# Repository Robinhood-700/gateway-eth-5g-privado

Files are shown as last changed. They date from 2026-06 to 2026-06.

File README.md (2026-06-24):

# Gateway privado Ethernet-5G
Este proyecto contiene el diseño del PCB para la implementación de un gateway privado ethernet-dect, además del firmware correspondiente y un firmware simulado. Además contiene en la carpeta "resultados" la salida del proceso de build, flash y la ejecución del programa.
## Build
A continuación se describe el procedimiento para hacer el build del proyecto.
1. Cambiar de directorio a la carpeta padre del firmware:
```
// (desde la carpeta padre del proyecto)
cd firmware/esp32_gateway 
```
2. Activar el entorno ESP-IDF:
```
// En mi caso instalado en /opt. Cambia al directorio correspondiente $ESP_DIR
source /opt/esp/esp-idf/export.sh 
```
3. Realizar el comando build:
```
idf.py set-target esp32
idf.py reconfigure
idf.py fullclean build
```
### Para guardar el build en un archivo
Para guardar la salida del build en un fichero de texto, simplemente hice un pipe de la salida a un nuevo archivo .txt:
`idf.py fullclean build >> resultado_build.txt`
## Flash
1. Repetir pasos 1 y 2 del proceso build si no se ha ejecutado
```
// (desde la carpeta padre del proyecto)
cd firmware/esp32_gateway 
// En mi caso instalado en /opt. Cambia al directorio correspondiente $ESP_DIR
source /opt/esp/esp-idf/export.sh 
idf.py set-target esp32
idf.py reconfigure
```
2. Realizar el flash
```
// En el caso de mi portatil y la placa de desarrollo ESP32-Ethernet-Kit v1.2, el puerto es el
// /dev/ttyUSB1 y según la documentación de espressif, 115200 es el valor de baudios adecuado
idf.py -p /dev/ttyUSB1 -b 115200 flash monitor
// Este comando concatena el comando monitor con el flash para poder visualizar inmediatamente los resultados en pantalla.
```
### Para guardar el flash en un archivo
Igual que el build, simplemente hace falta un pipe en una terminal de bash:
`idf.py -p /dev/ttyUSB1 -b 115200 flash >> resultado_flash.txt`
### Para guardar la ejecución del programa en un archivo
`idf.py -p /dev/ttyUSB1 -b 115200 monitor >> resultado_monitor.txt`

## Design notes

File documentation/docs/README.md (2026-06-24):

# ESP32 <-> nRF9151 Gateway MVP (KiCad + Firmware minimo)

## Estado
- Proyecto KiCad 9 creado en formato `70 x 50 mm`.
- Esquematico jerarquico con PoE + ESP32 + W5500 + nRF9151.
- Hoja USB integrada: `usb_pc_iface.kicad_sch` (USB-C + CP2102N + auto-programacion).
- Seleccion fisica UART/SPI para nRF9151 por jumpers.
- Definicion minima de puerto USB-C para PC (power + UART + auto-programacion).
- ERC actual del esquema: `0 violaciones`.

## Entregables
1. Hardware minimo: `01_HARDWARE_MIN.md`
2. Pinmap minimo: `02_PINMAP_MIN.md`
3. Firmware minimo (modulos y archivos): `03_FIRMWARE_MIN.md`
4. Kconfig/sdkconfig minimo: carpeta `../../Hardware/firmware/esp32_gateway`
5. Build/flash: `04_BUILD_FLASH.md`
6. Validacion E2E: `05_VALIDACION_E2E.md`
7. Puerto USB PC minimo: `06_USB_PC_PORT_MIN.md`
8. Paquete release KiCad: `../../Hardware/release/README.md`

## Arbol principal
- `../../Hardware/esp32_eth_dect_nrf9151_gateway_min.kicad_sch`
- `../../Hardware/power_poe.kicad_sch`
- `../../Hardware/esp32_eth.kicad_sch`
- `../../Hardware/nrf9151_iface.kicad_sch`
- `../../Hardware/usb_pc_iface.kicad_sch`
- `../../Hardware/esp32_eth_dect_nrf9151_gateway_min.kicad_pcb`
- `../../Hardware/firmware/esp32_gateway`

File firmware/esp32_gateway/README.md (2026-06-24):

# ESP32 Gateway Firmware (Ethernet <-> DECT NR+)

Firmware MVP en ESP-IDF para pasarela bidireccional:
- Ethernet (W5500 por SPI) <-> DECT NR+ (nRF9151 host por UART o SPI)
- Payload siempre en JSON
- Watchdog + reconexion basica de ambos enlaces

## Estructura
- `main/app_main.c`: secuencia de arranque
- `main/Kconfig.projbuild`: configuracion de pines/interfaz/puertos
- `components/gw_eth`: link Ethernet W5500 + estado + restart
- `components/gw_dect`: link DECT host (UART/SPI), AT health-check y RX callback
- `components/gw_json`: validacion JSON y envoltura hex para payload no JSON
- `components/gw_bridge`: bridge UDP ETH->DECT y DECT->UDP
- `components/gw_watchdog`: supervisor de enlace Ethernet/DECT
- `components/gw_diag`: consola de debugging USB + trafico aleatorio de ejemplo

## Flujo
1. UDP RX en `CONFIG_GW_UDP_LISTEN_PORT`.
2. Si llega JSON, se reenvia al enlace DECT; si no es JSON, se encapsula como:
   `{"enc":"hex","data":"..."}`.
3. Datos desde DECT se envian por UDP a:
   - `CONFIG_GW_UDP_REMOTE_IP:CONFIG_GW_UDP_REMOTE_PORT` (si IP fija), o
   - ultimo peer UDP que envio trafico al gateway.

## Debug USB y pruebas
- Consola USB disponible en `idf.py monitor` con prompt `gwdbg>`.
- Comandos principales:
  - `status`, `bridge_stats`, `reset_stats`
  - `at`, `poe`, `set_peer <ip> <port>`
  - `rand_eth <count>`, `rand_dect <count>`
  - `fw_update`, `reboot`
- Scripts host en `tools/usb_debug/`:
  - `flash_usb.sh`: flash + monitor por USB
  - `gateway_usb_debug.py`: comandos USB y test E2E

## Build (ESP-IDF 6.x)
```bash
cd /Users/antonio/Documents/esp32-eth-dect-nrf9151-gateway-hw-docs/kicad_complete_2026-04-22/firmware/esp32_gateway
source $IDF_PATH/export.sh
idf.py set-target esp32
idf.py menuconfig
idf.py build
idf.py -p /dev/ttyUSB0 flash monitor
```

Build UART alternativo (sin tocar build SPI base):
```bash
idf.py -B build-uart -DSDKCONFIG_DEFAULTS='sdkconfig.defaults;sdkconfig.uart' set-target esp32 build
```

## Notas DECT
- `CONFIG_GW_DECT_TX_PREFIX` define prefijo para uplink (`AT+DATA=` por defecto).
- `CONFIG_GW_DECT_RX_PREFIX` define prefijo URC para downlink (`+DATA:` por defecto).
- UART: parser por lineas `\n`.
- SPI: modo polling full-duplex (requiere firmware puente en nRF9151 que exponga stream ASCII por SPI).
- `sdkconfig.uart` incluido para activar UART por software en un build separado.
- `CONFIG_GW_EXAMPLE_RANDOM_ENABLE` habilita generacion automatica de datos aleatorios en ambos sentidos (demo).

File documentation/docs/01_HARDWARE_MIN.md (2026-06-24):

# 01 - Configuracion minima de hardware (70 x 50 mm)

## Alcance de esta revision
- Formato PCB: `70 mm x 50 mm`.
- Bloques incluidos: `PoE 802.3af`, `ESP32`, `Ethernet SPI (W5500)`, `nRF9151`, `USB-C PC (power + UART debug/program)`.
- Bloques excluidos: LTE/LoRa/RS-485/SDI-12/4-20 mA/pulsos/GPS/gestion solar-bateria.

## Diagrama de bloques
1. `RJ45 MagJack PoE` -> `PD 802.3af (Ag9905M)` -> `+5V_POE`
2. `USB-C (PC)` -> fusible -> `+5V_USB`
3. `+5V_POE` OR `+5V_USB` -> `+5V_SYS`
4. `+5V_SYS` -> `Buck 3V3 (R-78B3.3-2.0)` -> `+3V3_SYS`
5. `ESP32-WROOM-32E` alimentado por `+3V3_SYS`
6. `ESP32 SPI1` <-> `W5500`
7. `ESP32` <-> `nRF9151` por `UART` o `SPI` (seleccion por jumpers)
8. `USB-C D+/D-` <-> `CP2102N` <-> `UART0 ESP32` (+ auto-programacion por DTR/RTS)

## Componentes base ya cargados en KiCad
- `U1`: ESP32 `RF_Module:ESP32-WROOM-32E`
- `U2`: W5500 `Package_QFP:LQFP-48_7x7mm_P0.5mm`
- `U3`: nRF9151 (base mecanica) `Package_LGA:Nordic_nRF9160-SIxx_LGA-102-59EP_16.0x10.5mm_P0.5mm`
- `J1`: RJ45 PoE `Connector_RJ:RJ45_Amphenol_RJMG1BD3B8K1ANR`
- `U4`: PD PoE `Ag9905M` (`Converter_DCDC:Converter_DCDC_Silvertel_Ag99xxLP_THT`)
- `U5`: Buck `R-78B3.3-2.0` (`Converter_DCDC:Converter_DCDC_RECOM_R-78B-2.0_THT`)
- `J3`: RF SMA `Connector_Coaxial:SMA_Amphenol_132291_Vertical`
- `J2`: USB-C UFP 16 pines (hoja `usb_pc_iface.kicad_sch`)
- `U6`: USB-UART `CP2102N` (hoja `usb_pc_iface.kicad_sch`)
- `U7`: bloque de auto-programacion (`DTR/RTS` -> `BOOT0/EN`)
- `F2`: fusible `500 mA` para rama `+5V_USB`
- `D7`: Schottky para inyeccion `+5V_USB` hacia rail de sistema 5V
- `R201`, `R202`: `5k1` en `CC1`/`CC2` a GND

## Notas electricas minimas
- Desacoplo minimo por rail: `100 nF` cerca de cada VDD + `10 uF` por bloque.
- Plano de GND continuo bajo ESP32/W5500; keep-out RF para zona de antena de `U3`.
- `PWR_EN` de nRF9151 fijado a `+3V3_SYS` en MVP.
- Si el MagJack seleccionado no integra rectificacion PoE completa, agregar puente de diodos segun hoja de datos del PD.
- USB-C en modo dispositivo/UFP con `CC1` y `CC2` a GND mediante `5.1 kOhm`.
- Recomendado TVS ESD en `D+`/`D-` junto a `J2`.

## Estado de verificacion KiCad
- ERC de esquema: `0 violaciones` (archivo `erc_latest.rpt`).

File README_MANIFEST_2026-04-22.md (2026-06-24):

# KiCad Complete Solution Package (2026-04-22)

Contenido:
- `erc_drc/`: reportes ERC y DRC.
- `schematic/`: PDF de esquema, BOM y netlist.
- `fabrication/gerbers`: Gerbers para fabricación.
- `fabrication/drill`: taladros PTH/NPTH y mapas.
- `fabrication/pos`: archivo Pick&Place (CSV).
- `cad3d/`: exportación STEP y GLB.
- `renders/`: vistas 3D (top, bottom, iso).
- `project_snapshot/`: copia de archivos fuente del proyecto KiCad.
- `documentation/`: documentos técnicos y reportes QARTIA.

Generado con KiCad CLI 9.0.7.

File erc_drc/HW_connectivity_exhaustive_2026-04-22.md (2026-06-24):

# Verificacion HW Exhaustiva - ESP32 <-> Ethernet <-> DECT NR+ (nRF9151)

> Nota 2026-04-22 (recheck): este documento fue superado por `HW_recheck_full_2026-04-22_SPI_option2.md`.
> Estado actual de ensamblaje: SPI fijo por hardware (`SJ201-204=0R_MOUNTED`, `SJ101-104=DNP`).

Fecha: 2026-04-22
Proyecto: `esp32_eth_dect_nrf9151_gateway_min`
Ruta: `kicad_complete_2026-04-22/project_snapshot`

## 1) Resultado global

- DRC PCB: PASS (0 violaciones, 0 pads sin conectar).
- Paridad SCH<->PCB: PASS (0 issues).
- ERC: PASS con warnings no electricos (21 avisos de `footprint_link_issues` por simbolos de libreria local con `lib ""`).
- Conectividad de pads a net en PCB: PASS (0 pads en net 0 para footprints electricos).

## 2) Evidencia automatica

Archivos generados:

- `kicad_complete_2026-04-22/erc_drc/erc_exhaustive_2026-04-22.rpt`
- `kicad_complete_2026-04-22/erc_drc/drc_exhaustive_2026-04-22.rpt`
- `kicad_complete_2026-04-22/erc_drc/drc_exhaustive_parity_2026-04-22.rpt`
- `kicad_complete_2026-04-22/erc_drc/netlist_exhaustive_2026-04-22.net`

## 3) Matriz de conectividad por subsistema

### 3.1 Power PoE + Arbol de alimentacion

PASS - cadena validada:

- J1 PoE: `POE_VP/POE_VN` conectados a U4 `VIN+`/`VIN-`.
- U4 salida `+5V_POE` conectada a U5 `VIN`.
- U5 `VOUT` genera `+3V3_SYS` para U1/U2/U3/U6/U7.

Nets clave (netlist):

- `+5V_POE`: D7-K, U4(+VDC_1,+VDC_2), U5-VIN.
- `POE_VP`: J1-5, U4-5, U4-6.
- `POE_VN`: J1-6, U4-7, U4-8.
- `+3V3_SYS`: U1-1, U2-1, U3-1/U3-16, U5-3, U6-5, U7-3.

### 3.2 USB PC (alimentacion + debug + auto-program)

PASS - rutas validadas:

- `+5V_USB_RAW`: J2-VBUS -> F2-IN.
- `+5V_USB`: F2-OUT -> U6-VBUS -> D7-A.
- OR-ing a rail de sistema: D7-K -> `+5V_POE`.
- USB datos: J2 D+/D- -> U6 USB_DP/USB_DM.
- UART debug ESP32: U6 TXD/RXD -> ESP_U0RXD/ESP_U0TXD.
- Auto-program: U6 DTR/RTS -> U7 -> ESP_BOOT0/ESP_EN.

### 3.3 Ethernet gateway

PASS - enlace fisico + host SPI validados:

- U1 <-> U2 por SPI1 (`SCLK/MISO/MOSI/CS_N`) + `ETH_INT_N` + `ETH_RST_N`.
- U2 <-> J1 por pares Ethernet (`ETH_TXP/TXN/RXP/RXN`).

Metrica de routing (aprox por segmentos):

- TX+: ~50.0 mm, TX-: ~51.7 mm (desfase ~1.7 mm).
- RX+: ~54.0 mm, RX-: ~55.5 mm (desfase ~1.5 mm).

### 3.4 DECT NR+ (nRF9151)

PASS (software-selectable con enlaces montados):

- U3 alimentacion y control: `+3V3_SYS`, `GND`, `NRF_IRQ`, `NRF_RST_N`.
- U3 UART y SPI presentes en nets dedicadas.
- Enlaces de interfaz configurados como `0R_MOUNTED` en SJ101..SJ104 y SJ201..SJ204 para habilitar ambas rutas en hardware.
- Seleccion final del canal por firmware (UART o SPI) sin rework de jumpers.

### 3.5 RF antena DECT

PASS CONDICIONAL (matching final de produccion):

- Topologia Pi presente: C301 (shunt) - L301 (serie) - C302 (shunt).
- Conector SMA externo J3 con GND conectado (pin 2 a GND).
- Neta RF separada en dos tramos: `DECT_RF` y `DECT_RF_ANT`.
- Reglas RF activas (DRU):
  - ancho 0.45 mm en `DECT_RF` y `DECT_RF_ANT`.
  - sin vias RF.
  - clearance minimo RF.
- Verificacion de layout:
  - segmentos RF en 0.45 mm (cumple).
  - vias RF: no detectadas (cumple).

Keep-out antena:

- Keepout cobre/vias/tracks bajo antena en las 4 capas (`F.Cu`, `In1.Cu`, `In2.Cu`, `B.Cu`).

## 4) Comprobacion de pads/componentes en PCB

Resumen footprints electricos parseados:

- 25 footprints electricos detectados.
- Todos los pads tienen net asignada distinta de net 0.
- Sin pads unconnected segun DRC.

## 5) Riesgos residuales / acciones obligatorias antes de fabricacion

1. IMPORTANTE: huellas/simbolos placeholder en bloques principales (U1/U2/U3/J1/J2/U4/U5/U6/U7).
   - La conectividad logica/EDA es consistente, pero no valida por si sola pinout mecanico final de componentes reales.
   - Accion: congelar footprints finales manufacturer-accurate y rerun ERC/DRC/paridad.

2. IMPORTANTE: SWD de nRF9151 (`SWDIO`/`SWDCLK`) quedan en nets de un solo nodo (sin header/testpoint).
   - Accion recomendada: agregar header/testpads SWD si se requiere debug/programacion nRF in-circuit.

3. IMPORTANTE RF: C301/C302 estan como DNP (correcto para tuning inicial), pero requiere plan de ajuste VNA.
   - Accion: definir ventana de componentes de matching y procedimiento de tuning en EVT.

## 6) Conclusión de verificación

- La conectividad HW del diseño actual queda validada a nivel EDA (esquematico+PCB) para:
  - Gateway Ethernet <-> ESP32 <-> nRF9151 (DECT NR+).
  - Alimentacion PoE + inyeccion USB.
  - Puerto USB de alimentacion/debug/autoprogramacion ESP32.
  - Camino RF con reglas y keepouts definidos.

- El diseño es funcionalmente coherente para prototipo, con condiciones de montaje (jumpers + L301 poblado) y con riesgos de industrializacion pendientes (footprints finales reales y tuning RF).

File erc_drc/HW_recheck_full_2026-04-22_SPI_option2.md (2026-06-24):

# Recheck HW completo (SPI opción 2)

Fecha: 2026-04-22
Proyecto: `esp32_eth_dect_nrf9151_gateway_min`

## 1) Estado global EDA

- DRC PCB: PASS (0 violaciones, 0 pads sin conectar)
  - `erc_drc/drc_recheck_full_2026-04-22.rpt`
- DRC Paridad SCH/PCB: PASS (0 issues)
  - `erc_drc/drc_recheck_full_parity_2026-04-22.rpt`
- ERC SCH: PASS eléctrico con warnings no funcionales de librería (`footprint_link_issues`, 21)
  - `erc_drc/erc_recheck_full_2026-04-22.rpt`

## 2) Comprobación de conexiones por funcionalidad

### A) Gateway Ethernet (ESP32 <-> W5500 <-> RJ45)

PASS

- `ESP_SPI1_SCLK/MISO/MOSI/CS_N`: U1 <-> U2
- `ETH_INT_N`, `ETH_RST_N`: U1 <-> U2
- `ETH_TXP/TXN`, `ETH_RXP/RXN`: U2 <-> J1

Longitudes aproximadas (suma de segmentos PCB):
- `ETH_TXP`: 50.0 mm
- `ETH_TXN`: 51.7 mm (skew TX: 1.7 mm)
- `ETH_RXP`: 54.0 mm
- `ETH_RXN`: 55.5 mm (skew RX: 1.5 mm)

### B) PoE + árbol de alimentación

PASS

- J1 PoE: `POE_VP/POE_VN` -> U4 (PD 802.3af)
- U4 salida -> `+5V_POE`
- U5: `+5V_POE` -> `+3V3_SYS`
- OR-ing con USB: D7 (`+5V_USB` -> `+5V_POE`)

### C) USB PC (alimentación + debug + auto-program)

PASS

- J2 VBUS -> F2 -> `+5V_USB`
- J2 D+/D- -> U6 (`USB_DP/USB_DM`)
- U6 UART -> ESP32: `ESP_U0RXD`, `ESP_U0TXD`
- U6 `USB_DTR/USB_RTS` -> U7 -> `ESP_BOOT0/ESP_EN`

### D) nRF9151 (DECT NR+) control host

PASS (forzado a SPI por ensamblaje)

- SPI activo (puentes montados):
  - `SJ201=0R_MOUNTED` (`ESP_SPI2_SCLK` <-> `NRF_SPI_SCLK`)
  - `SJ202=0R_MOUNTED` (`ESP_SPI2_MISO` <-> `NRF_SPI_MISO`)
  - `SJ203=0R_MOUNTED` (`ESP_SPI2_MOSI` <-> `NRF_SPI_MOSI`)
  - `SJ204=0R_MOUNTED` (`ESP_SPI2_CS_N` <-> `NRF_SPI_CSN`)
- UART deshabilitado por ensamblaje:
  - `SJ101..SJ104 = DNP`

### E) RF DECT + antena externa

PASS (layout/conectividad)

- Cadena RF: U3 `DECT_RF` -> L301 (0R montado) -> `DECT_RF_ANT` -> J3 SMA
- Pi-network presente con shunts DNP:
  - `C301 = DNP` (`DECT_RF` a GND)
  - `C302 = DNP` (`DECT_RF_ANT` a GND)
- Reglas RF observadas:
  - width RF detectado: 0.45 mm
  - vias en nets RF: 0
  - keep-out antena presente en 4 capas: `F.Cu`, `In1.Cu`, `In2.Cu`, `B.Cu`

## 3) Conclusión

Conectividad HW y funcionalidades mínimas quedan validadas a nivel de diseño (SCH/PCB) para:
- Ethernet gateway
- PoE + USB power/debug
- nRF9151 en SPI (opción 2 fija)
- Ruta RF hacia SMA externa

Nota: esta verificación es EDA (diseño). No sustituye pruebas en banco (link Ethernet real, tráfico SPI real, RSSI/cobertura de antena en campo).

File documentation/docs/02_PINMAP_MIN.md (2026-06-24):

# 02 - Pinmap minimo

## Ethernet W5500 (SPI dedicado)
- `GPIO18` -> `W5500_SCLK`
- `GPIO19` <- `W5500_MISO`
- `GPIO23` -> `W5500_MOSI`
- `GPIO21` -> `W5500_CS`
- `GPIO22` <- `W5500_INT`
- `GPIO2`  -> `W5500_RST`

## nRF9151 opcion UART (MVP recomendado)
- `GPIO17` ESP32 TX -> nRF9151 RX
- `GPIO16` ESP32 RX <- nRF9151 TX
- `GPIO14` ESP32 RTS -> nRF9151 CTS (opcional)
- `GPIO15` ESP32 CTS <- nRF9151 RTS (opcional)
- `GPIO4`  -> `NRF_RST`
- `GPIO27` <- `NRF_IRQ`

## nRF9151 opcion SPI (requiere FW puente)
- `GPIO25` -> `NRF_SPI_SCLK`
- `GPIO34` <- `NRF_SPI_MISO`
- `GPIO32` -> `NRF_SPI_MOSI`
- `GPIO33` -> `NRF_SPI_CS`
- `GPIO4`  -> `NRF_RST` (por defecto en firmware; configurable)
- `GPIO27` <- `NRF_IRQ`

## USB-UART para PC (programacion + logs)
- `CP2102N_TXD` -> `GPIO3/U0RXD` (ESP32)
- `CP2102N_RXD` <- `GPIO1/U0TXD` (ESP32)
- `DTR` (CP2102N) -> `GPIO0/BOOT` mediante transistor NPN
- `RTS` (CP2102N) -> `EN/CHIP_PU` mediante transistor NPN
- `GPIO0`: pull-up `10k` a `3V3`
- `EN`: pull-up `10k` a `3V3` y `1uF` a GND

## Seleccion fisica UART/SPI en hardware
- UART activo por defecto: `SJ101-SJ104` cerrados.
- SPI inactivo por defecto: `SJ201-SJ204` abiertos.
- Para SPI: abrir `SJ101-SJ104` y cerrar `SJ201-SJ204`.

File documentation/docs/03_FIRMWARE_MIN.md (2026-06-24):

# 03 - Firmware minimo (ESP-IDF)

## Ubicacion
- Proyecto: `kicad_complete_2026-04-22/firmware/esp32_gateway`

## Modulos y archivos
- `main/app_main.c`
  - Inicializa NVS, red (`esp_netif` + event loop), Ethernet, DECT, bridge y supervisor.
- `components/gw_eth/gw_eth.c/.h`
  - Driver W5500 por SPI (ESP-IDF 6.x con `espressif/w5500`).
  - Estado de enlace/IP y reinicio basico del enlace Ethernet.
- `components/gw_dect/gw_dect.c/.h`
  - Enlace host ESP32 <-> nRF9151 seleccionable por software: `UART` o `SPI`.
  - Comando AT de healthcheck (`AT` + espera de `OK`).
  - TX con prefijo configurable (`CONFIG_GW_DECT_TX_PREFIX`, default `AT+DATA=`).
  - RX con filtro por prefijo configurable (`CONFIG_GW_DECT_RX_PREFIX`, default `+DATA:`).
- `components/gw_bridge/gw_bridge.c/.h`
  - Tarea `Ethernet UDP -> DECT`.
  - Tarea `DECT -> Ethernet UDP`.
  - Mecanismo de peer remoto fijo o dinamico (ultimo emisor UDP).
- `components/gw_json/gw_json.c/.h`
  - Valida JSON de entrada.
  - Si no es JSON, encapsula como `{"enc":"hex","data":"..."}`.
- `components/gw_watchdog/gw_watchdog.c/.h`
  - Supervisor periodico de Ethernet y DECT con reconexion basica.
- `components/gw_diag/gw_diag.c/.h`
  - Consola de debugging por USB (`gwdbg`).
  - Comandos de prueba para Ethernet, DECT, PoE, estadisticas del bridge.
  - Generador de datos aleatorios de ejemplo en ambos sentidos.
- `main/Kconfig.projbuild`
  - Configuracion minima (pines, puertos UDP, timeouts, interfaz UART/SPI).
- `main/idf_component.yml`
  - Dependencia gestionada: `espressif/w5500`.

## Flujo de datos (MVP)
1. Ethernet recibe UDP en `CONFIG_GW_UDP_LISTEN_PORT` (default `5000`).
2. Se garantiza salida JSON hacia DECT:
   - JSON valido: pasa directo.
   - No JSON/binario: encapsulado hex.
3. Mensajes DECT recibidos (prefijo RX configurado) se envian por UDP Ethernet.
4. Tambien se garantiza salida JSON hacia Ethernet:
   - JSON valido: pasa directo.
   - No JSON/binario: encapsulado hex.
5. Destino UDP de salida:
   - `CONFIG_GW_UDP_REMOTE_IP` vacio: ultimo peer UDP visto.
   - `CONFIG_GW_UDP_REMOTE_IP` definido: peer fijo + `CONFIG_GW_UDP_REMOTE_PORT`.

## Seleccion UART/SPI por software
- Via `idf.py menuconfig`:
  - `Gateway MVP configuration` -> `nRF9151 host interface` -> `UART` o `SPI`.
- Alternativa automatizada:
  - Overlay `sdkconfig.uart` para generar build UART sin tocar la configuracion base SPI.

## Watchdog y reconexion
- Supervisor periodico cada `CONFIG_GW_SUPERVISOR_PERIOD_MS`.
- Si Ethernet cae mas de `CONFIG_GW_ETH_RESTART_SEC`, reinicia W5500.
- Si fallan healthchecks AT consecutivos, reinicia enlace DECT.

## Debug USB y trafico aleatorio de ejemplo
- Consola por USB-UART con prompt `gwdbg>`.
- Comandos:
  - `status`, `bridge_stats`, `reset_stats`
  - `at`, `poe`
  - `set_peer <ipv4> <port>`
  - `rand_eth <count>` (simula ingreso por Ethernet UDP)
  - `rand_dect <count>` (simula ingreso por DECT)
  - `fw_update`, `reboot`
- Configuracion relevante:
  - `CONFIG_GW_USB_DEBUG_ENABLE`
  - `CONFIG_GW_POE_PGOOD_GPIO` / `CONFIG_GW_POE_PGOOD_ACTIVE_LEVEL`
  - `CONFIG_GW_EXAMPLE_RANDOM_ENABLE` y parametros de burst/periodo

## Suposiciones del lado nRF9151
- UART: firmware del nRF9151 responde `OK` al comando `AT`.
- SPI: firmware puente propietario (stream ASCII por SPI) para encapsular comandos AT/URC.

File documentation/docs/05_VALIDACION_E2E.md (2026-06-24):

# 05 - Pruebas de validacion E2E

## Preparacion
- Pasarela energizada por PoE (`802.3af`) y conectada a LAN con DHCP.
- nRF9151 conectado y con firmware AT operativo (UART o SPI segun `menuconfig`).
- PC de prueba en la misma LAN.

## T1 - Ethernet con IP valida
1. Arrancar pasarela.
2. Verificar en logs `Ethernet link up` + `Ethernet got IP`.
3. Criterio OK: IP IPv4 asignada y estable.

## T1b - Alimentacion PoE (PGOOD)
1. Configurar `CONFIG_GW_POE_PGOOD_GPIO` al pin de power-good del PD.
2. En consola USB (`gwdbg>`) ejecutar:
   - `poe`
3. Criterio OK: `result=ok`.

## T2 - Enlace nRF9151 y AT
1. Verificar log de `AT link validated`.
2. Forzar reset nRF9151 (hardware o comando) y esperar reconexion.
3. Criterio OK: supervisor detecta fallo AT y recupera enlace.

## T3 - Ethernet -> nRF9151 (JSON)
1. Desde PC enviar UDP JSON:
```bash
echo '{"dir":"eth_to_nrf","seq":1}' | nc -u -w1 <IP_GATEWAY> 5000
```
2. Criterio OK: log de forward sin error hacia nRF9151.

## T4 - nRF9151 -> Ethernet (JSON)
1. Inyectar desde nRF9151 una linea con prefijo configurado (default `+DATA:`), por ejemplo:
   - `+DATA:{"dir":"nrf_to_eth","seq":1}`
2. Escuchar en PC:
```bash
nc -u -l 5000
```
3. Criterio OK: JSON recibido en PC.

## T5 - Resiliencia basica
1. Desconectar cable Ethernet 10 s y reconectar.
2. Criterio OK: recuperación de link/IP y continuidad de bridge.
3. Bloquear temporalmente respuesta AT del nRF9151.
4. Criterio OK: reinicializacion automatica del enlace nRF.

## T6 - Integridad JSON
1. Enviar payload no JSON por UDP.
2. Criterio OK: payload reenviado encapsulado como:
   - `{"enc":"hex","data":"..."}`

## T7 - Script E2E automatizado (USB + Ethernet)
1. Instalar dependencia:
```bash
pip install pyserial
```
2. Ejecutar:
```bash
python3 firmware/esp32_gateway/tools/usb_debug/gateway_usb_debug.py e2e \
  --serial /dev/ttyUSB0 \
  --gateway-ip <IP_GATEWAY> \
  --listen-port 5000 \
  --remote-port 5000 \
  --count 20
```
3. Criterio OK:
   - `ETH->DECT forwarded` >= `count`
   - `DECT->ETH UDP received` >= `count`
   - `RESULT: PASS`

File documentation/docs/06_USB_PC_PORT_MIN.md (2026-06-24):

# 06 - Puerto USB minimo para PC (alimentacion + debug/programacion)

## Objetivo
Un unico conector USB-C para:
- alimentar placa desde PC (`+5V_USB`), y
- programar/depurar por UART (`CP2102N` <-> `UART0 ESP32`).

## Configuracion minima
1. `J2` USB-C UFP
- `CC1` -> `5.1k` -> GND
- `CC2` -> `5.1k` -> GND
- `VBUS` -> `F2` (500 mA) -> `+5V_USB`
- `D+`/`D-` -> `U6 CP2102N D+`/`D-`

2. OR-ing de alimentacion
- `D6` Schottky: `+5V_POE -> +5V_SYS`
- `D7` Schottky: `+5V_USB -> +5V_SYS`

3. USB-UART
- `CP2102N_TXD` -> `ESP32 U0RXD (GPIO3)`
- `CP2102N_RXD` <- `ESP32 U0TXD (GPIO1)`

4. Auto-programacion ESP32
- `DTR` -> transistor NPN -> `GPIO0`
- `RTS` -> transistor NPN -> `EN`
- `GPIO0` con pull-up `10k` a `3V3`
- `EN` con pull-up `10k` a `3V3` + `1uF` a GND

## Resultado esperado en PC
- Puerto serie para `idf.py flash monitor`
- Flash automatico sin pulsar botones
- Alimentacion alternativa por USB cuando no hay PoE

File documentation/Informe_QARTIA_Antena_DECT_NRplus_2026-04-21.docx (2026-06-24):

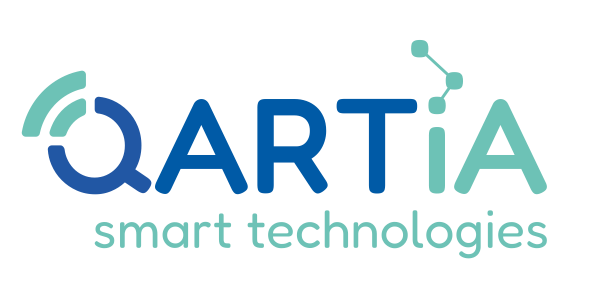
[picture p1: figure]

# Informe Técnico RF - Formato QARTIA

Pasarela mínima ESP32 Ethernet <-> DECT NR+ (nRF9151) con PoE 802.3af

Antena, diseño RF, componentes, estudios de eficiencia y prestaciones

Fecha: 23/04/2026
Versión: 2026-04-23 / RF-ANT-02
Formato PCB: 70 x 50 mm, 4 capas

# 1. Resumen Ejecutivo

Se documenta la solución RF completa de la pasarela DECT NR+ basada en nRF9151 y antena omnidireccional exterior por SMA. El diseño implementado en PCB cumple 4 capas, reglas de pista RF a 50 ohm, keep-out completo bajo zona de antena y red pi de matching para ajuste fino en 1880-1920 MHz.

Con potencia de transmisión fija en 19 dBm, la cadena propuesta entrega una EIRP estimada de 24.98 dBm, con eficiencia de conducción aproximada del 79.1% (antes de ajuste VNA final).

# 2. Alcance y Base Documental

- Proyecto: esp32_eth_dect_nrf9151_gateway_min_70x50.
- Objetivo: maximizar cobertura DECT NR+ manteniendo TX fija de 19 dBm.
- Arquitectura: nRF9151 -> red pi -> SMA PCB -> cable coaxial -> protector -> antena omni exterior.
- Documentos de base: BOM release, reglas DRC/DRU, render 3D con SMA, validación E2E.

# 3. Diseño de Antena y Cadena RF Implementada

Topología RF final en placa:

- U3 (nRF9151) salida RF net DECT_RF.
- Red pi en 0402: C301 (shunt), L301 (serie), C302 (shunt).
- Conector J3 SMA vertical Amphenol 132291 hacia antena exterior omnidireccional.
- Keep-out completo bajo antena en F.Cu, In1.Cu, In2.Cu y B.Cu.
- Guía mecánica ANT_CLEARANCE_5MM definida en Dwgs.User.

Vista superior de la PCB con salida SMA:

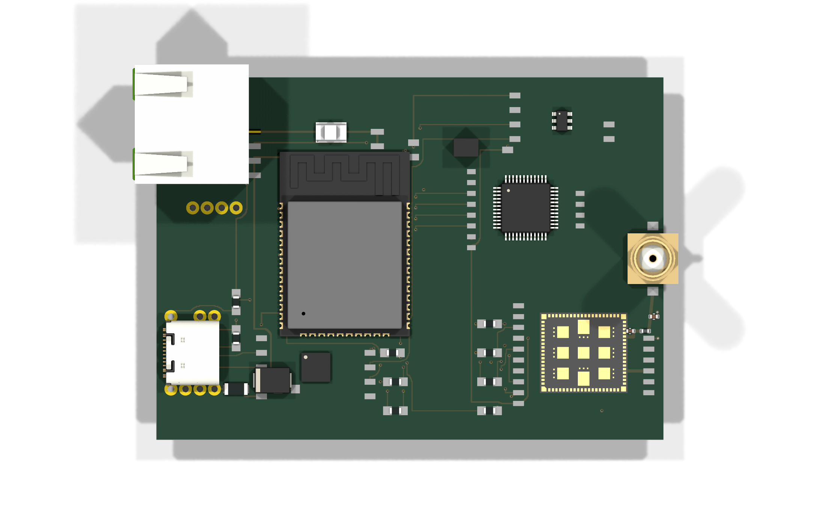
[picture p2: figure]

Vista isométrica de integración 3D:

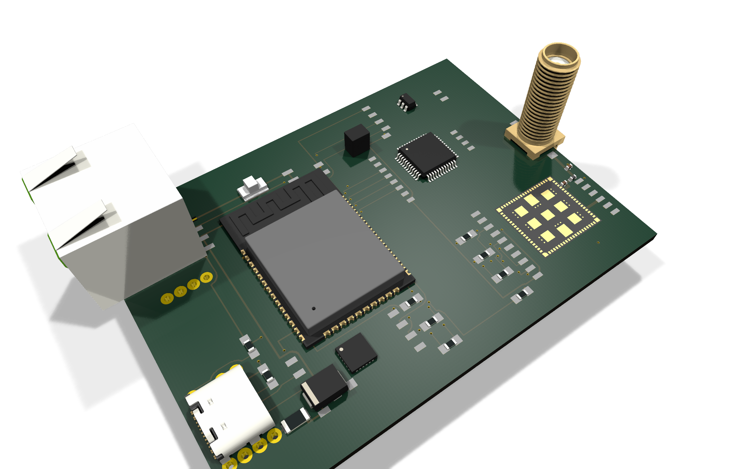
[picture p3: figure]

# 4. Reglas de Layout RF y Estado de Verificación

Reglas aplicadas en el diseño (archivo .kicad_dru y PCB):

Regla | Valor | Estado
Ancho de pista RF (DECT_RF/DECT_RF_ANT) | 0.45 mm fijo | Implementado
Clearance mínimo RF | 0.20 mm | Implementado
Vías en net RF | No permitidas | Implementado
Keep-out bajo antena | Completo en 4 capas | Implementado
Separación libre alrededor antena | 5 mm (mínimo actual) | Implementado
Plano de masa útil | >= 50 mm equivalente en PCB 70x50 | Cumplido por geometría
DRC final | 0 violaciones / 0 unconnected | OK (2026-04-21)

# 5. BOM RF (Placa + Instalación Exterior)

5.1 Componentes RF en PCB

Referencia | Componente | Función | Observación
U3 | nRF9151-SICA | Módem DECT NR+ (TX fija 19 dBm) | Control por UART/SPI desde ESP32
J3 | SMA_Amphenol_132291_Vertical | Salida RF a antena externa | Footprint final en release
C301 | 0402 DNP | Shunt red pi lado módem | Ajuste con VNA en pre-serie
L301 | 0402 0R_DNP | Serie red pi | Inicialmente 0 ohm / configurable
C302 | 0402 DNP | Shunt red pi lado antena | Ajuste de matching

5.2 Componentes RF de instalación exterior (BOM propuesto)

Elemento | Referencia propuesta | Parámetros clave
Antena omni exterior | HUBER+SUHNER 1319.17.0121 | 1880-1930 MHz, ~7 dBi, VSWR ~1.5
Protector coaxial | PolyPhaser DGXZ+15NMNF-A | Protección descarga/sobretensión, baja pérdida
Cable coaxial | Times Microwave LMR-400-DB | Baja atenuación en 1.9 GHz
Conectores coaxial | EZ-400-SM-X / EZ-400-NMH-X | Compatibles con LMR-400
Kit de tierra | GK-S400TT | Puesta a tierra malla/coaxial
Sellado intemperie | 3M Scotch 23 + Super 33+ | Protección de uniones exteriores

# 6. Estudio de Eficiencia y Potencia de Transmisión

Potencia configurada de transmisión del nRF9151: 19.0 dBm (fija).

Elemento de la cadena TX | Pérdida estimada (dB)
Pista RF + transición PCB + red pi (sin ajuste VNA) | 0.20
Conector SMA en PCB (J3) | 0.04
Protector coaxial (PolyPhaser DGXZ+15NMNF-A) | 0.10
Cable LMR-400-DB (2 m a ~1.9 GHz) | 0.38
Conectores/adaptadores de cable | 0.30
TOTAL | 1.02

Potencia a entrada de antena = P_TX - pérdidas = 19.0 - 1.02 = 17.98 dBm.

EIRP estimada = P_antena + G_antena = 17.98 + 7.0 = 24.98 dBm.

Eficiencia de conducción de cadena RF = 10^(-L/10) = 79.1%.

Pérdida por desadaptación de antena para VSWR~1.5: 0.18 dB (eficiencia por mismatch ~96.0%).

Nota: los valores son de ingeniería previa a la fase de ajuste VNA en placa real. El ajuste fino de la red pi puede recuperar margen adicional de enlace.

# 7. Estudio de Cobertura (Estimación)

Modelo utilizado: log-distance en 1.9 GHz con pérdidas de implementación y margen por escenario. Sensibilidades representativas por modo de operación DECT NR+ (robusto, balanceado y alta tasa).

Escenario | n | Margen (dB) | Robusto (-108 dBm) | Balanceado (-103 dBm) | Alta tasa (-98 dBm)
LOS abierto | 2.1 | 10 | 13103 m | 7573 m | 4377 m
Suburbano / mixto | 2.7 | 15 | 1040 m | 679 m | 443 m
Interior industrial (NLOS) | 3.3 | 20 | 208 m | 146 m | 103 m

Interpretación práctica:

- Exterior abierto (LOS): alcance potencial en kilómetros, condicionado por altura, despeje Fresnel e interferencia local.
- Suburbano/mixto: orden de cientos de metros a ~1 km según modo de enlace.
- Interior industrial: orden de ~100 a ~200 m, dependiente de estructuras metálicas y multipath.

# 8. Prestaciones Esperadas y Mejora Frente a Antena Integrada

Indicador | Resultado esperado
EIRP gateway | ~25.0 dBm
Eficiencia cadena TX (sin mismatch) | ~79%
Ganancia de antena | ~7 dBi (omni exterior)
Robustez mecánica RF | Alta (SMA + cable + sellado)
Cobertura | Incremento significativo vs antena chip de placa

Conclusión de prestaciones: con TX fija a 19 dBm, la mejora de cobertura se logra por mayor ganancia efectiva de antena y menores pérdidas de desintonía respecto a soluciones integradas compactas.

# 9. Riesgos Técnicos y Mitigaciones

- Riesgo: desajuste final de impedancia por tolerancias PCB/caja/cable. Mitigación: ajuste VNA de C301/L301/C302 en prototipo.
- Riesgo: degradación por instalación exterior deficiente. Mitigación: protector + puesta a tierra + sellado doble capa.
- Riesgo: pérdidas extras por adaptadores no controlados. Mitigación: minimizar transiciones y estandarizar conectores.
- Riesgo: entorno industrial hostil (NLOS severo). Mitigación: elevar antena, optimizar ubicación y verificar RSSI/BLER en site survey.

# 10. Plan de Validación Recomendado (RF)

Prueba | Objetivo | Criterio de aceptación
VNA S11 1880-1920 MHz | Ajustar red pi | Retorno <= -10 dB en banda objetivo
Potencia conducida | Verificar TX del nRF9151 | 19 dBm configurados, dentro de tolerancia
Potencia radiada/EIRP | Validar cadena completa | Consistente con ~25.0 dBm estimado
Cobertura en campo | Cuantificar alcance real | Cumplir rango mínimo definido por caso de uso
Robustez intemperie | Verificar instalación | Sin degradación tras ciclo ambiental básico

# 11. Anexo A - Pinmap Mínimo de Interfaz con nRF9151

Opción UART (MVP): GPIO17->RX, GPIO16<-TX, GPIO14->CTS(opc), GPIO15<-RTS(opc), GPIO4->RST, GPIO27<-IRQ.

Opción SPI: GPIO25->SCLK, GPIO34<-MISO, GPIO32->MOSI, GPIO33->CS, GPIO4->RST, GPIO27<-IRQ.

Selección física por jumpers: UART por defecto (SJ101-104 cerrados), SPI alternativo (SJ201-204 cerrados).

# 12. Anexo B - Evidencias de Proyecto

- BOM release: release/bom.csv
- DRC limpio: release/drc_after_sma_omni_change.rpt (0/0/0).
- Reglas RF: esp32_eth_dect_nrf9151_gateway_min.kicad_dru.
- Render 3D: release/fab_2026-04-21/3d/render_top_sma_omni.png y render_iso_sma_omni.png.

# 13. Fuentes Técnicas

- nRF9151 DECT NR+: Nordic Semiconductor (Product/PS).
- Antena omni: HUBER+SUHNER 1319.17.0121 datasheet.
- Cable coaxial: Times Microwave LMR-400 datasheet.
- Protector coaxial: PolyPhaser DGXZ+15NMNF-A datasheet.
- Conector SMA PCB: Amphenol 132291 datasheet.

14. Actualización RF y de Integración 3D (22-23/04/2026)

Resumen RF consolidado con avances de ayer (22/04/2026) y hoy (23/04/2026):

La arquitectura RF de referencia se mantiene: nRF9151 -> red pi (C301/L301/C302) -> SMA -> coaxial/protección -> antena omni exterior.

Se confirma mantenimiento del criterio de TX fija en 19 dBm y la base de cálculo de EIRP documentada en esta memoria RF.

La actualización de hardware incorpora TP301/TP302 de depuración SWD sin cambios en la cadena RF ni en la geometría de la zona de antena.

Estado EDA asociado a la revisión RF integrada (2026-04-22 23:13): DRC 0/0/0 y paridad esquema-PCB en 0 incidencias.

Los avisos ERC observados son de enlace de librerías de footprints (no de conectividad eléctrica funcional).

Se regeneraron modelos STEP/GLB de inspección para verificación de integración mecánica y de cobre asociado al enrutado.

El 23/04/2026 se realizó limpieza de nombres de nodos auxiliares en GLB para visualización inequívoca de componentes reales.

Impacto RF esperado de esta actualización: neutro/positivo en trazabilidad; no modifica la estimación de eficiencia ni cobertura previa.

Trazabilidad GitHub RF/3D: v2026.04.22.5 y v2026.04.22.6.

Recomendación mantenida: ajuste final de red pi con VNA sobre prototipo ensamblado antes de congelar valores C301/L301/C302.

QARTIA · Documento técnico

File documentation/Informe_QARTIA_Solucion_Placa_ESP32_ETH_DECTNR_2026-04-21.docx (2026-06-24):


# Informe Técnico de la Solución de la Placa

ESP32 + Ethernet (W5500 SPI) + nRF9151 DECT NR+ + PoE 802.3af

Fecha: 23/04/2026

Formato: QARTIA

Revisión: 2026-04-23

# 1 Resumen Ejecutivo

Este documento consolida la solución completa de la placa 70 x 50 mm a 4 capas para pasarela mínima Ethernet <-> DECT NR+ controlada por ESP32, con alimentación PoE 802.3af y soporte USB-C para programación/depuración.

La cadena RF final utiliza salida SMA externa con red pi de adaptación y reglas de trazado de 50 ohm. Con TX fija de 19.0 dBm en nRF9151, la EIRP estimada del sistema con antena omni exterior es de 24.98 dBm (modelo).

# 2. Alcance y Archivos de Salida

- Incluye: hardware, interconexiones, RF/layout, validación EDA, fabricación, simulación y trazabilidad.
- No incluye mediciones de cámara anecoica ni drive test de campo; los resultados RF de este documento son de simulación de ingeniería.
- Archivo principal generado: /Users/antonio/Documents/KiCad/9.0/projects/esp32_eth_dect_nrf9151_gateway_min_70x50/release/qartia_report_2026-04-21/Informe_QARTIA_Solucion_Placa_ESP32_ETH_DECTNR_2026-04-21.docx
- Anexo de referencia: /Users/antonio/Documents/KiCad/9.0/projects/esp32_eth_dect_nrf9151_gateway_min_70x50/release/Informe_QARTIA_Antena_DECT_NRplus_2026-04-21.docx

## 2.1 MATERIALES Y METODOS. BIBLIOGRAFIA

Materiales y métodos:

- Revisión de artefactos KiCad: esquemáticos, PCB, reglas DRU, reportes DRC/ERC, BOM y paquete de fabricación.
- Extracción de parámetros eléctricos desde archivos del proyecto y cálculo de presupuestos de enlace RF.
- Simulación analítica S11/VSWR y RSSI-distancia basada en modelos log-distance y pérdidas de cadena.

Bibliografía técnica principal:

- Nordic nRF9151 Product Specification / documentación DECT NR+ (fabricante).
- Datasheet antena HUBER+SUHNER 1319.17.0121 (1880-1930 MHz).
- Datasheet cable Times Microwave LMR-400.
- Datasheet protector PolyPhaser DGXZ+15NMNF-A.
- Datasheet conector SMA Amphenol 132291.

# 3. Datos Mecánicos y de Apilado (Stackup PCB)

Parámetro | Valor
Dimensiones de placa | 70 x 50 mm
Área | 3500 mm²
Espesor PCB | 1.60 mm
Número de capas de cobre | 4
Capas señal declaradas | F.Cu / In1.Cu / In2.Cu / B.Cu
Perímetro | Rectangular, definido en Edge.Cuts

Capas detectadas en archivo PCB:

- F.Cu (signal)
- In1.Cu (signal)
- In2.Cu (signal)
- B.Cu (signal)
- F.Adhes (user)
- B.Adhes (user)
- F.Paste (user)
- B.Paste (user)
- F.SilkS (user)
- B.SilkS (user)
- F.Mask (user)
- B.Mask (user)

# 4. Inventario de Componentes

Inventario extraído de BOM release (22 referencias):

Refs | Value | Footprint
D7 | SS34 | Diode_SMD:D_SMB
F2 | 500mA | Fuse:Fuse_1206_3216Metric
J1 | RJ45_POE | Connector_RJ:RJ45_Amphenol_RJMG1BD3B8K1ANR
J2 | USB_C_PC | Connector_USB:USB_C_Receptacle_HRO_TYPE-C-31-M-12
J3 | DECT_ANT | Connector_Coaxial:SMA_Amphenol_132291_Vertical
R201 | 5k1 | Resistor_SMD:R_0603_1608Metric
R202 | 5k1 | Resistor_SMD:R_0603_1608Metric
SJ101 | IF_LINK | Jumper:SolderJumper-2_P1.3mm_Bridged_Pad1.0x1.5mm
SJ102 | IF_LINK | Jumper:SolderJumper-2_P1.3mm_Bridged_Pad1.0x1.5mm
SJ103 | IF_LINK | Jumper:SolderJumper-2_P1.3mm_Bridged_Pad1.0x1.5mm
SJ104 | IF_LINK | Jumper:SolderJumper-2_P1.3mm_Bridged_Pad1.0x1.5mm
SJ201 | IF_LINK | Jumper:SolderJumper-2_P1.3mm_Open_Pad1.0x1.5mm
SJ202 | IF_LINK | Jumper:SolderJumper-2_P1.3mm_Open_Pad1.0x1.5mm
SJ203 | IF_LINK | Jumper:SolderJumper-2_P1.3mm_Open_Pad1.0x1.5mm
SJ204 | IF_LINK | Jumper:SolderJumper-2_P1.3mm_Open_Pad1.0x1.5mm
U1 | ESP32-WROOM-32E | RF_Module:ESP32-WROOM-32E
U2 | W5500 | Package_QFP:LQFP-48_7x7mm_P0.5mm
U3 | nRF9151-SICA | Package_LGA:Nordic_nRF9160-SIxx_LGA-102-59EP_16.0x10.5mm_P0.5mm
U4 | Ag9905M | Converter_DCDC:Converter_DCDC_Silvertel_Ag99xxLP_THT
U5 | R-78B3.3-2.0 | Converter_DCDC:Converter_DCDC_RECOM_R-78B-2.0_THT
U6 | CP2102N | Package_DFN_QFN:QFN-24-1EP_4x4mm_P0.5mm_EP2.7x2.7mm
U7 | AUTO_PROG_NET

# 5. Módulos Principales y Función

Módulo | Referencia | Función
MCU principal | U1 ESP32-WROOM-32E | Control de pasarela, watchdog y gestión de interfaces.
Ethernet SPI | U2 W5500 | Enlace LAN y transporte UDP para bridge JSON.
Módem DECT NR+ | U3 nRF9151-SICA | Enlace radio DECT NR+ controlado por ESP32 (UART/SPI).
PoE PD | U4 Ag9905M | Conversión desde Ethernet PoE a rail de 5 V.
Regulación 3V3 | U5 R-78B3.3-2.0 | Alimentación principal de lógica.
USB-UART | U6 CP2102N | Programación/depuración desde PC por UART0 ESP32.
RF salida | J3 SMA 132291 | Conector a antena omnidireccional exterior.

# 6. Interconexiones Eléctricas

Interconexiones mínimas verificadas:

Bloque | Señales clave | Descripción
ESP32 <-> W5500 | GPIO18/19/23/21 + INT + RST | SPI dedicado para Ethernet.
ESP32 <-> nRF9151 (UART) | GPIO17/16 (+ RTS/CTS opcional) | Modo por defecto para comandos AT.
ESP32 <-> nRF9151 (SPI) | GPIO25/34/32/33 | Modo alternativo seleccionable por jumpers.
USB-C <-> CP2102N <-> ESP32 | D+/D-, TXD/RXD, DTR/RTS | Depuración y auto-programación.
PoE/USB OR-ing | D6 + D7 Schottky | Selecciona automáticamente fuente 5V_SYS.

# 7. RF, Keep-outs y Enrutado

Ítem RF | Implementación
Banda objetivo | DECT NR+ 1880-1920 MHz (extensible 1880-1930 MHz por antena).
Regla pista RF | 0.45mm fija en net DECT_RF/DECT_RF_ANT
Clearance RF | 0.20mm
Vías en RF | Deshabilitadas por regla DECT_RF_No_Vias.
Red de matching | Topología pi: C301-L301-C302 (ajustable por VNA).
Keep-out bajo antena | Completo en F.Cu/In1.Cu/In2.Cu/B.Cu.
Zona libre alrededor | Marcada como ANT_CLEARANCE_5MM.
Longitud trazas RF (PCB) | DECT_RF: 12.515 mm, DECT_RF_ANT: 5.529 mm, Total: 18.044 mm

Vista top del diseño RF con SMA externo:


Vista isométrica de referencia:


# 8. Validaciones de Diseño (EDA)

Validación | Resultado | Archivo
ERC esquemático | Revisar reporte | /Users/antonio/Documents/KiCad/9.0/projects/esp32_eth_dect_nrf9151_gateway_min_70x50/erc_latest.rpt
DRC PCB | 0 violaciones / 0 unconnected / 0 footprint errors | /Users/antonio/Documents/KiCad/9.0/projects/esp32_eth_dect_nrf9151_gateway_min_70x50/release/drc_after_sma_omni_change.rpt
Reglas RF (DRU) | Track+clearance+no-vias aplicadas | /Users/antonio/Documents/KiCad/9.0/projects/esp32_eth_dect_nrf9151_gateway_min_70x50/esp32_eth_dect_nrf9151_gateway_min.kicad_dru

# 9. Fabricación y Montaje

Paquete | Cantidad | Observación
Gerbers | 12 | Incluye F/B Cu + In1/In2 + máscaras + silk + edge cuts + job.
Drill files | 4 | PTH/NPTH + mapas de taladro.
Pick&Place | 1 | Archivo de posiciones para montaje.
Modelos/Render 3D | 9 | STEP/GLB e imágenes de verificación mecánica.

Recomendaciones de montaje mínimo:

- Ajustar red pi (C301/L301/C302) en primer lote de prototipo con VNA.
- Verificar continuidad de masa/chasis en transición SMA y puesta a tierra exterior.
- Mantener limpieza de zona keep-out y no incorporar cobre accidental en revisión CAM.

# 10. Riesgos Residuales y Recomendaciones

Riesgo residual | Impacto | Mitigación recomendada
Desajuste de impedancia final en entorno real | Pérdida de alcance y eficiencia | Tuning VNA en producto montado (caja+cable+antena final).
Instalación exterior deficiente | Degradación RF por humedad/descargas | Protector coaxial + puesta a tierra + sellado de conectores.
Variabilidad de pérdidas por cableado | Margen de enlace menor al estimado | Estandarizar longitud/tipo de cable y conectores.
Escenario NLOS severo | Caída de RSSI y throughput | Elevar antena y optimizar ubicación de gateway.

# 11. Archivos de Evidencia y Trazabilidad

Archivo | SHA-256 (16 hex)
/Users/antonio/Documents/KiCad/9.0/projects/esp32_eth_dect_nrf9151_gateway_min_70x50/esp32_eth_dect_nrf9151_gateway_min.kicad_pcb | a4a3ff467b514821
/Users/antonio/Documents/KiCad/9.0/projects/esp32_eth_dect_nrf9151_gateway_min_70x50/esp32_eth_dect_nrf9151_gateway_min.kicad_sch | 69931507d5132590
/Users/antonio/Documents/KiCad/9.0/projects/esp32_eth_dect_nrf9151_gateway_min_70x50/release/bom.csv | 995ef89c22cff030
/Users/antonio/Documents/KiCad/9.0/projects/esp32_eth_dect_nrf9151_gateway_min_70x50/release/drc_after_sma_omni_change.rpt | f622bdd7b330970d
/Users/antonio/Documents/KiCad/9.0/projects/esp32_eth_dect_nrf9151_gateway_min_70x50/erc_latest.rpt | 088306e32417c92d
/Users/antonio/Documents/KiCad/9.0/projects/esp32_eth_dect_nrf9151_gateway_min_70x50/release/fab_2026-04-21/fab_2026-04-21_bundle.zip | 676db1bbb4602141
/Users/antonio/Documents/KiCad/9.0/projects/esp32_eth_dect_nrf9151_gateway_min_70x50/release/Informe_QARTIA_Antena_DECT_NRplus_2026-04-21.docx | b8b29ebd0612eecf

# 12. Supuestos de Simulación

- TX del nRF9151 fija a 19 dBm (requisito de diseño).
- Antena exterior omnidireccional ~7 dBi.
- Pérdidas de cadena RF modeladas: 1.02 dB totales.
- Modelo de propagación log-distance a 1.9 GHz (n variable por escenario).
- No se incluyen fading rápido ni interferencia co-canal dinámica en estas curvas.
- Resultados indicados como simulación de ingeniería, no como certificación de campo.

# 13. S11 y VSWR

Resultado de simulación de adaptación en banda DECT 1880-1920 MHz:

Métrica | Valor
S11 mínimo en banda (mejor adaptación) | -23.00 dB @ 1900.0 MHz
VSWR mínimo en banda | 1.15
VSWR máximo en banda | 1.62
Criterio ingeniería | Objetivo preliminar: S11 <= -10 dB en banda útil

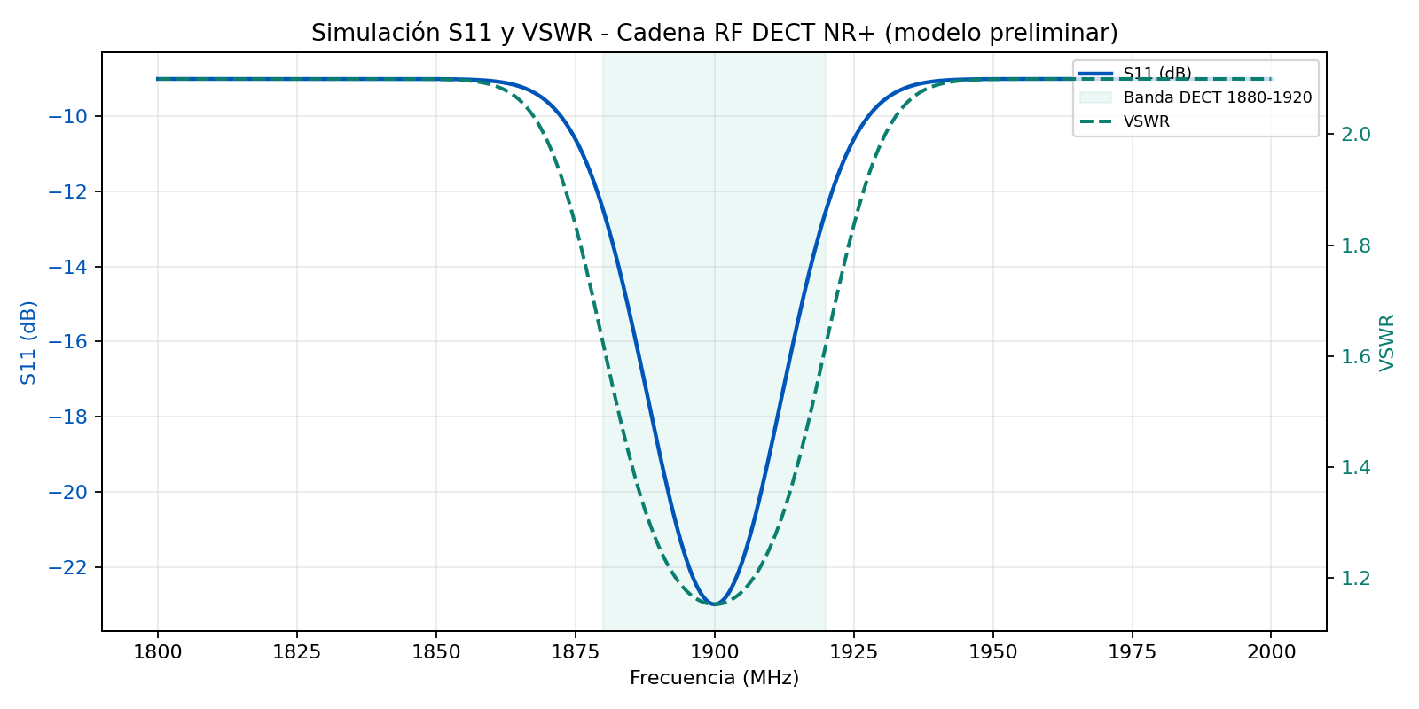
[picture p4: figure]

# 14. RSSI vs Distancia

Curvas simuladas de RSSI para tres escenarios de propagación con TX fija de 19 dBm y EIRP estimada de 24.98 dBm.

Escenario | n | Distancia máx (sens -98 dBm) | Distancia máx (sens -103 dBm) | Distancia máx (sens -108 dBm)
LOS abierto | 2.1 | 11116 m | 19233 m | 33277 m
Suburbano/mixto | 2.7 | 1402 m | 2148 m | 3290 m
Interior industrial | 3.3 | 376 m | 532 m | 755 m

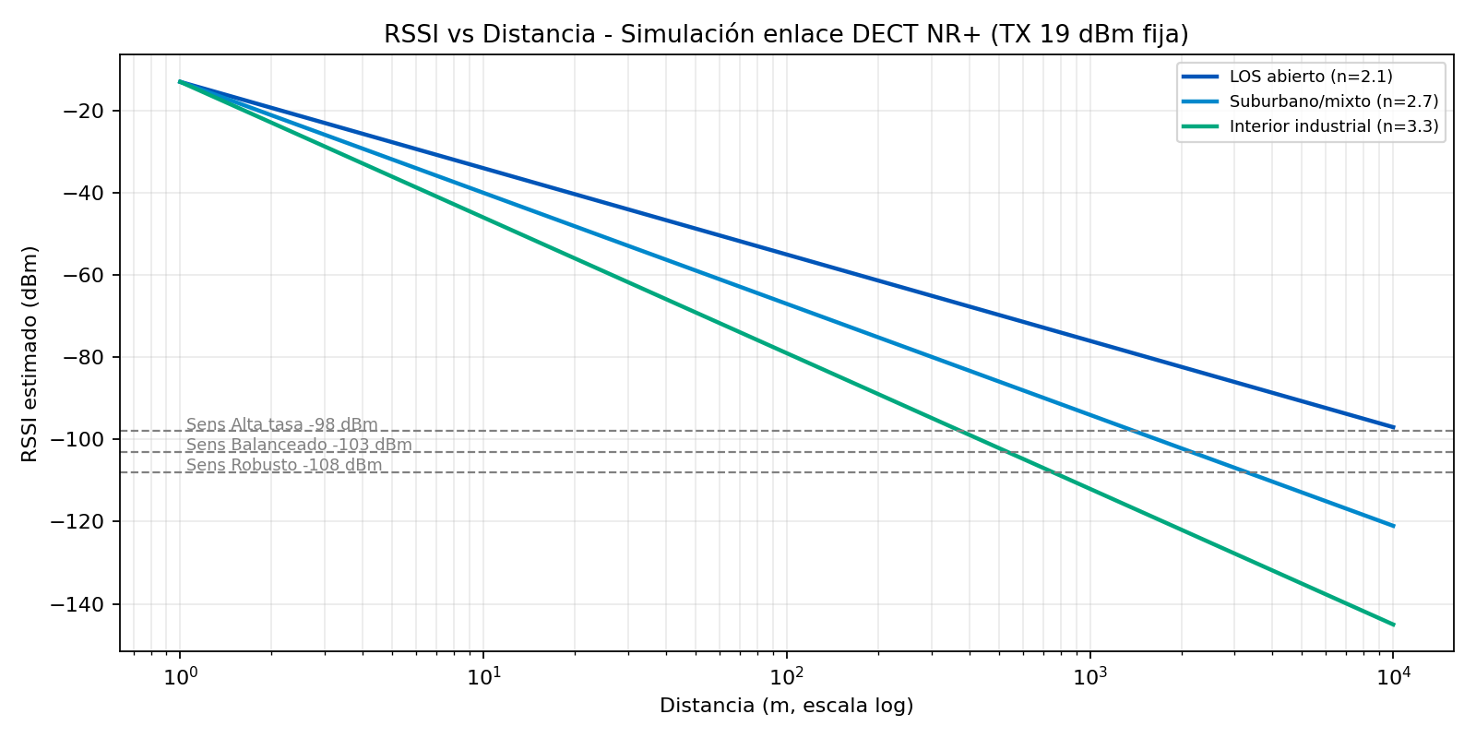
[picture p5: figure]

# 15. Tabla resumen numérica RF

Parámetro | Valor
TX configurada nRF9151 | 19.00 dBm
Pérdidas cadena RF | 1.02 dB
Potencia en entrada antena | 17.98 dBm
Ganancia antena | 7.00 dBi
EIRP estimada | 24.98 dBm
Longitud total de traza RF en PCB | 18.044 mm
Stackup | 4 capas, espesor 1.60 mm
DRC final | 0 violaciones (reporte de referencia)

# 16. Archivos de gráficas generadas con Resultados de potencia, RSSI y distancia alcanzada

Archivo generado | Descripción
/Users/antonio/Documents/KiCad/9.0/projects/esp32_eth_dect_nrf9151_gateway_min_70x50/release/qartia_report_2026-04-21/figures/fig_01_s11_vswr_dect.png | Gráfica S11/VSWR simulada
/Users/antonio/Documents/KiCad/9.0/projects/esp32_eth_dect_nrf9151_gateway_min_70x50/release/qartia_report_2026-04-21/figures/fig_02_rssi_vs_distancia.png | Gráfica RSSI vs distancia simulada
/Users/antonio/Documents/KiCad/9.0/projects/esp32_eth_dect_nrf9151_gateway_min_70x50/release/qartia_report_2026-04-21/data/s11_vswr_sim_1800_2000.csv | Datos numéricos de S11 y VSWR
/Users/antonio/Documents/KiCad/9.0/projects/esp32_eth_dect_nrf9151_gateway_min_70x50/release/qartia_report_2026-04-21/data/rssi_vs_distancia_sim.csv | Datos numéricos de RSSI por distancia y escenario
/Users/antonio/Documents/KiCad/9.0/projects/esp32_eth_dect_nrf9151_gateway_min_70x50/release/qartia_report_2026-04-21/data/rf_resumen_numerico.csv | Resumen de distancias máximas por sensibilidad
/Users/antonio/Documents/KiCad/9.0/projects/esp32_eth_dect_nrf9151_gateway_min_70x50/release/qartia_report_2026-04-21/data/potencia_cadena_rf.csv | Resultados de potencia y presupuesto de enlace

- /Users/antonio/Documents/KiCad/9.0/projects/esp32_eth_dect_nrf9151_gateway_min_70x50/release/qartia_report_2026-04-21/figures/fig_01_s11_vswr_dect.png
- /Users/antonio/Documents/KiCad/9.0/projects/esp32_eth_dect_nrf9151_gateway_min_70x50/release/qartia_report_2026-04-21/figures/fig_02_rssi_vs_distancia.png
- /Users/antonio/Documents/KiCad/9.0/projects/esp32_eth_dect_nrf9151_gateway_min_70x50/release/qartia_report_2026-04-21/data/s11_vswr_sim_1800_2000.csv
- /Users/antonio/Documents/KiCad/9.0/projects/esp32_eth_dect_nrf9151_gateway_min_70x50/release/qartia_report_2026-04-21/data/rssi_vs_distancia_sim.csv
- /Users/antonio/Documents/KiCad/9.0/projects/esp32_eth_dect_nrf9151_gateway_min_70x50/release/qartia_report_2026-04-21/data/rf_resumen_numerico.csv
- /Users/antonio/Documents/KiCad/9.0/projects/esp32_eth_dect_nrf9151_gateway_min_70x50/release/qartia_report_2026-04-21/data/potencia_cadena_rf.csv

# ANEXO: EL informe completo Informe_QARTIA_Antena_DECT_NRplus_2026-04-21.docx

Archivo anexo de referencia:

- /Users/antonio/Documents/KiCad/9.0/projects/esp32_eth_dect_nrf9151_gateway_min_70x50/release/Informe_QARTIA_Antena_DECT_NRplus_2026-04-21.docx

SHA-256 (16 hex): b8b29ebd0612eecf

17. Actualización de Ingeniería (22-23/04/2026)

Resumen de avances consolidados de ayer (22/04/2026) y hoy (23/04/2026):

Integración HW: interfaz nRF9151 fijada en opción 2 (SPI) como configuración activa de placa y firmware mínimo.

Integración HW: incorporación de TP301 (SWDIO) y TP302 (SWDCLK) para depuración y para eliminar ramas de red de un solo nodo en SWD.

Integración HW: mantenimiento de jumpers SJ101-SJ104 (ruta UART) y SJ201-SJ204 (ruta SPI), quedando SPI como ruta montada de referencia.

Validación EDA final (2026-04-22 23:13): DRC limpio con 0 violaciones, 0 pads desconectados y 0 errores de footprint.

Paridad esquema-PCB (2026-04-22 23:13): 0 incidencias de paridad.

ERC (2026-04-22 23:13): 0 errores y 23 warnings de tipo footprint_link_issues (bibliotecas), sin impacto eléctrico funcional.

Fabricación: regenerados Gerbers, taladros PTH/NPTH, Pick&Place, BOM, netlist y PDF de esquema con el estado limpio actual.

3D CAD: regenerados STEP/GLB estándar y de inspección (incluyendo cobre/pistas/pads/vías para revisión visual).

3D CAD (23/04/2026): limpieza de nodos auxiliares en GLB para evitar identificación de "componentes fantasma" en visores 3D.

Trazabilidad GitHub: tag v2026.04.22.4 (SPI opción 2), v2026.04.22.5 (TP301/TP302 + salidas fabricación/3D), v2026.04.22.6 (limpieza de nodos GLB).

Ruta de evidencia principal: /Users/antonio/Documents/esp32-eth-dect-nrf9151-gateway-hw-docs/kicad_complete_2026-04-22/erc_drc/

QARTIA · Documento técnico

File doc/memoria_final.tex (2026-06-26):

\documentclass[a4paper,11pt]{article}
\usepackage{graphicx,geometry,subcaption}
\usepackage{fontspec}
\setmainfont{Times New Roman}

\usepackage{hyperref}
\hypersetup{
	colorlinks=true,
	urlcolor=blue,
	linkcolor=black,
	citecolor=black
}

\usepackage{setspace}
\singlespacing

\usepackage[spanish]{babel}
\geometry{margin=2.5cm}

\usepackage{fancyhdr}
\pagestyle{fancy}

\fancyhf{}
\fancyfoot[C]{\thepage}
\renewcommand{\headrulewidth}{0pt}

\usepackage{titlesec}
\titleformat{\section}
	{\normalfont\bfseries\fontsize{11}{13}\selectfont}
	{\thesection}
	{1em}
	{\MakeUppercase}
	
\titlespacing*{\section}
	{0pt}
	{11pt}
	{11pt}

\titleformat{\subsection}
	{\normalfont\bfseries\fontsize{11}{13}\selectfont}
	{\thesubsection}
	{1em}
	{}

\titlespacing*{\subsection}
	{0pt}
	{11pt}
	{11pt}

\newcommand{\practicatitle}[9]{
    \begin{center}
        \vspace*{11pt}
        
        {\bfseries\MakeUppercase{#1}\par}
        
        \vspace{18pt}
        
        {\bfseries #2\par}
        
        \vspace{6pt}
        
        #3\par
        #4\par
        #5\par
        #6\par
        
        \vspace{12pt}
        
        #7\par
        #8\par
        #9\par
        
        \vspace{18pt}
    \end{center}
}

\begin{document}
\practicatitle
{Diseño y Desarrollo de un gateway Ethernet-5G privado}
{Williams, Robbie Keith – X8503344Z (Estudiante)}
{García Sánchez, Antonio Javier (Tutor de Empresa)}
{e-mail (tutor de empresa): \href{mailto:antoniojavier.garcia@upct.es}{antoniojavier.garcia@upct.es}}
{Universidad Politécnica de Cartagena}
{Antiguo Cuartel de Antigones. Plaza del Hospital, 1. 30202 Cartagena}
{García Sánchez, Antonio Javier (Tutor Académico)}
{e-mail (tutor académico): \href{mailto:antoniojavier.garcia@upct.es}{antoniojavier.garcia@upct.es}}
{Universidad Politécnica de Cartagena, Departamento de Tecnologías de la Información y las Comunicaciones}
\tableofcontents
\newpage
\section*{Resumen}
En esta práctica, me he formado en programación de sistemas embebidos, específicamente programación en ESP32 utilizando el entorno ESP-IDF. El objetivo del proyecto en el cual estoy trabajando es el diseño y desarrollo de un gateway Ethernet-DECT que permita recibir comunicación por ethernet y retransmitir los datos recibidos por el protocolo dect y vice-versa.También he aprendido a estudiar diseños de PCBs a través de herramientas como KiCad y FreeCAD.
\addcontentsline{toc}{section}{RESUMEN}
\section{Descripción concreta y detallada de las tareas, trabajos desarrollados y departamentos de la entidad a los que ha estado asignado.}
Las tareas que he desarrollado y estoy desarrollando a lo largo de este puesto son:
\begin{itemize}
	\item Entender el entorno ESP32, leyendo la documentación y estudiando las guías de referencia API además de preguntarle dudas a mis compañeros.
	\item Observar y analizar el diseño de la placa en KiCad y FreeCAD, con el objetivo de mejorar mi entendimiento del proyecto y de sus requisitos y objetivos. Colaborar con compañeros de hardware para identificar posibles problemas y encontrar soluciones.
	\item Estudiar el código del firmware de la placa para entender su estructura y las funciones de cada componente.
	\item Hacer el build del proyecto y flashearlo en una placa de prueba para comprobar su funcionalidad.
	\item Programar en C un firmware simulado de la placa para poder comprobar su correcta estructura y depurar posibles errores, flasheando y analizando los resultados de su ejecución en la placa de prueba.
\end{itemize}
Todas estas tareas se realizaron en el laboratorio de software Qartia, situado en la primera planta del edificio de Antigones.
\section{Valoración de las tareas desarrolladas con los conocimientos y competencias adquiridos en relación con los estudios universitarios.}
Las competencias adquiridas a lo largo del grado en Ingeniería Telemática que he aplicado en las prácticas son principalmente dos:
\begin{enumerate}
	\item \textbf{Programación en C: } Aunque a lo largo de la carrera de Ingeniería Telemática no tenemos ninguna asignatura que aborde C o C++ mas allá de lo más básico, los conceptos básicos aprendidos en Java se pueden aplicar también en la programación del firmware del ESP32 en C.
	\item \textbf{Entorno ESP32/ESP-IDF: } En el curso de mis estudios nunca he trabajado con ESP32, pero he podido aplicar los conocimientos aprendidos en la asignatura de Sistemas Digitales Basados en Microprocesadores sobre el proceso de build, flash y posterior depuración de la ejecución del programa sobre la placa física.   
\end{enumerate}
\section{Relación de los problemas planteados y el procedimiento seguido para su resolución.}
\begin{itemize}
	\item \textbf{Desarrollo del firmware: } Para el desarrollo de la práctica es importante la implementación y validación del firmware del proyecto. El procedimiento seguido fue el siguiente:
	\begin{enumerate}
		\item \textbf{Estudio del entorno ESP-IDF: } Para poder estudiar bien el código heredado en el proyecto, primero fue importante entender el propio entorno ESP-IDF. Sus APIs, métodos y funciones básicos, el manejo de errores, etc. Aunque en ESP-IDF se utiliza C, como todos los proyectos ESP dependen de esta librería, la manera de programar y la estructura del código son diferentes, por lo tanto es importante entender al menos lo más básico para poder trabajar con este framework.
		\item \textbf{Estudio del código: } En segundo lugar, realicé un estudio del código heredado, para entender la funcionalidad de cada componente y el comportamiento del firmware. 
		\item \textbf{Pruebas en placa física: } El siguiente paso que tomé fue buscar una placa ESP32 en la cual realizar pruebas y hacer modificaciones al firmware. Primero probé varios ejemplos incluidos en el propio entorno ESP-IDF para comprobar el correcto funcionamiento de la placa obtenida gracias a los compañeros del laboratorio de hardware. Cuando comprobé que los ejemplos se ejecutaban de forma correcta y la salida en consola era la esperada, continué con el siguiente paso.
		\item \textbf{Prueba del firmware en placa de desarrollo: } Tras realizar las pruebas con los proyectos de ejemplo aportados por el entorno ESP-IDF, decidí probar el firmware del gateway ethernet-DECT en la placa de desarrollo. Aquí fue donde pude encontrar el primer gran problema del proyecto. El firmware fallaba a la hora de inicializar el link ethernet. Consulté con mis compañeros, sobretodo con Julián, la forma más eficiente de depurar el firmware, ya que yo estaba acostumbrado a utilizar debuggers integrados como el de \href{https://code.visualstudio.com/docs/debugtest/debugging}{Visual Studio Code} (o parecidos) y herramientas como \href{https://sourceware.org/gdb/}{GDB}, los cuales no se pueden utilizar en el entorno de desarrollo ESP32. Gracias a la aportación de mis compañeros e investigación propia, entendí que la forma más viable de depurar el firmware en este contexto es simplemente con sentencias \href{https://docs.espressif.com/projects/esp-idf/en/stable/esp32/api-reference/system/log.html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}{ESP\_LOG}, que imprimen en pantalla el valor obtenido de una función o una expresión además del valor esperado para así comprobar la causa de los errores indicados en el build. Tras varias horas de investigación y depuración, encontré la causa del problema. El proyecto que heredé asumía cierto chip de ethernet, el \href{https://www.lcsc.com/datasheet/C703537.pdf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}{IP101GRI}, mientras que la placa de desarrollo que tenía disponible consta de un chip distinto, el \href{https://docs.wiznet.io/img/products/w5500/W5500_ds_v110e.pdf}{W5500}. El código de cada chip es incompatible con el otro, y hacer una migración del código entero a otro controlador de ethernet no parecía viable en su momento, entonces decidí tomar otro camino.
		\item \textbf{Desarrollo de firmware simulado: } En vez de intentar ejecutar un firmware diseñado para otra placa, con características distintas y chips/drivers diferentes, decidí simular el comportamiento del firmware para comprobar que la lógica del código es correcta. Para esto, elaboré un código "mock" para cada archivo de código del firmware. Es decir, un código que simula el comportamiento del hardware físico. Este código simplemente asume que el hardware funciona correctamente y devuelve valores predefinidos para simular el comportamiento real. Así pude depurar la lógica del programa y encontrar fallos en su planteamiento y/o ejecución. El proceso de desarrollo empezó con un estudio más profundo del código, tomando nota de el objetivo de cada función y variable global del código. El resultado de este estudio es el archivo descripción\_funciones.md disponible en el anexo de la memoria, que contiene una breve descripción del comportamiento de cada función y las variables globales de cada archivo de los componentes del firmware. Con este archivo además del firmware original como referencias, pude empezar a desarrollar el firmware simulado, reemplazando cada función requerida por una versión "MOCK" simulada, empezando con el 'app\_main()'. La primera versión de la simulación del app\_main.c contenía el esqueleto de todas las funciones que llama desde la función principal 'app\_main()' que simplemente devuelven ESP\_OK, para primero ejecutar esta versión muy básica y a partir de ahí implementar secuencialmente los métodos correspondientes de cada componente. Estas versiones básicas siguen comentadas dentro del archivo mock\_app\_main.c. En cuanto el 'mock\_app\_main()' fue completado con todas las llamadas que establece, repetí el mismo proceso con cada componente del firmware. Esto es:
		\begin{itemize}
			\item gw\_bridge
			\item gw\_dect
			\item gw\_diag
			\item gw\_eth
			\item gw\_watchdog
		\end{itemize}
		En cuanto la elaboración del firmware simulado para el resto de componentes se completó, empecé un largo periodo de depuración.
		\item \textbf{Depuración del firmware simulado: } inicialmente el build con el firmware simulado daba muchos errores de compilación. Aunque encontré y arreglé algunos errores sintácticos en el código desarrollado, no conseguí completar el build y no entendía la causa. Tras revisar de nuevo la documentación y la referencia API de espressif, encontré que una posible causa sería tener que modificar los archivos CMakeList.txt dentro de cada carpeta del firmware. Tras adaptar estos archivos para tener en cuenta el firmware simulado en vez de el original, pude completar el build e intentar flashearlo en la placa de desarrollo.
		\item \textbf{Validación del firmware simulado en la placa de desarrollo: } El flash del firmware simulado funcionó correctamente con el primer intento y conseguí verificar la lógica del firmware con la salida en consola. En la salida del comando 'idf.py -p /dev/ttyUSB1 -b 115200 flash monitor' se puede observar que las llamadas a las funciones que simulan el comportamiento del firmware se hacen correctamente y en orden. Hice un pipe en bash de la salida al archivo run\_results.txt y en este archivo pude verificar que la lógica del firmware es correcta. El firmware simulado se encuentra en la misma topología del proyecto que el firmware original, con el prefijo "mock" para cada componente. Se puede hacer el build del firmware original comentando el archivo mock\_app\_main.c entero, y descomentando app\_main.c. 
	\end{enumerate}
	\item \textbf{Estudio de la placa diseñada en KiCad: } En paralelo con la validación y desarrollo del firmware, realicé un estudio de la placa diseñada a través de las herramientas 2D y 3D del entorno KiCad, con el fin de entender el comportamiento del diseño. Con la ayuda de mis compañeros del laboratorio de hardware, pude identificar varios problemas con el diseño que tendrían que ser rectificados posteriormente. Un chip que atravesaba el PCB, elementos desconectados, vías localizadas en los pads, entre otros. 
\end{itemize}
Todo el desarrollo de las pácticas se ha realizado con mi portátil personal HP usando \href{https://fedoraproject.org/}{Fedora Linux 43} sobre la placa \href{https://docs.espressif.com/projects/esp-dev-kits/en/latest/esp32/esp32-ethernet-kit/user_guide.html}{ESP32-Ethernet-Kit v1.2} detallada en el anexo de esta memoria.
\section{Anexos.}
\begin{itemize}
	\item \href{https://docs.espressif.com/projects/esp-idf/en/stable/esp32/api-reference/index.html}{Documentación espressif}, utilizada como referencia principal para comprobar APIs de desarrollo, manejo de errores, etc.
	\item \href{https://docs.espressif.com/projects/esp-dev-kits/en/latest/esp32/esp32-ethernet-kit/user_guide.html}{ESP32-Ethernet-Kit v1.2}, placa usada para flashear el firmware y realizar las pruebas necesarias.
	\item \href{https://github.com/Robinhood-700/gateway-eth-5g-privado}{Repositorio GitHub} en el cual se almacena el código fuente del proyecto además de los resultados obtenidos.
		\begin{itemize}
			\item \href{https://github.com/Robinhood-700/gateway-eth-5g-privado/blob/main/README.md}{Descripción} del proyecto en GitHub.
			\item \href{https://github.com/Robinhood-700/gateway-eth-5g-privado/tree/main/resultados}{Colección de resultados} del build y la simulación del firmware.
			\item \href{https://github.com/Robinhood-700/gateway-eth-5g-privado/tree/main/firmware/esp32_gateway}{Código fuente} del firmware simulado.
			\item \href{https://github.com/Robinhood-700/gateway-eth-5g-privado/blob/main/doc/memoria_final.tex}{Código fuente} \LaTeX de la memoria.
			\item \href{https://github.com/Robinhood-700/gateway-eth-5g-privado/blob/main/doc/descripcion_funciones.md}{Descripción} de todas las funciones del firmware original.
		\end{itemize}
	\item \href{https://github.com/espressif/esptool}{ESPtool}, software utilizado para realizar el build del proyecto y realizar el proceso de flash.
	\item Datasheet del chip ethernet \href{https://www.lcsc.com/datasheet/C703537.pdf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}{IP101GRI}
	\item Datasheet del chip ethernet \href{https://docs.wiznet.io/img/products/w5500/W5500_ds_v110e.pdf}{W5500}
	\item \href{https://fedoraproject.org/}{Fedora Linux 43}
	\item \href{https://joplinapp.org/}{Joplin}, aplicación de notas utilizada para la elaboración del archivo descripcion\_funciones.md.
\end{itemize}
\thispagestyle{fancy}
\fancyfoot[L]{PDF Compilado con \LaTeX}
\fancyfoot[C]{\thepage}
\fancyfoot[R]{\today}
\end{document}

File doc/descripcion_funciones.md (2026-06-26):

# Descripción de funciones y variables globales

## app_main.c

### Variables globales

* **TAG:** Cadena utilizada para identificar los mensajes mostrados por el log.

### Funciones

#### init_nvs()

Inicializa la memoria NVS del ESP32. Si detecta algún problema durante la inicialización, la borra y la vuelve a crear.

#### app_main()

Función principal del firmware. Inicializa todos los módulos del sistema, realiza una comprobación inicial de la comunicación DECT y pone en marcha el bridge, el watchdog y el sistema de diagnóstico.

---

# gw_bridge.c

### Variables globales

* **TAG:** Identificador utilizado en los mensajes de log.
* **s_dect_rx_q:** Cola donde se almacenan los mensajes recibidos desde DECT.
* **s_peer_mutex:** Mutex para proteger el acceso a la dirección del cliente UDP.
* **s_have_last_peer:** Indica si existe un cliente UDP registrado.
* **s_last_peer:** Último cliente UDP que ha enviado datos.
* **s_use_fixed_peer:** Indica si se utiliza una dirección IP fija.
* **s_fixed_peer:** Dirección IP configurada manualmente.
* **s_stats:** Contadores de estadísticas del bridge.
* **s_stats_lock:** Protección para acceder a las estadísticas.

### Funciones

#### stats_inc()

Incrementa uno de los contadores de estadísticas.

#### stats_copy()

Copia las estadísticas actuales.

#### dect_rx_cb()

Recibe mensajes desde DECT y los almacena para enviarlos posteriormente por Ethernet.

#### udp_rx_task()

Escucha paquetes UDP y los reenvía al módulo DECT.

#### resolve_peer()

Obtiene la dirección IP del destinatario al que enviar los datos.

#### udp_tx_task()

Envía por UDP los mensajes recibidos desde DECT.

#### load_fixed_peer()

Carga la dirección IP fija configurada para el bridge.

#### gw_bridge_start()

Inicializa el bridge y crea las tareas de transmisión y recepción.

#### gw_bridge_get_stats()

Devuelve las estadísticas del bridge.

#### gw_bridge_reset_stats()

Reinicia todos los contadores.

#### gw_bridge_set_runtime_peer()

Permite cambiar el destino UDP durante la ejecución.

#### gw_bridge_inject_dect_json()

Introduce manualmente un mensaje DECT para realizar pruebas.

---

# gw_dect.c

### Variables globales

* **s_rx_cb:** Callback utilizado para entregar los datos recibidos.
* **s_rx_ctx:** Contexto asociado al callback.
* **s_at_ok_sem:** Semáforo utilizado durante el healthcheck.
* **s_rx_task:** Tarea encargada de la recepción de datos.
* **s_spi:** Dispositivo SPI utilizado cuando esa interfaz está habilitada.
* **s_spi_bus_init:** Indica si el bus SPI ya ha sido inicializado.

### Funciones

#### publish_payload_line()

Procesa las líneas recibidas desde el módulo DECT y las entrega al callback correspondiente.

#### iface_write()

Envía datos mediante la interfaz de comunicación configurada.

#### uart_rx_task()

Lee continuamente los datos recibidos por UART.

#### spi_xfer()

Realiza una transferencia SPI.

#### spi_rx_task()

Lee datos del módulo DECT utilizando SPI.

#### iface_init()

Inicializa la interfaz física de comunicación.

#### send_line()

Envía una línea de texto al módulo DECT.

#### gw_dect_init()

Inicializa la comunicación con el módulo DECT.

#### gw_dect_restart()

Reinicia la interfaz DECT.

#### gw_dect_set_rx_callback()

Registra el callback encargado de recibir los mensajes.

#### gw_dect_send_json()

Envía un mensaje JSON al módulo DECT.

#### gw_dect_healthcheck()

Comprueba que la comunicación con DECT sigue funcionando correctamente.

#### gw_dect_test_inject_rx_line()

Simula la recepción de una línea para realizar pruebas.

---

# gw_diag.c

### Variables globales

* **s_eth_rand_seq:** Contador de mensajes Ethernet generados.
* **s_dect_rand_seq:** Contador de mensajes DECT generados.

### Funciones

#### print_line()

Imprime una línea en la consola de depuración.

#### print_help()

Muestra los comandos disponibles.

#### parse_positive_int()

Convierte una cadena a un número entero válido.

#### make_random_json()

Genera un mensaje JSON con datos aleatorios.

#### send_udp_to_gateway()

Envía un paquete UDP al propio gateway.

#### print_bridge_stats()

Muestra las estadísticas del bridge.

#### cmd_status()

Muestra el estado general del gateway.

#### cmd_poe()

Comprueba el estado de la alimentación PoE.

#### cmd_at()

Ejecuta un healthcheck del módulo DECT.

#### cmd_set_peer()

Permite cambiar el destino UDP.

#### run_eth_random_burst()

Genera tráfico Ethernet de prueba.

#### run_dect_random_burst()

Genera tráfico DECT de prueba.

#### cmd_rand_eth()

Ejecuta el envío de tráfico Ethernet aleatorio.

#### cmd_rand_dect()

Ejecuta el envío de tráfico DECT aleatorio.

#### cmd_fw_update()

Muestra información para actualizar el firmware.

#### execute_command()

Procesa los comandos introducidos por el usuario.

#### usb_debug_task()

Implementa la consola de depuración por USB.

#### random_example_task()

Genera tráfico de prueba de forma periódica.

#### gw_diag_start()

Inicializa el sistema de diagnóstico.

---

# gw_eth.c

### Variables globales

* **s_eth_handle:** Manejador del controlador Ethernet.
* **s_eth_netif:** Interfaz de red Ethernet.
* **s_eth_glue:** Unión entre el driver Ethernet y la pila TCP/IP.
* **s_link_up:** Estado del enlace Ethernet.
* **s_have_ip:** Indica si existe una dirección IP asignada.
* **s_link_down_since_ms:** Tiempo desde que el enlace dejó de estar activo.

### Funciones

#### now_ms()

Obtiene el tiempo actual en milisegundos.

#### on_eth_event()

Gestiona los eventos del controlador Ethernet.

#### on_ip_event()

Gestiona la obtención o pérdida de dirección IP.

#### install_eth_driver()

Inicializa el controlador Ethernet.

#### gw_eth_init()

Inicializa la interfaz Ethernet.

#### gw_eth_restart()

Reinicia el controlador Ethernet.

#### gw_eth_link_up()

Indica si el enlace Ethernet está activo.

#### gw_eth_has_ip()

Indica si existe una dirección IP asignada.

#### gw_eth_link_down_ms()

Devuelve cuánto tiempo lleva el enlace desconectado.

#### gw_eth_get_ipv4()

Obtiene la dirección IPv4 actual.

---

# gw_json.c

### Funciones

#### skip_ws()

Ignora los espacios en blanco de una cadena.

#### gw_json_is_valid()

Comprueba si un bloque de datos tiene formato JSON.

#### hex_wrap()

Convierte datos binarios en una representación hexadecimal dentro de un objeto JSON.

#### gw_json_ensure()

Garantiza que la salida tenga formato JSON, convirtiendo los datos cuando es necesario.

---

# gw_watchdog.c

### Funciones

#### supervisor_task()

Supervisa continuamente el estado del gateway y reinicia Ethernet o DECT cuando detecta fallos.

#### gw_watchdog_start()

Crea la tarea encargada de supervisar el funcionamiento del sistema.

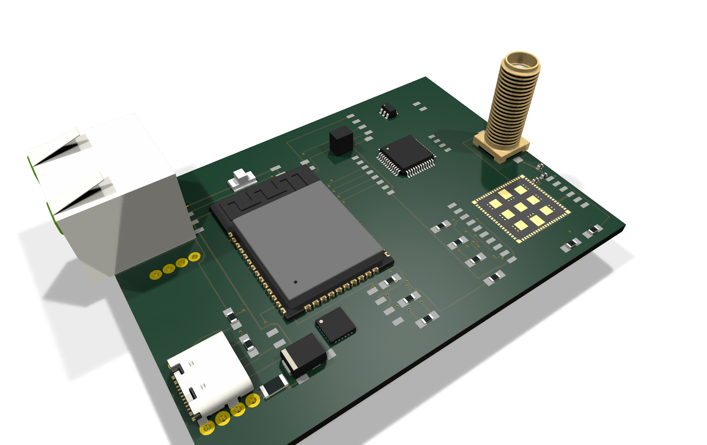
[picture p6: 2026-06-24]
renders/render_iso_2026-04-22.png

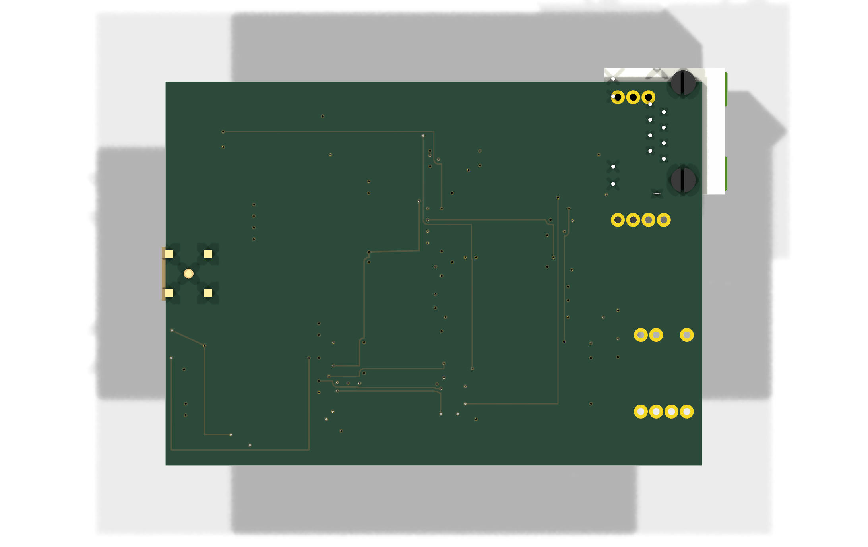
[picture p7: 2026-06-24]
renders/render_bottom_2026-04-22.png

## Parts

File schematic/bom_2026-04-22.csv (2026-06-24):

Refs | Value | Footprint | Qty | DNP
C301 | DNP | gateway_min_local:C_0402_1005Metric_RF | 1
C302 | DNP | gateway_min_local:C_0402_1005Metric_RF | 1
D7 | SS34 | PASSIVE_2PAD_PLACEHOLDER | 1
F2 | 500mA | PASSIVE_2PAD_PLACEHOLDER | 1
J1 | RJ45_POE | RJ45_POE_MAG_PLACEHOLDER | 1
J2 | USB_C_PC | USB_C_PC_PLACEHOLDER | 1
J3 | SMA_EXT_OMNI | gateway_min_local:SMA_RF_PLACEHOLDER | 1
L301 | 0R_MOUNTED | Inductor_SMD:L_0402_1005Metric | 1
R201 | 5k1 | PASSIVE_2PAD_PLACEHOLDER | 1
R202 | 5k1 | PASSIVE_2PAD_PLACEHOLDER | 1
SJ101 | DNP | SJ_2PAD_PLACEHOLDER | 1
SJ102 | DNP | SJ_2PAD_PLACEHOLDER | 1
SJ103 | DNP | SJ_2PAD_PLACEHOLDER | 1
SJ104 | DNP | SJ_2PAD_PLACEHOLDER | 1
SJ201 | 0R_MOUNTED | SJ_2PAD_PLACEHOLDER | 1
SJ202 | 0R_MOUNTED | SJ_2PAD_PLACEHOLDER | 1
SJ203 | 0R_MOUNTED | SJ_2PAD_PLACEHOLDER | 1
SJ204 | 0R_MOUNTED | SJ_2PAD_PLACEHOLDER | 1
TP301 | TP_SWDIO_GND | PASSIVE_2PAD_PLACEHOLDER | 1
TP302 | TP_SWDCLK_GND | PASSIVE_2PAD_PLACEHOLDER | 1
U1 | ESP32-WROOM-32E | ESP32_WROOM_32E_PLACEHOLDER | 1
U2 | W5500 | W5500_LQFP48_PLACEHOLDER | 1
U3 | nRF9151-SICA | NRF9151_SIP_PLACEHOLDER | 1
U4 | Ag9905M | POE_PD_8023AF_PLACEHOLDER | 1
U5 | R-78B3.3-2.0 | BUCK_5V3V3_PLACEHOLDER | 1
U6 | CP2102N | CP2102N_PLACEHOLDER | 1
U7 | AUTO_PROG_NET | AUTO_PROG_NET_PLACEHOLDER | 1

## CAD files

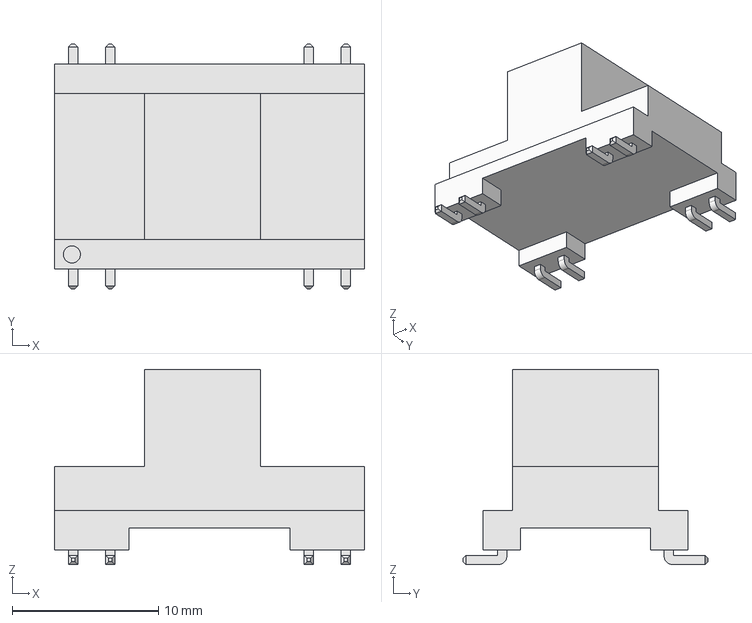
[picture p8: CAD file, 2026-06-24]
project_snapshot/3dmodels/Ag9900.step
21.2 x 16.7 x 13.3 mm

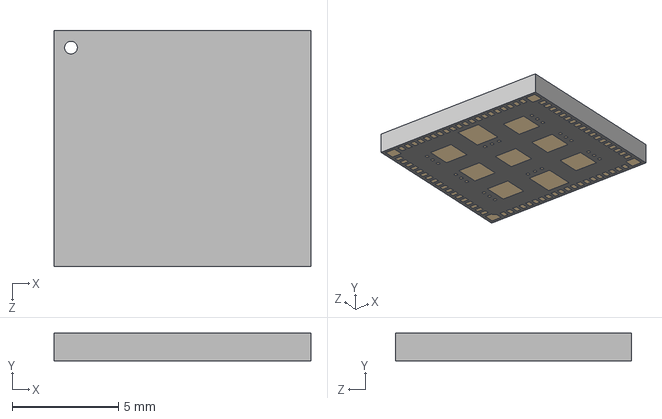
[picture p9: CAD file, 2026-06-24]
project_snapshot/3dmodels/NRF9151-LACA-R.STEP
12.1 x 1.30 x 11.1 mm

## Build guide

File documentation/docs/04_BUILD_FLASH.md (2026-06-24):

# 04 - Procedimiento minimo de build/flash

## Prerrequisitos
- ESP-IDF 6.1 instalado.
- Toolchain `xtensa-esp-elf` para `esp32`.
- Puerto USB-UART/debug conectado al ESP32.

## Build base (SPI, default)
```bash
cd /Users/antonio/Documents/esp32-eth-dect-nrf9151-gateway-hw-docs/kicad_complete_2026-04-22/firmware/esp32_gateway
source /Users/antonio/esp/esp-idf/export.sh
idf.py set-target esp32
idf.py build
```

## Build alternativo (UART por software)
```bash
cd /Users/antonio/Documents/esp32-eth-dect-nrf9151-gateway-hw-docs/kicad_complete_2026-04-22/firmware/esp32_gateway
source /Users/antonio/esp/esp-idf/export.sh
idf.py -B build-uart -DSDKCONFIG_DEFAULTS='sdkconfig.defaults;sdkconfig.uart' set-target esp32 build
```

## Configuracion minima por menuconfig
```bash
idf.py menuconfig
```
- `Gateway MVP configuration` -> `nRF9151 host interface` (`UART` o `SPI`).
- `Gateway MVP configuration` -> pines W5500 y nRF9151.
- `Gateway MVP configuration` -> puertos UDP y timeouts (`ETH_RESTART`, `AT_TIMEOUT`, `SUPERVISOR_PERIOD`).

## Flash + monitor
```bash
idf.py -p /dev/ttyUSB0 flash monitor
```

## Actualizacion por USB con script
```bash
cd /Users/antonio/Documents/esp32-eth-dect-nrf9151-gateway-hw-docs/kicad_complete_2026-04-22/firmware/esp32_gateway
./tools/usb_debug/flash_usb.sh /dev/ttyUSB0 460800
```

## Consola de debugging USB
- En monitor aparece prompt `gwdbg>`.
- Comandos utiles:
  - `status`
  - `bridge_stats`
  - `at`
  - `poe`
  - `fw_update`

## Logs esperados de arranque
- `Ethernet link up`
- `Ethernet got IP: ...`
- `AT link validated` (o reintentos de supervisor)
- `Gateway bridge started (ETH<->DECT)`

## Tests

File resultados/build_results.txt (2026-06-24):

-- IDF_TARGET is not set, guessed 'esp32' from sdkconfig '/srv/dect2/proyecto_dect_final/firmware/esp32_gateway/sdkconfig'
-- Found Git: /usr/bin/git (found version "2.54.0")
-- Component directory /opt/esp/esp-idf/components/idf_test does not contain a CMakeLists.txt file. No component will be added
-- Minimal build - OFF
-- The C compiler identification is GNU 15.2.0
-- The CXX compiler identification is GNU 15.2.0
-- The ASM compiler identification is GNU
-- Found assembler: /home/robbie/.espressif/tools/xtensa-esp-elf/esp-15.2.0_20251204/xtensa-esp-elf/bin/xtensa-esp32-elf-gcc
-- Detecting C compiler ABI info
-- Detecting C compiler ABI info - done
-- Check for working C compiler: /home/robbie/.espressif/tools/xtensa-esp-elf/esp-15.2.0_20251204/xtensa-esp-elf/bin/xtensa-esp32-elf-gcc - skipped
-- Detecting C compile features
-- Detecting C compile features - done
-- Detecting CXX compiler ABI info
-- Detecting CXX compiler ABI info - done
-- Check for working CXX compiler: /home/robbie/.espressif/tools/xtensa-esp-elf/esp-15.2.0_20251204/xtensa-esp-elf/bin/xtensa-esp32-elf-g++ - skipped
-- Detecting CXX compile features
-- Detecting CXX compile features - done
-- Building ESP-IDF components for target esp32
NOTICE: Processing 2 dependencies:
NOTICE: [1/2] espressif/w5500 (1.0.1)
NOTICE: [2/2] idf (6.1.0)
-- ESP-TEE is currently supported only on the esp32c6;esp32h2;esp32c5;esp32c61 SoCs
-- KCONFIG_REPORT_VERBOSITY not set, using default
-- Project sdkconfig file /srv/dect2/proyecto_dect_final/firmware/esp32_gateway/sdkconfig
-- Compiler supported targets: xtensa-esp-elf
-- Detecting C compiler ABI info
-- Detecting C compiler ABI info - done
-- Detecting CXX compiler ABI info
-- Detecting CXX compiler ABI info - done
-- Detecting C compiler ABI info
-- Detecting C compiler ABI info - done
-- Detecting CXX compiler ABI info
-- Detecting CXX compiler ABI info - done
-- App "esp32_gateway" version: 7eab8b1-dirty
-- Found Python3: /home/robbie/.espressif/python_env/idf6.1_py3.14_env/bin/python (found version "3.14.5") found components: Interpreter
-- Performing Test CMAKE_HAVE_LIBC_PTHREAD
-- Performing Test CMAKE_HAVE_LIBC_PTHREAD - Success
-- Found Threads: TRUE
-- Performing Test C_COMPILER_SUPPORTS_WFORMAT_SIGNEDNESS
-- Performing Test C_COMPILER_SUPPORTS_WFORMAT_SIGNEDNESS - Success
-- Setting up mbedtls configuration
-- Linkage type is PUBLIC
-- Adding linker script /opt/esp/esp-idf/components/esp_system/ld/esp32/memory.ld.in
--   -> Preprocessing .in script: /opt/esp/esp-idf/components/esp_system/ld/esp32/memory.ld.in
-- Adding linker script /opt/esp/esp-idf/components/esp_system/ld/esp32/sections.ld.in
--   -> Preprocessing .in script: /opt/esp/esp-idf/components/esp_system/ld/esp32/sections.ld.in
--   -> Applying ldgen processing: /srv/dect2/proyecto_dect_final/firmware/esp32_gateway/build/esp-idf/esp_system/ld/sections.ld.in
-- Adding linker script /opt/esp/esp-idf/components/esp_rom/esp32/ld/esp32.rom.ld
-- Adding linker script /opt/esp/esp-idf/components/esp_rom/esp32/ld/esp32.rom.api.ld
-- Adding linker script /opt/esp/esp-idf/components/esp_rom/esp32/ld/esp32.rom.libgcc.ld
-- Adding linker script /opt/esp/esp-idf/components/esp_rom/esp32/ld/esp32.rom.libc-funcs.ld
-- Adding linker script /opt/esp/esp-idf/components/soc/esp32/ld/esp32.peripherals.ld
-- Adding linker script /opt/esp/esp-idf/components/esp_hal_regi2c/esp32/rom.regi2c.ld
-- Component idf::esp_trace will be linked with -Wl,--whole-archive
-- Components: app_trace app_update bootloader bootloader_support bt cmock console cxx driver efuse esp-tls esp_adc esp_app_format esp_asrc_adapter esp_blockdev esp_blockdev_util esp_bootloader_format esp_coex esp_common esp_driver_ana_cmpr esp_driver_bitscrambler esp_driver_cam esp_driver_cordic esp_driver_dac esp_driver_dma esp_driver_gpio esp_driver_gptimer esp_driver_i2c esp_driver_i2s esp_driver_i3c esp_driver_isp esp_driver_jpeg esp_driver_ledc esp_driver_mcpwm esp_driver_parlio esp_driver_pcnt esp_driver_ppa esp_driver_rmt esp_driver_sd_intf esp_driver_sdio esp_driver_sdm esp_driver_sdmmc esp_driver_sdspi esp_driver_spi esp_driver_touch_sens esp_driver_tsens esp_driver_twai esp_driver_uart esp_driver_usb_serial_jtag esp_eth esp_event esp_gdbstub esp_hal_ana_cmpr esp_hal_ana_conv esp_hal_asrc esp_hal_cam esp_hal_clock esp_hal_cordic esp_hal_dma esp_hal_emac esp_hal_gpio esp_hal_gpspi esp_hal_i2c esp_hal_i2s esp_hal_i3c esp_hal_ieee802154 esp_hal_jpeg esp_hal_lcd esp_hal_ledc esp_hal_mcpwm esp_hal_mspi esp_hal_parlio esp_hal_pcnt esp_hal_pmu esp_hal_ppa esp_hal_regi2c esp_hal_rmt esp_hal_rtc_timer esp_hal_sd esp_hal_security esp_hal_systimer esp_hal_timg esp_hal_touch_sens esp_hal_twai esp_hal_uart esp_hal_usb esp_hal_wdt esp_hid esp_http_client esp_http_server esp_https_ota esp_https_server esp_hw_support esp_lcd esp_libc esp_local_ctrl esp_mm esp_netif esp_netif_stack esp_partition esp_phy esp_pm esp_psram esp_ringbuf esp_rom esp_security esp_stdio esp_system esp_timer esp_trace esp_usb_cdc_rom_console esp_wifi espcoredump espressif__w5500 esptool_py fatfs freertos gw_bridge gw_dect gw_diag gw_eth gw_json gw_watchdog hal heap http_parser ieee802154 log lwip main mbedtls nvs_flash nvs_sec_provider openthread partition_table perfmon protobuf-c protocomm pthread rt sdmmc soc spi_flash spiffs tcp_transport ulp unity vfs wear_levelling wpa_supplicant xtensa
-- Component paths: /opt/esp/esp-idf/components/app_trace /opt/esp/esp-idf/components/app_update /opt/esp/esp-idf/components/bootloader /opt/esp/esp-idf/components/bootloader_support /opt/esp/esp-idf/components/bt /opt/esp/esp-idf/components/cmock /opt/esp/esp-idf/components/console /opt/esp/esp-idf/components/cxx /opt/esp/esp-idf/components/driver /opt/esp/esp-idf/components/efuse /opt/esp/esp-idf/components/esp-tls /opt/esp/esp-idf/components/esp_adc /opt/esp/esp-idf/components/esp_app_format /opt/esp/esp-idf/components/esp_asrc_adapter /opt/esp/esp-idf/components/esp_blockdev /opt/esp/esp-idf/components/esp_blockdev_util /opt/esp/esp-idf/components/esp_bootloader_format /opt/esp/esp-idf/components/esp_coex /opt/esp/esp-idf/components/esp_common /opt/esp/esp-idf/components/esp_driver_ana_cmpr /opt/esp/esp-idf/components/esp_driver_bitscrambler /opt/esp/esp-idf/components/esp_driver_cam /opt/esp/esp-idf/components/esp_driver_cordic /opt/esp/esp-idf/components/esp_driver_dac /opt/esp/esp-idf/components/esp_driver_dma /opt/esp/esp-idf/components/esp_driver_gpio /opt/esp/esp-idf/components/esp_driver_gptimer /opt/esp/esp-idf/components/esp_driver_i2c /opt/esp/esp-idf/components/esp_driver_i2s /opt/esp/esp-idf/components/esp_driver_i3c /opt/esp/esp-idf/components/esp_driver_isp /opt/esp/esp-idf/components/esp_driver_jpeg /opt/esp/esp-idf/components/esp_driver_ledc /opt/esp/esp-idf/components/esp_driver_mcpwm /opt/esp/esp-idf/components/esp_driver_parlio /opt/esp/esp-idf/components/esp_driver_pcnt /opt/esp/esp-idf/components/esp_driver_ppa /opt/esp/esp-idf/components/esp_driver_rmt /opt/esp/esp-idf/components/esp_driver_sd_intf /opt/esp/esp-idf/components/esp_driver_sdio /opt/esp/esp-idf/components/esp_driver_sdm /opt/esp/esp-idf/components/esp_driver_sdmmc /opt/esp/esp-idf/components/esp_driver_sdspi /opt/esp/esp-idf/components/esp_driver_spi /opt/esp/esp-idf/components/esp_driver_touch_sens /opt/esp/esp-idf/components/esp_driver_tsens /opt/esp/esp-idf/components/esp_driver_twai /opt/esp/esp-idf/components/esp_driver_uart /opt/esp/esp-idf/components/esp_driver_usb_serial_jtag /opt/esp/esp-idf/components/esp_eth /opt/esp/esp-idf/components/esp_event /opt/esp/esp-idf/components/esp_gdbstub /opt/esp/esp-idf/components/esp_hal_ana_cmpr /opt/esp/esp-idf/components/esp_hal_ana_conv /opt/esp/esp-idf/components/esp_hal_asrc /opt/esp/esp-idf/components/esp_hal_cam /opt/esp/esp-idf/components/esp_hal_clock /opt/esp/esp-idf/components/esp_hal_cordic /opt/esp/esp-idf/components/esp_hal_dma /opt/esp/esp-idf/components/esp_hal_emac /opt/esp/esp-idf/components/esp_hal_gpio /opt/esp/esp-idf/components/esp_hal_gpspi /opt/esp/esp-idf/components/esp_hal_i2c /opt/esp/esp-idf/components/esp_hal_i2s /opt/esp/esp-idf/components/esp_hal_i3c /opt/esp/esp-idf/components/esp_hal_ieee802154 /opt/esp/esp-idf/components/esp_hal_jpeg /opt/esp/esp-idf/components/esp_hal_lcd /opt/esp/esp-idf/components/esp_hal_ledc /opt/esp/esp-idf/components/esp_hal_mcpwm /opt/esp/esp-idf/components/esp_hal_mspi /opt/esp/esp-idf/components/esp_hal_parlio /opt/esp/esp-idf/components/esp_hal_pcnt /opt/esp/esp-idf/components/esp_hal_pmu /opt/esp/esp-idf/components/esp_hal_ppa /opt/esp/esp-idf/components/esp_hal_regi2c /opt/esp/esp-idf/components/esp_hal_rmt /opt/esp/esp-idf/components/esp_hal_rtc_timer /opt/esp/esp-idf/components/esp_hal_sd /opt/esp/esp-idf/components/esp_hal_security /opt/esp/esp-idf/components/esp_hal_systimer /opt/esp/esp-idf/components/esp_hal_timg /opt/esp/esp-idf/components/esp_hal_touch_sens /opt/esp/esp-idf/components/esp_hal_twai /opt/esp/esp-idf/components/esp_hal_uart /opt/esp/esp-idf/components/esp_hal_usb /opt/esp/esp-idf/components/esp_hal_wdt /opt/esp/esp-idf/components/esp_hid /opt/esp/esp-idf/components/esp_http_client /opt/esp/esp-idf/components/esp_http_server /opt/esp/esp-idf/components/esp_https_ota /opt/esp/esp-idf/components/esp_https_server /opt/esp/esp-idf/components/esp_hw_support /opt/esp/esp-idf/components/esp_lcd /opt/esp/esp-idf/components/esp_libc /opt/esp/esp-idf/components/esp_local_ctrl /opt/esp/esp-idf/components/esp_mm /opt/esp/esp-idf/components/esp_netif /opt/esp/esp-idf/components/esp_netif_stack /opt/esp/esp-idf/components/esp_partition /opt/esp/esp-idf/components/esp_phy /opt/esp/esp-idf/components/esp_pm /opt/esp/esp-idf/components/esp_psram /opt/esp/esp-idf/components/esp_ringbuf /opt/esp/esp-idf/components/esp_rom /opt/esp/esp-idf/components/esp_security /opt/esp/esp-idf/components/esp_stdio /opt/esp/esp-idf/components/esp_system /opt/esp/esp-idf/components/esp_timer /opt/esp/esp-idf/components/esp_trace /opt/esp/esp-idf/components/esp_usb_cdc_rom_console /opt/esp/esp-idf/components/esp_wifi /opt/esp/esp-idf/components/espcoredump /srv/dect2/proyecto_dect_final/firmware/esp32_gateway/managed_components/espressif__w5500 /opt/esp/esp-idf/components/esptool_py /opt/esp/esp-idf/components/fatfs /opt/esp/esp-idf/components/freertos /srv/dect2/proyecto_dect_final/firmware/esp32_gateway/components/gw_bridge /srv/dect2/proyecto_dect_final/firmware/esp32_gateway/components/gw_dect /srv/dect2/proyecto_dect_final/firmware/esp32_gateway/components/gw_diag /srv/dect2/proyecto_dect_final/firmware/esp32_gateway/components/gw_eth /srv/dect2/proyecto_dect_final/firmware/esp32_gateway/components/gw_json /srv/dect2/proyecto_dect_final/firmware/esp32_gateway/components/gw_watchdog /opt/esp/esp-idf/components/hal /opt/esp/esp-idf/components/heap /opt/esp/esp-idf/components/http_parser /opt/esp/esp-idf/components/ieee802154 /opt/esp/esp-idf/components/log /opt/esp/esp-idf/components/lwip /srv/dect2/proyecto_dect_final/firmware/esp32_gateway/main /opt/esp/esp-idf/components/mbedtls /opt/esp/esp-idf/components/nvs_flash /opt/esp/esp-idf/components/nvs_sec_provider /opt/esp/esp-idf/components/openthread /opt/esp/esp-idf/components/partition_table /opt/esp/esp-idf/components/perfmon /opt/esp/esp-idf/components/protobuf-c /opt/esp/esp-idf/components/protocomm /opt/esp/esp-idf/components/pthread /opt/esp/esp-idf/components/rt /opt/esp/esp-idf/components/sdmmc /opt/esp/esp-idf/components/soc /opt/esp/esp-idf/components/spi_flash /opt/esp/esp-idf/components/spiffs /opt/esp/esp-idf/components/tcp_transport /opt/esp/esp-idf/components/ulp /opt/esp/esp-idf/components/unity /opt/esp/esp-idf/components/vfs /opt/esp/esp-idf/components/wear_levelling /opt/esp/esp-idf/components/wpa_supplicant /opt/esp/esp-idf/components/xtensa
-- Configuring done (6.1s)
-- Generating done (0.6s)
-- Build files have been written to: /srv/dect2/proyecto_dect_final/firmware/esp32_gateway/build
[  0%] Preprocessing linker script /opt/esp/esp-idf/components/esp_system/ld/esp32/sections.ld.in -> /srv/dect2/proyecto_dect_final/firmware/esp32_gateway/build/esp-idf/esp_system/ld/sections.ld.in
[  0%] Generating ../../partition_table/partition-table.bin
[  0%] Preprocessing linker script /opt/esp/esp-idf/components/esp_system/ld/esp32/memory.ld.in -> /srv/dect2/proyecto_dect_final/firmware/esp32_gateway/build/esp-idf/esp_system/ld/memory.ld
[  0%] Generating project_elf_src_esp32.c
[  0%] Built target custom_bundle
[  0%] Built target _project_elf_src
[  0%] Built target sections_ld_in_preprocess
[  0%] Built target memory_ld_in_preprocess
[  0%] Building C object esp-idf/esp_https_ota/CMakeFiles/__idf_esp_https_ota.dir/src/esp_https_ota.c.obj
Partition table binary generated. Contents:
*******************************************************************************
# ESP-IDF Partition Table
# Name, Type, SubType, Offset, Size, Flags
nvs,data,nvs,0x9000,24K,
phy_init,data,phy,0xf000,4K,
factory,app,factory,0x10000,1M,
*******************************************************************************
[  0%] Built target partition_table_bin
[  0%] Creating directories for 'bootloader'
[  0%] No download step for 'bootloader'
[  0%] No update step for 'bootloader'
[  0%] Linking C static library libesp_https_ota.a
[  0%] No patch step for 'bootloader'
[  0%] Built target __idf_esp_https_ota
[  0%] Performing configure step for 'bootloader'
[  0%] Building C object esp-idf/esp_http_server/CMakeFiles/__idf_esp_http_server.dir/src/httpd_txrx.c.obj
[  0%] Building C object esp-idf/esp_http_server/CMakeFiles/__idf_esp_http_server.dir/src/httpd_sess.c.obj
[  0%] Building C object esp-idf/esp_http_server/CMakeFiles/__idf_esp_http_server.dir/src/httpd_main.c.obj
[  0%] Building C object esp-idf/esp_http_server/CMakeFiles/__idf_esp_http_server.dir/src/httpd_parse.c.obj
[  0%] Building C object esp-idf/esp_http_server/CMakeFiles/__idf_esp_http_server.dir/src/httpd_uri.c.obj
[  0%] Building C object esp-idf/esp_http_server/CMakeFiles/__idf_esp_http_server.dir/src/httpd_ws.c.obj
[  0%] Building C object esp-idf/esp_http_server/CMakeFiles/__idf_esp_http_server.dir/src/util/ctrl_sock.c.obj
-- Found Git: /usr/bin/git (found version "2.54.0")
-- Component directory /opt/esp/esp-idf/components/idf_test does not contain a CMakeLists.txt file. No component will be added
[  1%] Linking C static library libesp_http_server.a
[  1%] Built target __idf_esp_http_server
[  2%] Building C object esp-idf/esp_http_client/CMakeFiles/__idf_esp_http_client.dir/lib/http_header.c.obj
[  2%] Building C object esp-idf/esp_http_client/CMakeFiles/__idf_esp_http_client.dir/lib/http_auth.c.obj
[  2%] Building C object esp-idf/esp_http_client/CMakeFiles/__idf_esp_http_client.dir/esp_http_client.c.obj
[  2%] Building C object esp-idf/esp_http_client/CMakeFiles/__idf_esp_http_client.dir/lib/http_utils.c.obj
[  2%] Linking C static library libesp_http_client.a
[  2%] Built target __idf_esp_http_client
[  2%] Building C object esp-idf/tcp_transport/CMakeFiles/__idf_tcp_transport.dir/transport.c.obj
[  2%] Building C object esp-idf/tcp_transport/CMakeFiles/__idf_tcp_transport.dir/transport_internal.c.obj
[  2%] Building C object esp-idf/tcp_transport/CMakeFiles/__idf_tcp_transport.dir/transport_ssl.c.obj
[  2%] Building C object esp-idf/tcp_transport/CMakeFiles/__idf_tcp_transport.dir/transport_socks_proxy.c.obj
[  2%] Building C object esp-idf/tcp_transport/CMakeFiles/__idf_tcp_transport.dir/transport_ws.c.obj
-- Minimal build - OFF
-- The C compiler identification is GNU 15.2.0
-- The CXX compiler identification is GNU 15.2.0
-- The ASM compiler identification is GNU
-- Found assembler: /home/robbie/.espressif/tools/xtensa-esp-elf/esp-15.2.0_20251204/xtensa-esp-elf/bin/xtensa-esp32-elf-gcc
-- Detecting C compiler ABI info
[  2%] Linking C static library libtcp_transport.a
-- Detecting C compiler ABI info - done
-- Check for working C compiler: /home/robbie/.espressif/tools/xtensa-esp-elf/esp-15.2.0_20251204/xtensa-esp-elf/bin/xtensa-esp32-elf-gcc - skipped
-- Detecting C compile features
-- Detecting C compile features - done
-- Detecting CXX compiler ABI info
[  2%] Built target __idf_tcp_transport
[  2%] Building C object esp-idf/esp_adc/CMakeFiles/__idf_esp_adc.dir/adc_continuous.c.obj
[  2%] Building C object esp-idf/esp_adc/CMakeFiles/__idf_esp_adc.dir/adc_cali_curve_fitting.c.obj
[  2%] Building C object esp-idf/esp_adc/CMakeFiles/__idf_esp_adc.dir/adc_common.c.obj
[  2%] Building C object esp-idf/esp_adc/CMakeFiles/__idf_esp_adc.dir/esp32/adc_dma.c.obj
[  3%] Building C object esp-idf/esp_adc/CMakeFiles/__idf_esp_adc.dir/esp32/adc_cali_line_fitting.c.obj
[  3%] Building C object esp-idf/esp_adc/CMakeFiles/__idf_esp_adc.dir/adc_oneshot.c.obj
[  3%] Building C object esp-idf/esp_adc/CMakeFiles/__idf_esp_adc.dir/adc_cali.c.obj
-- Detecting CXX compiler ABI info - done
-- Check for working CXX compiler: /home/robbie/.espressif/tools/xtensa-esp-elf/esp-15.2.0_20251204/xtensa-esp-elf/bin/xtensa-esp32-elf-g++ - skipped
-- Detecting CXX compile features
-- Detecting CXX compile features - done
[  3%] Linking C static library libesp_adc.a
[  3%] Built target __idf_esp_adc
[  3%] Building C object esp-idf/esp_driver_i2s/CMakeFiles/__idf_esp_driver_i2s.dir/i2s_pdm.c.obj
[  3%] Building C object esp-idf/esp_driver_i2s/CMakeFiles/__idf_esp_driver_i2s.dir/i2s_common.c.obj
[  3%] Building C object esp-idf/esp_driver_i2s/CMakeFiles/__idf_esp_driver_i2s.dir/i2s_platform.c.obj
[  3%] Building C object esp-idf/esp_driver_i2s/CMakeFiles/__idf_esp_driver_i2s.dir/i2s_std.c.obj
-- Building ESP-IDF components for target esp32
[  4%] Linking C static library libesp_driver_i2s.a
[  4%] Built target __idf_esp_driver_i2s
[  4%] Building C object esp-idf/esp-tls/CMakeFiles/__idf_esp-tls.dir/esp_tls.c.obj
[  5%] Building C object esp-idf/esp-tls/CMakeFiles/__idf_esp-tls.dir/esp_tls_error_capture.c.obj
[  5%] Building C object esp-idf/esp-tls/CMakeFiles/__idf_esp-tls.dir/esp-tls-crypto/esp_tls_crypto.c.obj
[  5%] Building C object esp-idf/esp-tls/CMakeFiles/__idf_esp-tls.dir/esp_tls_platform_port.c.obj
[  5%] Building C object esp-idf/esp-tls/CMakeFiles/__idf_esp-tls.dir/esp_tls_mbedtls.c.obj
[  5%] Linking C static library libesp-tls.a
[  5%] Built target __idf_esp-tls
[  5%] Building C object esp-idf/http_parser/CMakeFiles/__idf_http_parser.dir/http_parser.c.obj
-- ESP-TEE is currently supported only on the esp32c6;esp32h2;esp32c5;esp32c61 SoCs
[  5%] Linking C static library libhttp_parser.a
[  5%] Built target __idf_http_parser
[  5%] Building C object esp-idf/esp_hal_i2c/CMakeFiles/__idf_esp_hal_i2c.dir/esp32/i2c_periph.c.obj
[  6%] Building C object esp-idf/esp_hal_i2c/CMakeFiles/__idf_esp_hal_i2c.dir/i2c_hal.c.obj
[  6%] Building C object esp-idf/esp_hal_i2c/CMakeFiles/__idf_esp_hal_i2c.dir/i2c_hal_iram.c.obj
[  6%] Linking C static library libesp_hal_i2c.a
[  6%] Built target __idf_esp_hal_i2c
[  6%] Building C object esp-idf/esp_gdbstub/CMakeFiles/__idf_esp_gdbstub.dir/src/packet.c.obj
[  6%] Building C object esp-idf/esp_gdbstub/CMakeFiles/__idf_esp_gdbstub.dir/src/gdbstub_transport.c.obj
[  6%] Building C object esp-idf/esp_gdbstub/CMakeFiles/__idf_esp_gdbstub.dir/src/gdbstub.c.obj
[  6%] Building C object esp-idf/esp_gdbstub/CMakeFiles/__idf_esp_gdbstub.dir/src/port/xtensa/gdbstub_xtensa.c.obj
[  6%] Building ASM object esp-idf/esp_gdbstub/CMakeFiles/__idf_esp_gdbstub.dir/src/port/xtensa/gdbstub-entry.S.obj
[  6%] Building ASM object esp-idf/esp_gdbstub/CMakeFiles/__idf_esp_gdbstub.dir/src/port/xtensa/xt_debugexception.S.obj
[  6%] Linking C static library libesp_gdbstub.a
[  6%] Built target __idf_esp_gdbstub
[  6%] Building C object esp-idf/esp_wifi/CMakeFiles/__idf_esp_wifi.dir/src/smartconfig.c.obj
[  7%] Building C object esp-idf/esp_wifi/CMakeFiles/__idf_esp_wifi.dir/src/mesh_event.c.obj
[  7%] Building C object esp-idf/esp_wifi/CMakeFiles/__idf_esp_wifi.dir/src/wifi_init.c.obj
[  7%] Building C object esp-idf/esp_wifi/CMakeFiles/__idf_esp_wifi.dir/src/lib_printf.c.obj
[  7%] Building C object esp-idf/esp_wifi/CMakeFiles/__idf_esp_wifi.dir/src/wifi_default.c.obj
[  7%] Building C object esp-idf/esp_wifi/CMakeFiles/__idf_esp_wifi.dir/src/wifi_netif.c.obj
[  7%] Building C object esp-idf/esp_wifi/CMakeFiles/__idf_esp_wifi.dir/src/wifi_default_ap.c.obj
[  7%] Building C object esp-idf/esp_wifi/CMakeFiles/__idf_esp_wifi.dir/src/ftm_load_calibration.c.obj
[  7%] Building C object esp-idf/esp_wifi/CMakeFiles/__idf_esp_wifi.dir/esp32/esp_adapter.c.obj
[  7%] Building C object esp-idf/esp_wifi/CMakeFiles/__idf_esp_wifi.dir/regulatory/esp_wifi_regulatory.c.obj
[  7%] Building C object esp-idf/esp_wifi/CMakeFiles/__idf_esp_wifi.dir/src/smartconfig_ack.c.obj
[  8%] Building C object esp-idf/esp_wifi/CMakeFiles/__idf_esp_wifi.dir/remote/esp_wifi_remote_weak.c.obj
[  8%] Building C object esp-idf/esp_wifi/CMakeFiles/__idf_esp_wifi.dir/remote/esp_eap_client_remote_weak.c.obj
[  8%] Building C object esp-idf/esp_wifi/CMakeFiles/__idf_esp_wifi.dir/remote/esp_wifi_remote_net2.c.obj
-- KCONFIG_REPORT_VERBOSITY not set, using default
-- Project sdkconfig file /srv/dect2/proyecto_dect_final/firmware/esp32_gateway/sdkconfig
[  8%] Linking C static library libesp_wifi.a
[  8%] Built target __idf_esp_wifi
[  8%] Building C object esp-idf/esp_coex/CMakeFiles/__idf_esp_coex.dir/src/coexist_debug.c.obj
[  8%] Building C object esp-idf/esp_coex/CMakeFiles/__idf_esp_coex.dir/esp32/esp_coex_adapter.c.obj
[  9%] Building C object esp-idf/esp_coex/CMakeFiles/__idf_esp_coex.dir/src/coexist_debug_diagram.c.obj
[  9%] Linking C static library libesp_coex.a
[  9%] Built target __idf_esp_coex
-- Compiler supported targets: xtensa-esp-elf
-- Detecting C compiler ABI info
[  9%] Building C object esp-idf/wpa_supplicant/CMakeFiles/__idf_wpa_supplicant.dir/src/ap/ieee802_1x.c.obj
[  9%] Building C object esp-idf/wpa_supplicant/CMakeFiles/__idf_wpa_supplicant.dir/src/ap/wpa_auth_ie.c.obj
[  9%] Building C object esp-idf/wpa_supplicant/CMakeFiles/__idf_wpa_supplicant.dir/src/ap/wpa_auth.c.obj
[  9%] Building C object esp-idf/wpa_supplicant/CMakeFiles/__idf_wpa_supplicant.dir/src/ap/ap_config.c.obj
[  9%] Building C object esp-idf/wpa_supplicant/CMakeFiles/__idf_wpa_supplicant.dir/src/ap/sta_info.c.obj
[  9%] Building C object esp-idf/wpa_supplicant/CMakeFiles/__idf_wpa_supplicant.dir/port/os_xtensa.c.obj
[  9%] Building C object esp-idf/wpa_supplicant/CMakeFiles/__idf_wpa_supplicant.dir/src/ap/pmksa_cache_auth.c.obj
[  9%] Building C object esp-idf/wpa_supplicant/CMakeFiles/__idf_wpa_supplicant.dir/port/eloop.c.obj
[  9%] Building C object esp-idf/wpa_supplicant/CMakeFiles/__idf_wpa_supplicant.dir/src/ap/ieee802_11.c.obj
-- Detecting C compiler ABI info - done
[ 10%] Building C object esp-idf/wpa_supplicant/CMakeFiles/__idf_wpa_supplicant.dir/src/ap/comeback_token.c.obj
-- Detecting CXX compiler ABI info
[ 10%] Building C object esp-idf/wpa_supplicant/CMakeFiles/__idf_wpa_supplicant.dir/src/common/sae.c.obj
[ 10%] Building C object esp-idf/wpa_supplicant/CMakeFiles/__idf_wpa_supplicant.dir/src/common/dragonfly.c.obj
[ 10%] Building C object esp-idf/wpa_supplicant/CMakeFiles/__idf_wpa_supplicant.dir/src/common/wpa_common.c.obj
[ 10%] Building C object esp-idf/wpa_supplicant/CMakeFiles/__idf_wpa_supplicant.dir/src/utils/bitfield.c.obj
-- Detecting CXX compiler ABI info - done
[ 10%] Building C object esp-idf/wpa_supplicant/CMakeFiles/__idf_wpa_supplicant.dir/src/crypto/aes-siv.c.obj
[ 10%] Building C object esp-idf/wpa_supplicant/CMakeFiles/__idf_wpa_supplicant.dir/src/crypto/sha256-kdf.c.obj
[ 10%] Building C object esp-idf/wpa_supplicant/CMakeFiles/__idf_wpa_supplicant.dir/src/crypto/ccmp.c.obj
[ 10%] Building C object esp-idf/wpa_supplicant/CMakeFiles/__idf_wpa_supplicant.dir/src/crypto/aes-gcm.c.obj
[ 10%] Building C object esp-idf/wpa_supplicant/CMakeFiles/__idf_wpa_supplicant.dir/src/crypto/crypto_ops.c.obj
[ 11%] Building C object esp-idf/wpa_supplicant/CMakeFiles/__idf_wpa_supplicant.dir/src/crypto/dh_group5.c.obj
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

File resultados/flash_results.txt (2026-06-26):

[  0%] Built target memory_ld_in_preprocess
[  0%] Built target custom_bundle
[  0%] Built target _project_elf_src
[  0%] Built target partition_table_bin
[  0%] Built target sections_ld_in_preprocess
[  0%] Performing build step for 'bootloader'
[  0%] Built target __idf_esp_https_ota
[  1%] Built target __idf_esp_http_server
[  2%] Built target bootloader_memory_ld_in_preprocess
[  2%] Built target bootloader_sections_ld_in_preprocess
[  9%] Built target __idf_log
[ 10%] Built target _project_elf_src
[  2%] Built target __idf_esp_http_client
[ 17%] Built target __idf_esp_rom
[  2%] Built target __idf_tcp_transport
[ 18%] Built target __idf_esp_common
[  3%] Built target __idf_esp_adc
[ 25%] Built target __idf_esp_hw_support
[  4%] Built target __idf_esp_driver_i2s
[ 26%] Built target __idf_esp_system
[  5%] Built target __idf_esp-tls
[ 32%] Built target __idf_efuse
[  5%] Built target __idf_http_parser
[  6%] Built target __idf_esp_hal_i2c
[ 50%] Built target __idf_bootloader_support
[  6%] Built target __idf_esp_gdbstub
[ 52%] Built target __idf_esp_security
[ 54%] Built target __idf_esp_hal_security
[  8%] Built target __idf_esp_wifi
[  9%] Built target __idf_esp_coex
[ 59%] Built target __idf_esp_hal_ana_conv
[ 61%] Built target __idf_esp_hal_i2s
[ 64%] Built target __idf_esp_hal_uart
[ 17%] Built target __idf_wpa_supplicant
[ 66%] Built target __idf_esp_hal_wdt
[ 18%] Built target __idf_esp_netif
[ 68%] Built target __idf_esp_hal_timg
[ 69%] Built target __idf_micro-ecc
[ 27%] Built target __idf_lwip
[ 70%] Built target __idf_esp_bootloader_format
[ 28%] Built target __idf_vfs
[ 71%] Built target __idf_spi_flash
[ 29%] Built target __idf_esp_phy
[ 73%] Built target __idf_esp_hal_mspi
[ 74%] Built target __idf_esp_hal_clock
[ 30%] Built target __idf_nvs_flash
[ 78%] Built target __idf_esp_hal_gpspi
[ 31%] Built target __idf_nvs_sec_provider
[ 79%] Built target __idf_esp_hal_pmu
[ 32%] Built target __idf_esp_event
[ 83%] Built target __idf_esp_hal_gpio
[ 32%] Built target __idf_esp_driver_uart
[ 87%] Built target __idf_hal
[ 32%] Built target __idf_esp_psram
[ 93%] Built target __idf_soc
[ 33%] Built target __idf_esp_ringbuf
[ 95%] Built target __idf_xtensa
[ 33%] Built target __idf_esp_timer
[ 97%] Built target __idf_main
[ 33%] Built target __idf_cxx
[ 98%] Built target bootloader.elf
[ 34%] Built target __idf_pthread
[100%] Built target gen_bootloader_binary
[ 37%] Built target __idf_esp_libc
[100%] Built target gen_project_binary
[ 39%] Built target __idf_freertos
[ 43%] Built target __idf_esp_hw_support
Bootloader binary size 0x6640 bytes. 0x9c0 bytes (9%) free.
[ 44%] Built target __idf_esp_hal_touch_sens
[100%] Built target bootloader_check_size
[ 44%] Built target __idf_esp_hal_pmu
[100%] Built target app
[ 45%] Built target __idf_esp_hal_gpio
[ 45%] No install step for 'bootloader'
[ 46%] Completed 'bootloader'
[ 47%] Built target __idf_soc
[ 48%] Built target __idf_heap
[ 48%] Built target bootloader
[ 49%] Built target __idf_log
[ 50%] Built target __idf_hal
[ 50%] Built target __idf_esp_rom
[ 50%] Built target __idf_esp_common
[ 54%] Built target __idf_esp_system
[ 56%] Built target __idf_spi_flash
[ 57%] Built target __idf_bootloader_support
[ 58%] Built target __idf_esp_hal_ana_conv
[ 58%] Built target __idf_esp_hal_i2s
[ 58%] Built target __idf_esp_hal_wdt
[ 58%] Built target __idf_esp_hal_timg
[ 58%] Built target everest
[ 59%] Built target p256-m
[ 64%] Built target builtin
[ 65%] Built target pqcp
[ 66%] Built target extras
[ 66%] Built target platform
[ 67%] Built target utilities
[ 70%] Built target tfpsacrypto
[ 72%] Built target mbedtls
[ 73%] Built target mbedx509
[ 74%] Built target __idf_mbedtls
[ 74%] Built target __idf_esp_driver_dma
[ 75%] Built target __idf_esp_mm
[ 75%] Built target __idf_esp_pm
[ 76%] Built target __idf_esp_hal_uart
[ 76%] Built target __idf_esp_driver_gpio
[ 77%] Built target __idf_esp_security
[ 78%] Built target __idf_efuse
[ 78%] Built target __idf_esp_partition
[ 78%] Built target __idf_app_update
[ 78%] Built target __idf_esp_bootloader_format
[ 78%] Built target __idf_esp_app_format
[ 78%] Built target __idf_esp_hal_security
[ 78%] Built target __idf_esp_hal_mspi
[ 78%] Built target __idf_esp_hal_clock
[ 78%] Built target __idf_esp_hal_gpspi
[ 78%] Built target __idf_esp_stdio
[ 78%] Built target __idf_xtensa
[ 78%] Built target __idf_esp_hal_emac
[ 79%] Built target __idf_unity
[ 79%] Built target __idf_esp_hal_twai
[ 79%] Built target __idf_esp_driver_spi
[ 80%] Built target __idf_gw_json
[ 80%] Built target __idf_esp_driver_gptimer
[ 82%] Built target __idf_console
[ 83%] Built target __idf_esp_driver_dac
[ 83%] Built target __idf_esp_driver_cam
[ 83%] Built target __idf_esp_blockdev_util
[ 84%] Built target __idf_esp_hal_ledc
[ 84%] Built target __idf_esp_driver_i2c
[ 85%] Built target __idf_esp_hal_pcnt
[ 85%] Built target __idf_esp_hal_mcpwm
[ 85%] Built target __idf_esp_hal_rmt
[ 86%] Built target __idf_esp_hal_sd
[ 87%] Built target __idf_esp_driver_touch_sens
[ 87%] Built target __idf_esp_driver_sdm
[ 87%] Built target __idf_esp_hal_lcd
[ 87%] Built target __idf_esp_driver_twai
[ 87%] Built target __idf_protobuf-c
[ 87%] Built target __idf_esp_hid
[ 88%] Built target __idf_esp_https_server
[ 88%] Built target __idf_wear_levelling
[ 88%] Built target __idf_perfmon
[ 88%] Built target __idf_rt
[ 89%] Built target __idf_gw_dect
[ 89%] Built target __idf_spiffs
[ 90%] Built target __idf_cmock
[ 91%] Built target __idf_esp_eth
[ 91%] Built target __idf_driver
[ 92%] Built target __idf_esp_driver_mcpwm
[ 92%] Built target __idf_esp_driver_ledc
[ 92%] Built target __idf_esp_driver_pcnt
[ 94%] Built target __idf_esp_driver_rmt
[ 94%] Built target __idf_sdmmc
[ 94%] Built target __idf_espressif__w5500
[ 94%] Built target __idf_esp_driver_sdio
[ 95%] Built target __idf_protocomm
[ 96%] Built target __idf_esp_lcd
[ 96%] Built target __idf_gw_eth
[ 96%] Built target __idf_esp_driver_sdspi
[ 96%] Built target __idf_esp_driver_sd_intf
[ 96%] Built target __idf_esp_local_ctrl
[ 96%] Built target __idf_gw_watchdog
[ 96%] Built target __idf_gw_bridge
[ 97%] Built target __idf_esp_driver_sdmmc
[ 98%] Built target __idf_gw_diag
[ 99%] Built target __idf_fatfs
[ 99%] Built target __idf_main
[ 99%] Built target __ldgen_output_sections.ld
[ 99%] Built target esp32_gateway.elf
[100%] Built target gen_esp32_gateway_binary
[100%] Built target gen_project_binary
esp32_gateway.bin binary size 0x22c50 bytes. Smallest app partition is 0x100000 bytes. 0xdd3b0 bytes (86%) free.
[100%] Built target app_check_size
[100%] Built target app
Adding "flash"'s dependency "all" to list of commands with default set of options.
Executing action: all (aliases: build)
Running make in directory /srv/dect2/proyecto_dect_final/firmware/esp32_gateway/build
Executing "make -j 10 all"...
Executing action: flash
Running make in directory /srv/dect2/proyecto_dect_final/firmware/esp32_gateway/build
Executing "make -j 10 flash"...
[  0%] Built target sections_ld_in_preprocess
[  0%] Built target _project_elf_src
[  0%] Built target custom_bundle
[  0%] Built target partition_table_bin
[  0%] Built target memory_ld_in_preprocess
[  0%] Performing build step for 'bootloader'
[  0%] Built target __idf_esp_https_ota
[  1%] Built target __idf_esp_http_server
[  1%] Built target _project_elf_src
[  2%] Built target bootloader_memory_ld_in_preprocess
[  3%] Built target bootloader_sections_ld_in_preprocess
[ 10%] Built target __idf_log
[  2%] Built target __idf_esp_http_client
[ 17%] Built target __idf_esp_rom
[  2%] Built target __idf_tcp_transport
[ 18%] Built target __idf_esp_common
[  3%] Built target __idf_esp_adc
[ 25%] Built target __idf_esp_hw_support
[  4%] Built target __idf_esp_driver_i2s
[ 26%] Built target __idf_esp_system
[  5%] Built target __idf_esp-tls
[ 32%] Built target __idf_efuse
[  5%] Built target __idf_http_parser
[ 50%] Built target __idf_bootloader_support
[  6%] Built target __idf_esp_hal_i2c
[ 52%] Built target __idf_esp_security
[  6%] Built target __idf_esp_gdbstub
[ 54%] Built target __idf_esp_hal_security
[  8%] Built target __idf_esp_wifi
[ 59%] Built target __idf_esp_hal_ana_conv
[  9%] Built target __idf_esp_coex
[ 61%] Built target __idf_esp_hal_i2s
[ 64%] Built target __idf_esp_hal_uart
[ 17%] Built target __idf_wpa_supplicant
[ 66%] Built target __idf_esp_hal_wdt
[ 18%] Built target __idf_esp_netif
[ 68%] Built target __idf_esp_hal_timg
[ 69%] Built target __idf_micro-ecc
[ 70%] Built target __idf_esp_bootloader_format
[ 27%] Built target __idf_lwip
[ 71%] Built target __idf_spi_flash
[ 28%] Built target __idf_vfs
[ 73%] Built target __idf_esp_hal_mspi
[ 29%] Built target __idf_esp_phy
[ 74%] Built target __idf_esp_hal_clock
[ 30%] Built target __idf_nvs_flash
[ 78%] Built target __idf_esp_hal_gpspi
[ 31%] Built target __idf_nvs_sec_provider
[ 79%] Built target __idf_esp_hal_pmu
[ 32%] Built target __idf_esp_event
[ 83%] Built target __idf_esp_hal_gpio
[ 32%] Built target __idf_esp_driver_uart
[ 87%] Built target __idf_hal
[ 32%] Built target __idf_esp_psram
[ 93%] Built target __idf_soc
[ 33%] Built target __idf_esp_ringbuf
[ 95%] Built target __idf_xtensa
[ 33%] Built target __idf_esp_timer
[ 97%] Built target __idf_main
[ 33%] Built target __idf_cxx
[ 98%] Built target bootloader.elf
[ 34%] Built target __idf_pthread
[100%] Built target gen_bootloader_binary
[ 37%] Built target __idf_esp_libc
[100%] Built target gen_project_binary
[ 39%] Built target __idf_freertos
[ 43%] Built target __idf_esp_hw_support
Bootloader binary size 0x6640 bytes. 0x9c0 bytes (9%) free.
[ 44%] Built target __idf_esp_hal_touch_sens
[100%] Built target bootloader_check_size
[ 44%] Built target __idf_esp_hal_pmu
[100%] Built target app
[ 45%] No install step for 'bootloader'
[ 45%] Built target __idf_esp_hal_gpio
[ 46%] Completed 'bootloader'
[ 47%] Built target __idf_soc
[ 48%] Built target __idf_heap
[ 48%] Built target bootloader
[ 49%] Built target __idf_log
[ 50%] Built target __idf_hal
[ 50%] Built target __idf_esp_rom
[ 50%] Built target __idf_esp_common
[ 54%] Built target __idf_esp_system
[ 56%] Built target __idf_spi_flash
[ 57%] Built target __idf_bootloader_support
[ 58%] Built target __idf_esp_hal_ana_conv
[ 58%] Built target __idf_esp_hal_i2s
[ 58%] Built target __idf_esp_hal_wdt
[ 58%] Built target __idf_esp_hal_timg
[ 58%] Built target everest
[ 59%] Built target p256-m
[ 64%] Built target builtin
[ 65%] Built target pqcp
[ 66%] Built target extras
[ 66%] Built target platform
[ 67%] Built target utilities
[ 70%] Built target tfpsacrypto
[ 72%] Built target mbedtls
[ 73%] Built target mbedx509
[ 74%] Built target __idf_mbedtls
[ 74%] Built target __idf_esp_driver_dma
[ 75%] Built target __idf_esp_mm
[ 75%] Built target __idf_esp_pm
[ 76%] Built target __idf_esp_hal_uart
[ 76%] Built target __idf_esp_driver_gpio
[ 77%] Built target __idf_esp_security
[ 78%] Built target __idf_efuse
[ 78%] Built target __idf_esp_partition
[ 78%] Built target __idf_app_update
[ 78%] Built target __idf_esp_bootloader_format
[ 78%] Built target __idf_esp_app_format
[ 78%] Built target __idf_esp_hal_security
[ 78%] Built target __idf_esp_hal_mspi
[ 78%] Built target __idf_esp_hal_clock
[ 78%] Built target __idf_esp_hal_gpspi
[ 78%] Built target __idf_esp_stdio
[ 78%] Built target __idf_xtensa
[ 78%] Built target __idf_esp_hal_emac
[ 79%] Built target __idf_esp_driver_gptimer
[ 79%] Built target __idf_gw_json
[ 80%] Built target __idf_unity
[ 82%] Built target __idf_console
[ 83%] Built target __idf_esp_driver_dac
[ 83%] Built target __idf_esp_hal_twai
[ 83%] Built target __idf_esp_driver_cam
[ 83%] Built target __idf_esp_driver_spi
[ 83%] Built target __idf_esp_blockdev_util
[ 83%] Built target __idf_esp_driver_i2c
[ 83%] Built target __idf_esp_hal_mcpwm
[ 83%] Built target __idf_esp_driver_sdm
[ 84%] Built target __idf_esp_hal_pcnt
[ 84%] Built target __idf_esp_hal_lcd
[ 85%] Built target __idf_esp_hal_ledc
[ 86%] Built target __idf_esp_driver_touch_sens
[ 87%] Built target __idf_esp_hal_sd
[ 87%] Built target __idf_esp_hal_rmt
[ 87%] Built target __idf_esp_hid
[ 87%] Built target __idf_perfmon
[ 88%] Built target __idf_wear_levelling
[ 88%] Built target __idf_rt
[ 89%] Built target __idf_spiffs
[ 90%] Built target __idf_esp_eth
[ 90%] Built target __idf_protobuf-c
[ 90%] Built target __idf_gw_dect
[ 90%] Built target __idf_esp_https_server
[ 91%] Built target __idf_driver
[ 91%] Built target __idf_cmock
[ 91%] Built target __idf_esp_driver_ledc
[ 91%] Built target __idf_esp_driver_pcnt
[ 91%] Built target __idf_esp_driver_sdio
[ 92%] Built target __idf_esp_driver_mcpwm
[ 93%] Built target __idf_sdmmc
[ 94%] Built target __idf_esp_driver_rmt
[ 94%] Built target __idf_esp_driver_twai
[ 95%] Built target __idf_esp_lcd
[ 96%] Built target __idf_esp_driver_sd_intf
[ 96%] Built target __idf_esp_driver_sdspi
[ 96%] Built target __idf_espressif__w5500
[ 96%] Built target __idf_protocomm
[ 97%] Built target __idf_esp_local_ctrl
[ 97%] Built target __idf_gw_eth
[ 97%] Built target __idf_esp_driver_sdmmc
[ 97%] Built target __idf_gw_bridge
[ 97%] Built target __idf_gw_watchdog
[ 98%] Built target __idf_fatfs
[ 99%] Built target __idf_gw_diag
[ 99%] Built target __idf_main
[ 99%] Built target __ldgen_output_sections.ld
[ 99%] Built target esp32_gateway.elf
[100%] Built target gen_esp32_gateway_binary
[100%] Built target gen_project_binary
esp32_gateway.bin binary size 0x22c50 bytes. Smallest app partition is 0x100000 bytes. 0xdd3b0 bytes (86%) free.
[100%] Built target app_check_size
[100%] Built target app
esptool --chip esp32 -p /dev/ttyUSB0 -b 115200 --before=default-reset --after=hard-reset write-flash --flash-mode dio --flash-freq 40m --flash-size 2MB 0x1000 bootloader/bootloader.bin 0x8000 partition_table/partition-table.bin 0x10000 esp32_gateway.bin --diff-with bootloader/bootloader_flashed.bin partition_table/partition-table_flashed.bin esp32_gateway_flashed.bin
esptool v5.3.dev3
Serial port /dev/ttyUSB0:
Connecting....
[1A[2K[1A[2KConnected to ESP32 on /dev/ttyUSB0:
Chip type:          ESP32-D0WD-V3 (revision v3.1)
Features:           Wi-Fi, BT, Dual Core + LP Core, 240MHz, Vref calibration in eFuse, Coding Scheme None
Crystal frequency:  40MHz
MAC:                28:56:2f:4b:68:dc

Uploading stub flasher...
Running stub flasher...
[1A[2K[1A[2KStub flasher running.

Configuring flash size...

Writing 'bootloader/bootloader.bin' at 0x00001000...
SHA digest in image updated.
SHA digest in image updated.
No changed sectors found, verifying if data is in flash...
[1A[2K'bootloader/bootloader.bin' at 0x00001000 verified.

Writing 'partition_table/partition-table.bin' at 0x00008000...
No changed sectors found, verifying if data is in flash...
[1A[2K'partition_table/partition-table.bin' at 0x00008000 verified.

Writing 'esp32_gateway.bin' at 0x00010000...
No changed sectors found, verifying if data is in flash...
[1A[2K'esp32_gateway.bin' at 0x00010000 verified.

Hard resetting via RTS pin...
[100%] Built target flash
Done

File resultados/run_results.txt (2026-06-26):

[  0%] Built target custom_bundle
[  0%] Built target sections_ld_in_preprocess
[  0%] Built target partition_table_bin
[  0%] Built target _project_elf_src
[  0%] Built target memory_ld_in_preprocess
[  0%] Performing build step for 'bootloader'
[  0%] Built target __idf_esp_https_ota
[  1%] Built target __idf_esp_http_server
[  2%] Built target bootloader_sections_ld_in_preprocess
[  2%] Built target bootloader_memory_ld_in_preprocess
[  9%] Built target __idf_log
[ 10%] Built target _project_elf_src
[  2%] Built target __idf_esp_http_client
[ 17%] Built target __idf_esp_rom
[  2%] Built target __idf_tcp_transport
[ 18%] Built target __idf_esp_common
[  3%] Built target __idf_esp_adc
[ 25%] Built target __idf_esp_hw_support
[  4%] Built target __idf_esp_driver_i2s
[ 26%] Built target __idf_esp_system
[  5%] Built target __idf_esp-tls
[ 32%] Built target __idf_efuse
[  5%] Built target __idf_http_parser
[ 50%] Built target __idf_bootloader_support
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

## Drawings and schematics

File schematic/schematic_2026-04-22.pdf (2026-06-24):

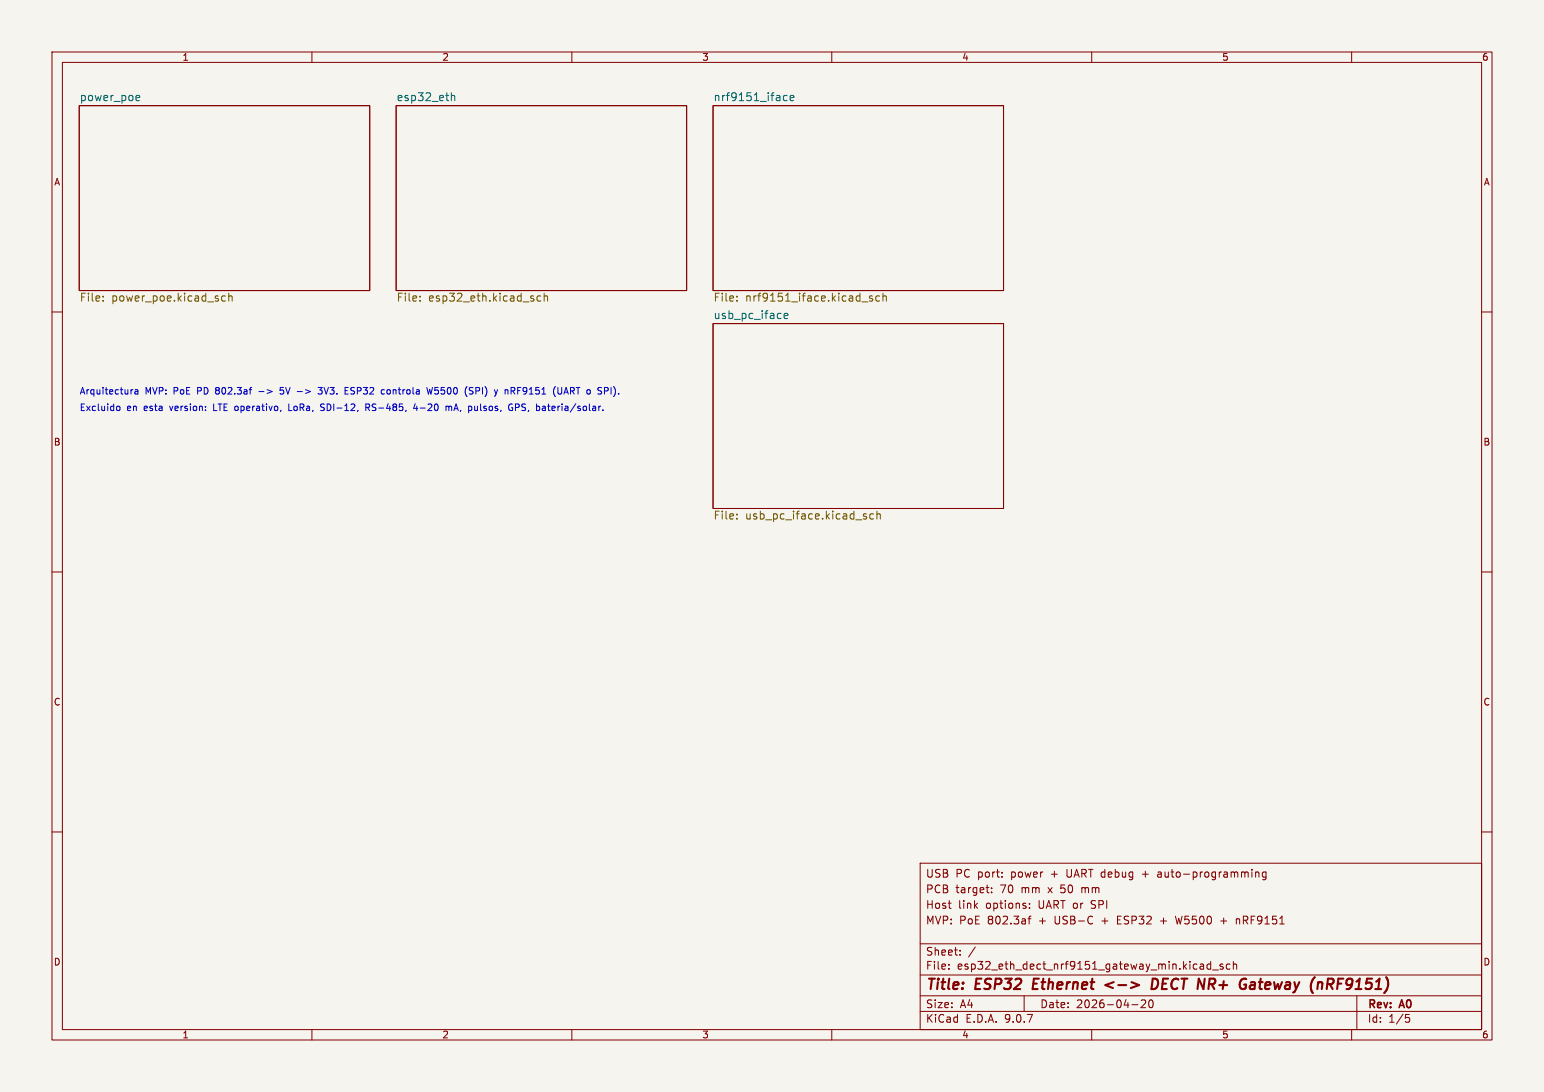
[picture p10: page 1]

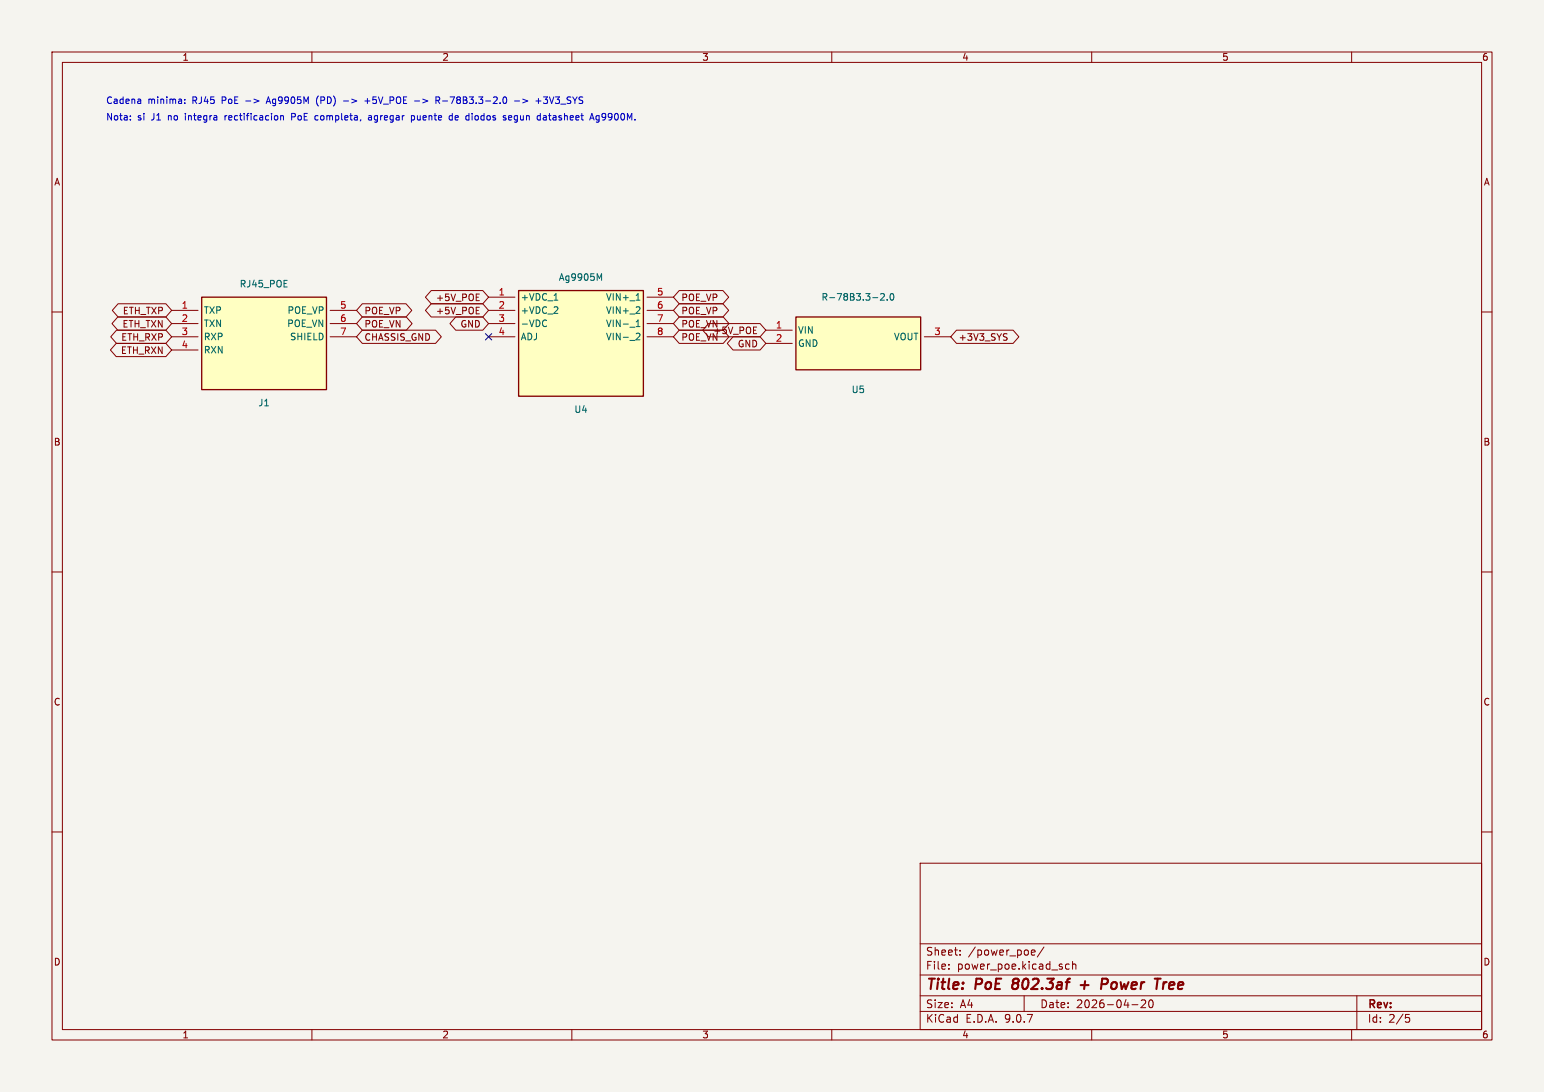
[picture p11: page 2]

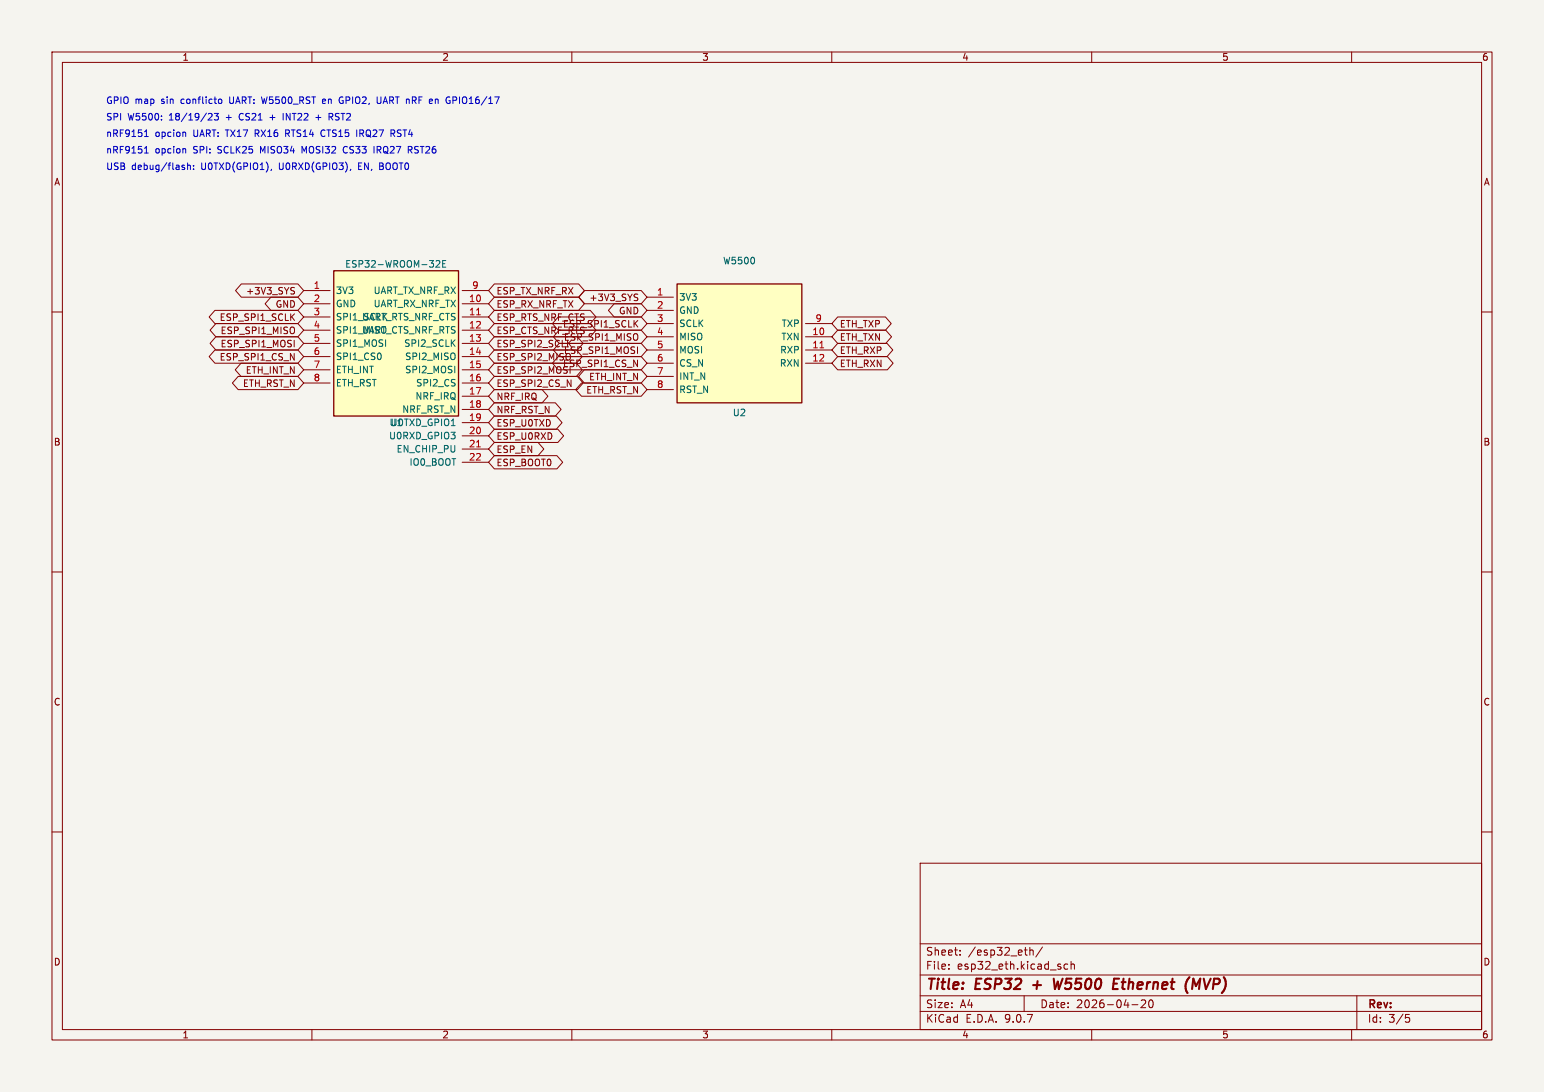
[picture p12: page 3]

Id: 3/5 Title: ESP32 + W5500 Ethernet (MVP) File: esp32_eth.kicad_sch Sheet: /esp32_eth/

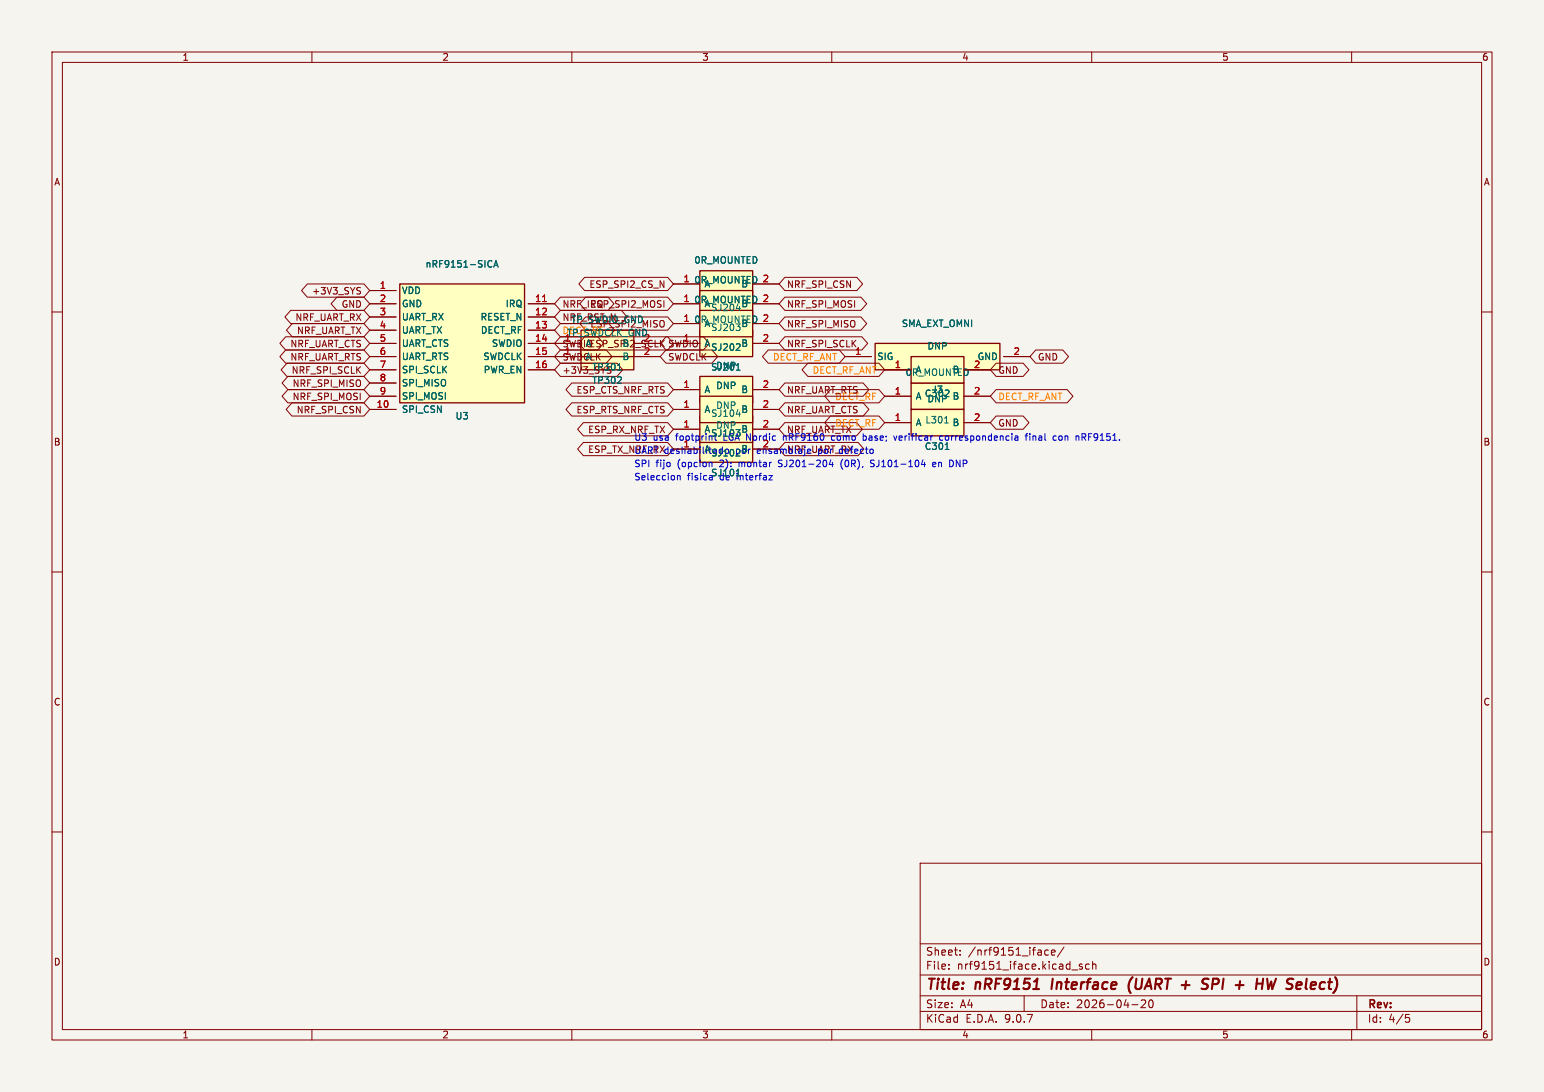
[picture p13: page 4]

Id: 4/5 Title: nRF9151 Interface (UART + SPI + HW Select) File: nrf9151_iface.kicad_sch Sheet: /nrf9151_iface/

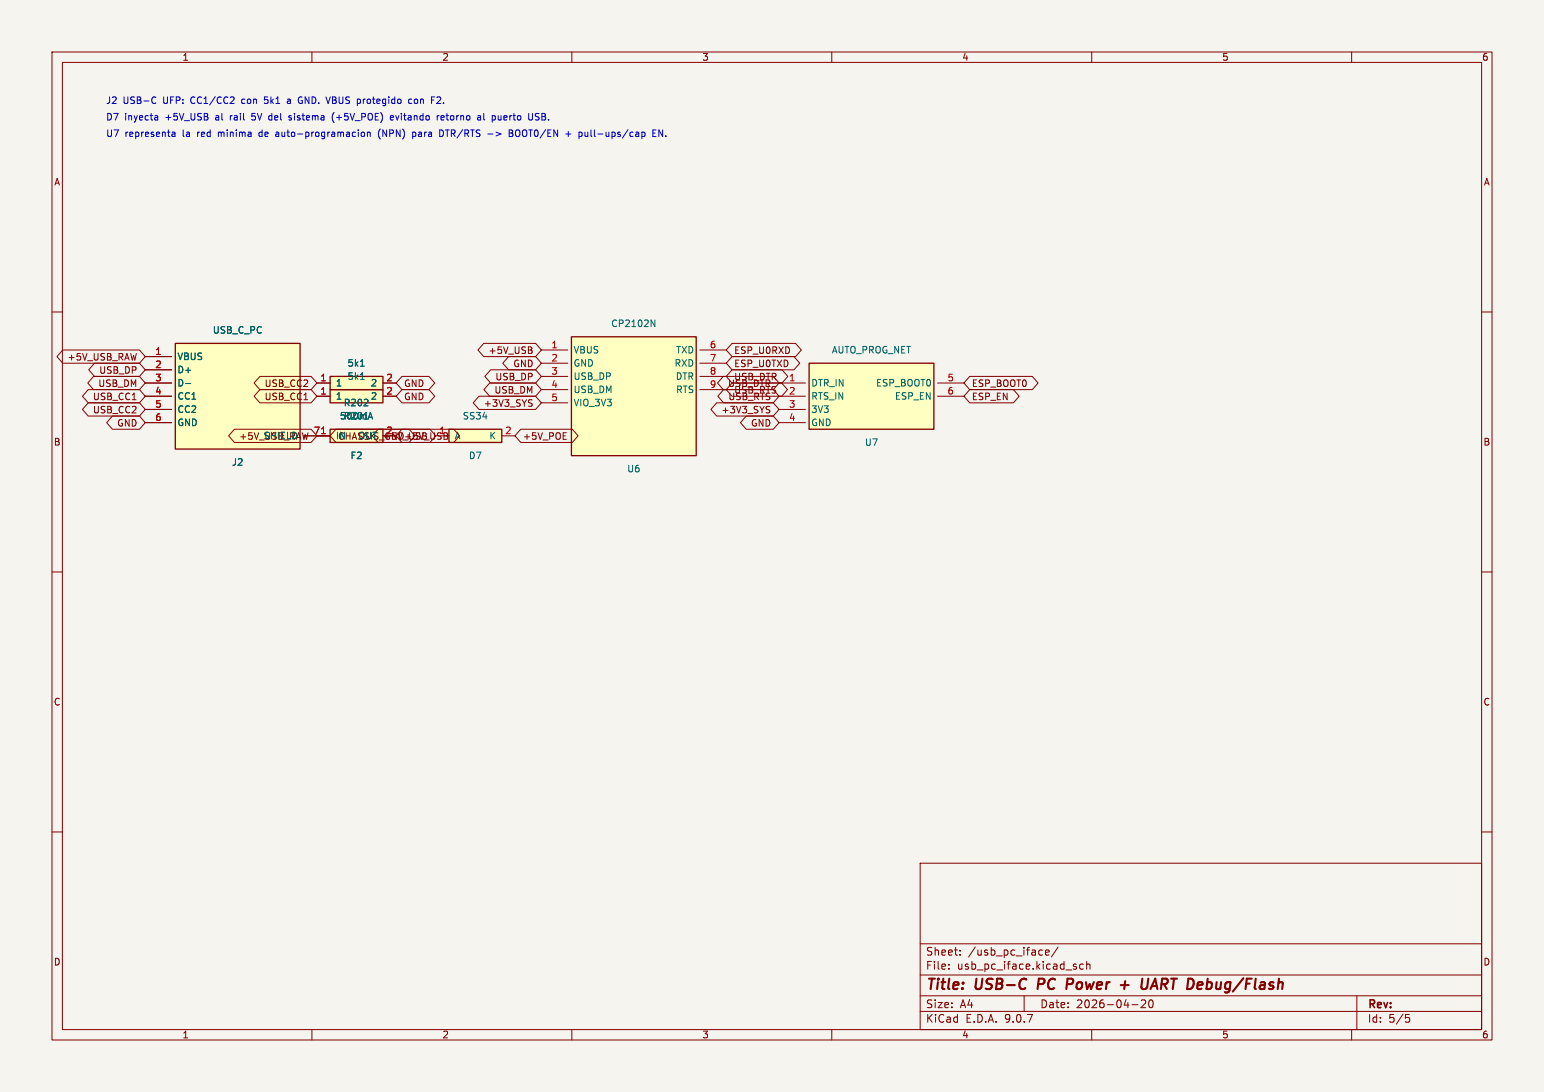
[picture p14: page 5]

File: usb_pc_iface.kicad_sch Sheet: /usb_pc_iface/
Id: 5/5 Title: USB-C PC Power + UART Debug/Flash

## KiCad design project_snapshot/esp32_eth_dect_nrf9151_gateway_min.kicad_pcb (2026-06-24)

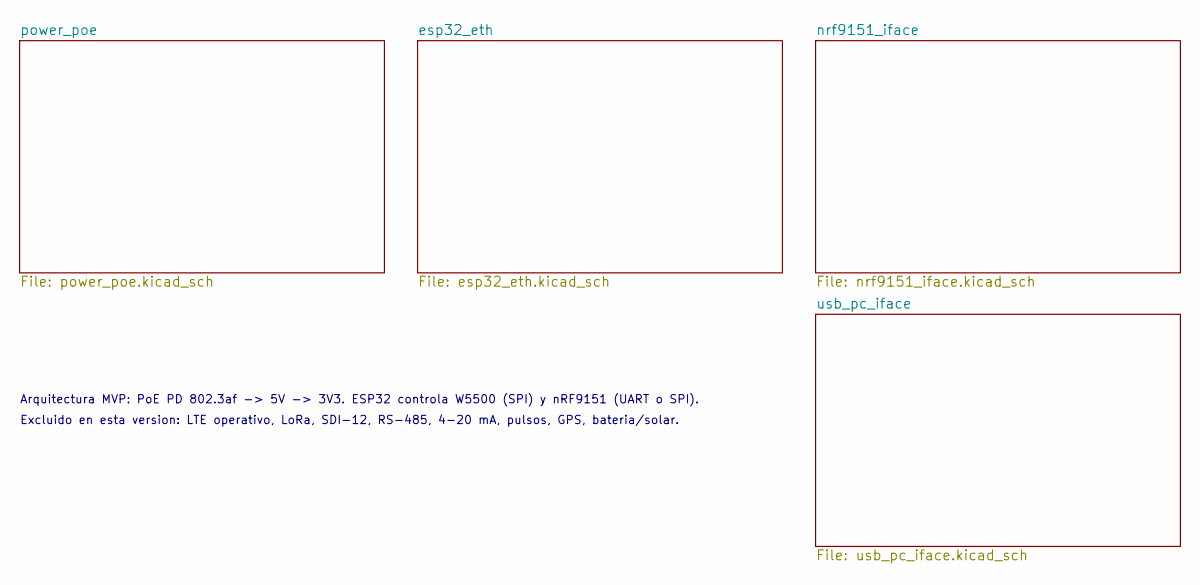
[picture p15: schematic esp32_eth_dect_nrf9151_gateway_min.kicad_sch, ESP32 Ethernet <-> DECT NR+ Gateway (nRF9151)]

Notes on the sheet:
Arquitectura MVP: PoE PD 802.3af -> 5V -> 3V3. ESP32 controla W5500 (SPI) y nRF9151 (UART o SPI).
Excluido en esta version: LTE operativo, LoRa, SDI-12, RS-485, 4-20 mA, pulsos, GPS, bateria/solar.

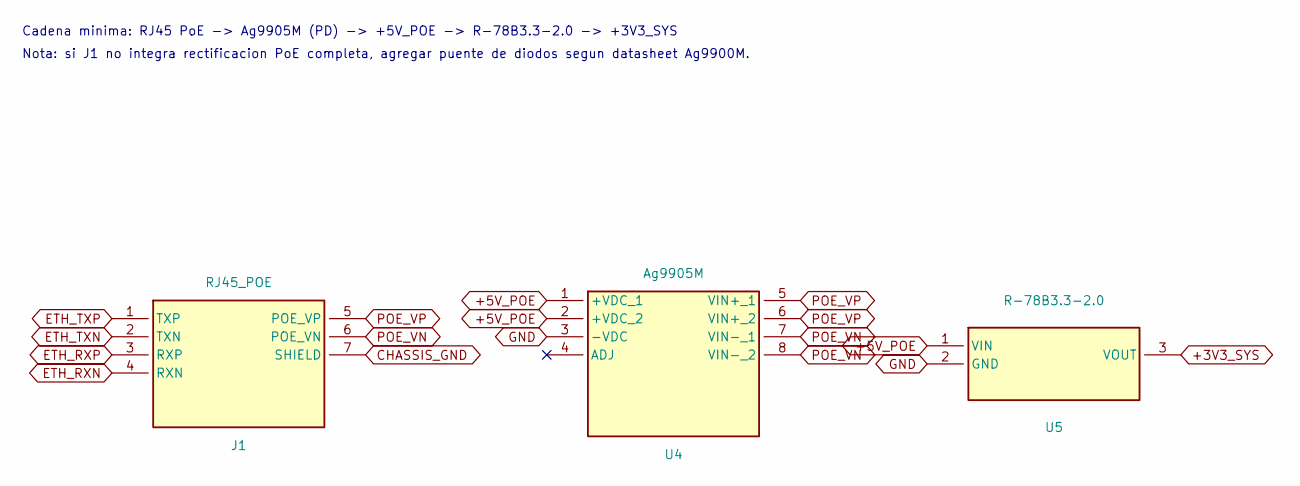
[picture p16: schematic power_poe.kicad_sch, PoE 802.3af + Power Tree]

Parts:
J1: RJ45_POE; RJ45_POE_MAG_PLACEHOLDER
U4: Ag9905M; POE_PD_8023AF_PLACEHOLDER
U5: R-78B3.3-2.0; BUCK_5V3V3_PLACEHOLDER

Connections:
+3V3_SYS: U5.3 (VOUT); also elsewhere on the board
+5V_POE: U4.1 (+VDC_1), U4.2 (+VDC_2), U5.1 (VIN); also elsewhere on the board
CHASSIS_GND: J1.7 (SHIELD); also elsewhere on the board
ETH_RXN: J1.4 (RXN); also elsewhere on the board
ETH_RXP: J1.3 (RXP); also elsewhere on the board
ETH_TXN: J1.2 (TXN); also elsewhere on the board
ETH_TXP: J1.1 (TXP); also elsewhere on the board
GND: U4.3 (-VDC), U5.2 (GND); also elsewhere on the board
POE_VN: J1.6 (POE_VN), U4.7 (VIN-_1), U4.8 (VIN-_2)
POE_VP: J1.5 (POE_VP), U4.5 (VIN+_1), U4.6 (VIN+_2)

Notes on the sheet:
Cadena minima: RJ45 PoE -> Ag9905M (PD) -> +5V_POE -> R-78B3.3-2.0 -> +3V3_SYS
Nota: si J1 no integra rectificacion PoE completa, agregar puente de diodos segun datasheet Ag9900M.

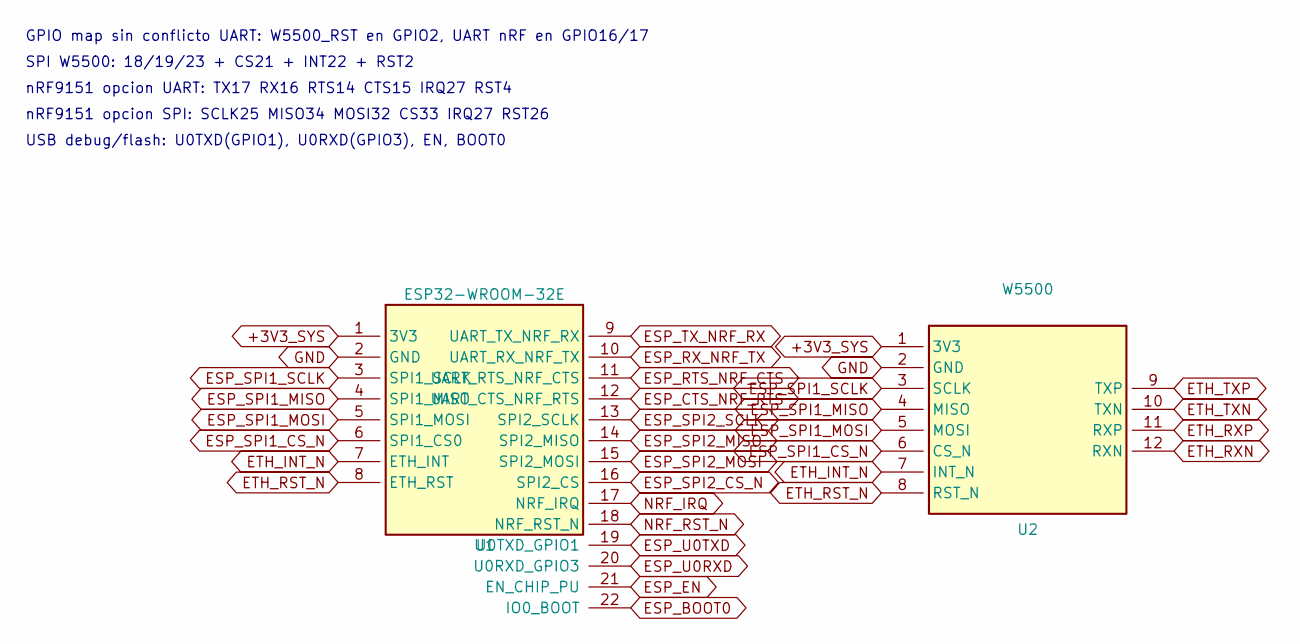
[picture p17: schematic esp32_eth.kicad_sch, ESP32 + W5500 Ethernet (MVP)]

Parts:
U1: ESP32-WROOM-32E; ESP32_WROOM_32E_PLACEHOLDER
U2: W5500; W5500_LQFP48_PLACEHOLDER

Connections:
+3V3_SYS: U1.1 (3V3), U2.1 (3V3); also elsewhere on the board
ESP_BOOT0: U1.22 (IO0_BOOT); also elsewhere on the board
ESP_CTS_NRF_RTS: U1.12 (UART_CTS_NRF_RTS); also elsewhere on the board
ESP_EN: U1.21 (EN_CHIP_PU); also elsewhere on the board
ESP_RTS_NRF_CTS: U1.11 (UART_RTS_NRF_CTS); also elsewhere on the board
ESP_RX_NRF_TX: U1.10 (UART_RX_NRF_TX); also elsewhere on the board
ESP_SPI1_CS_N: U1.6 (SPI1_CS0), U2.6 (CS_N)
ESP_SPI1_MISO: U1.4 (SPI1_MISO), U2.4 (MISO)
ESP_SPI1_MOSI: U1.5 (SPI1_MOSI), U2.5 (MOSI)
ESP_SPI1_SCLK: U1.3 (SPI1_SCLK), U2.3 (SCLK)
ESP_SPI2_CS_N: U1.16 (SPI2_CS); also elsewhere on the board
ESP_SPI2_MISO: U1.14 (SPI2_MISO); also elsewhere on the board
ESP_SPI2_MOSI: U1.15 (SPI2_MOSI); also elsewhere on the board
ESP_SPI2_SCLK: U1.13 (SPI2_SCLK); also elsewhere on the board
ESP_TX_NRF_RX: U1.9 (UART_TX_NRF_RX); also elsewhere on the board
ESP_U0RXD: U1.20 (U0RXD_GPIO3); also elsewhere on the board
ESP_U0TXD: U1.19 (U0TXD_GPIO1); also elsewhere on the board
ETH_INT_N: U1.7 (ETH_INT), U2.7 (INT_N)
ETH_RST_N: U1.8 (ETH_RST), U2.8 (RST_N)
ETH_RXN: U2.12 (RXN); also elsewhere on the board
ETH_RXP: U2.11 (RXP); also elsewhere on the board
ETH_TXN: U2.10 (TXN); also elsewhere on the board
ETH_TXP: U2.9 (TXP); also elsewhere on the board
GND: U1.2 (GND), U2.2 (GND); also elsewhere on the board
NRF_IRQ: U1.17 (NRF_IRQ); also elsewhere on the board
NRF_RST_N: U1.18 (NRF_RST_N); also elsewhere on the board

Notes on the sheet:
GPIO map sin conflicto UART: W5500_RST en GPIO2, UART nRF en GPIO16/17
SPI W5500: 18/19/23 + CS21 + INT22 + RST2
nRF9151 opcion UART: TX17 RX16 RTS14 CTS15 IRQ27 RST4
nRF9151 opcion SPI: SCLK25 MISO34 MOSI32 CS33 IRQ27 RST26
USB debug/flash: U0TXD(GPIO1), U0RXD(GPIO3), EN, BOOT0

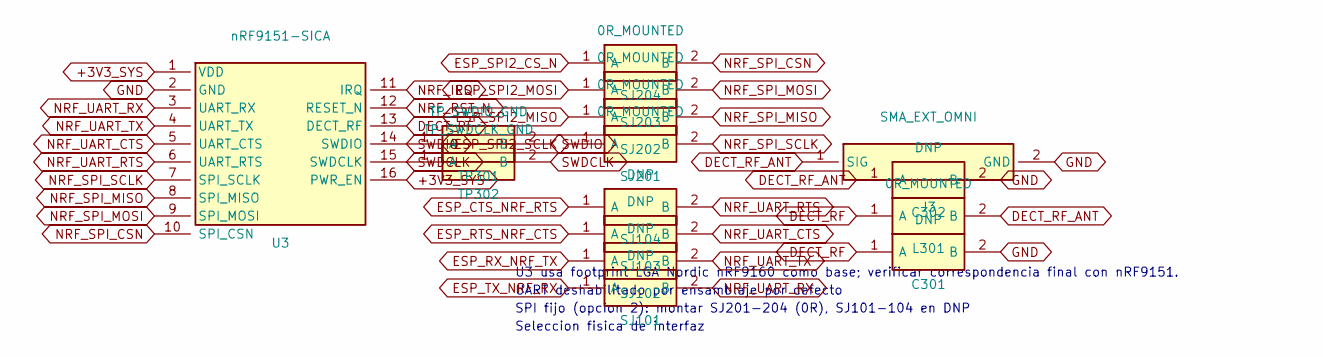
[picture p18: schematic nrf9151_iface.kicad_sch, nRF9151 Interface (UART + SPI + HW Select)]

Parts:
C301, C302: DNP; C_0402_1005Metric_RF
J3: SMA_EXT_OMNI; SMA_RF_PLACEHOLDER
L301: 0R_MOUNTED; L_0402_1005Metric
SJ101, SJ102, SJ103, SJ104: DNP; SJ_2PAD_PLACEHOLDER
SJ201, SJ202, SJ203, SJ204: 0R_MOUNTED; SJ_2PAD_PLACEHOLDER
TP301: TP_SWDIO_GND; PASSIVE_2PAD_PLACEHOLDER
TP302: TP_SWDCLK_GND; PASSIVE_2PAD_PLACEHOLDER
U3: nRF9151-SICA; NRF9151_SIP_PLACEHOLDER

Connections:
+3V3_SYS: U3.1 (VDD), U3.16 (PWR_EN); also elsewhere on the board
DECT_RF: C301.1 (A), L301.1 (A), U3.13 (DECT_RF)
DECT_RF_ANT: C302.1 (A), J3.1 (SIG), L301.2 (B)
ESP_CTS_NRF_RTS: SJ104.1 (A); also elsewhere on the board
ESP_RTS_NRF_CTS: SJ103.1 (A); also elsewhere on the board
ESP_RX_NRF_TX: SJ102.1 (A); also elsewhere on the board
ESP_SPI2_CS_N: SJ204.1 (A); also elsewhere on the board
ESP_SPI2_MISO: SJ202.1 (A); also elsewhere on the board
ESP_SPI2_MOSI: SJ203.1 (A); also elsewhere on the board
ESP_SPI2_SCLK: SJ201.1 (A); also elsewhere on the board
ESP_TX_NRF_RX: SJ101.1 (A); also elsewhere on the board
GND: C301.2 (B), C302.2 (B), J3.2 (GND), U3.2 (GND); also elsewhere on the board
NRF_IRQ: U3.11 (IRQ); also elsewhere on the board
NRF_RST_N: U3.12 (RESET_N); also elsewhere on the board
NRF_SPI_CSN: SJ204.2 (B), U3.10 (SPI_CSN)
NRF_SPI_MISO: SJ202.2 (B), U3.8 (SPI_MISO)
NRF_SPI_MOSI: SJ203.2 (B), U3.9 (SPI_MOSI)
NRF_SPI_SCLK: SJ201.2 (B), U3.7 (SPI_SCLK)
NRF_UART_CTS: SJ103.2 (B), U3.5 (UART_CTS)
NRF_UART_RTS: SJ104.2 (B), U3.6 (UART_RTS)
NRF_UART_RX: SJ101.2 (B), U3.3 (UART_RX)
NRF_UART_TX: SJ102.2 (B), U3.4 (UART_TX)
SWDCLK: TP302.1 (A), TP302.2 (B), U3.15 (SWDCLK)
SWDIO: TP301.1 (A), TP301.2 (B), U3.14 (SWDIO)

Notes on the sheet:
Seleccion fisica de interfaz
SPI fijo (opcion 2): montar SJ201-204 (0R), SJ101-104 en DNP
UART deshabilitado por ensamblaje por defecto
U3 usa footprint LGA Nordic nRF9160 como base; verificar correspondencia final con nRF9151.

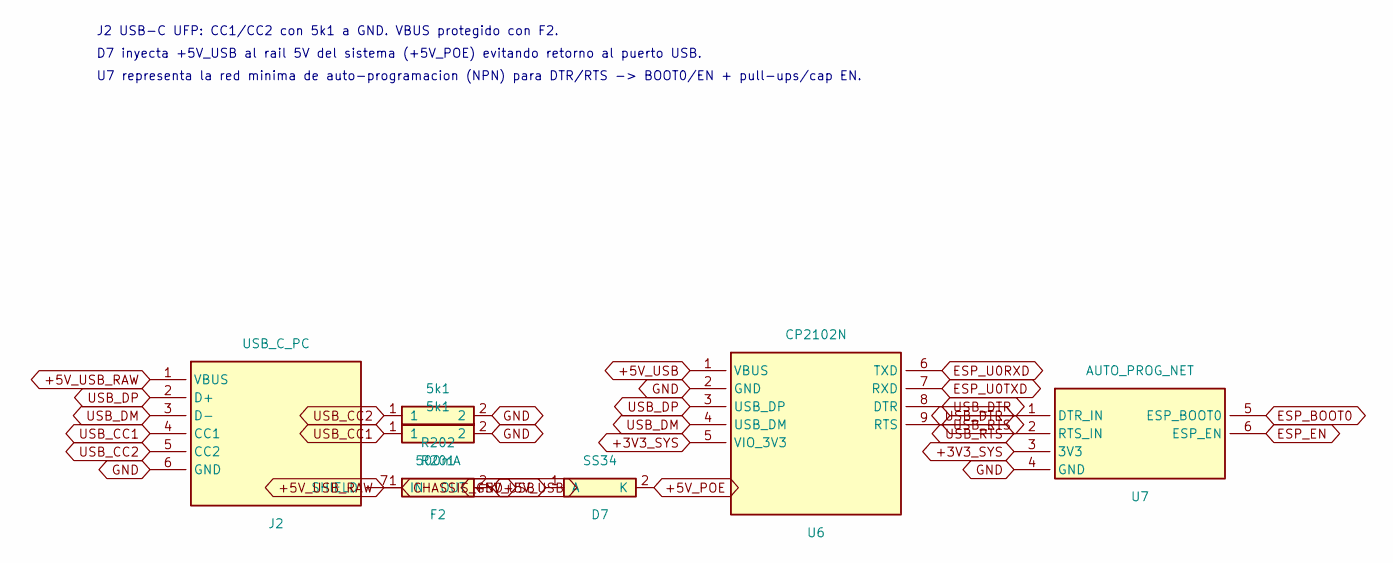
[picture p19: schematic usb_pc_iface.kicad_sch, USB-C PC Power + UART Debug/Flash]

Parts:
D7: SS34; PASSIVE_2PAD_PLACEHOLDER
F2: 500mA; PASSIVE_2PAD_PLACEHOLDER
J2: USB_C_PC; USB_C_PC_PLACEHOLDER
R201, R202: 5k1; PASSIVE_2PAD_PLACEHOLDER
U6: CP2102N; CP2102N_PLACEHOLDER
U7: AUTO_PROG_NET; AUTO_PROG_NET_PLACEHOLDER

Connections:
+3V3_SYS: U6.5 (VIO_3V3), U7.3 (3V3); also elsewhere on the board
+5V_POE: D7.2 (K); also elsewhere on the board
+5V_USB: D7.1 (A), F2.2 (OUT), U6.1 (VBUS)
+5V_USB_RAW: F2.1 (IN), J2.1 (VBUS)
CHASSIS_GND: J2.7 (SHIELD); also elsewhere on the board
ESP_BOOT0: U7.5 (ESP_BOOT0); also elsewhere on the board
ESP_EN: U7.6 (ESP_EN); also elsewhere on the board
ESP_U0RXD: U6.6 (TXD); also elsewhere on the board
ESP_U0TXD: U6.7 (RXD); also elsewhere on the board
GND: J2.6 (GND), R201.2, R202.2, U6.2 (GND), U7.4 (GND); also elsewhere on the board
USB_CC1: J2.4 (CC1), R201.1
USB_CC2: J2.5 (CC2), R202.1
USB_DM: J2.3 (D-), U6.4 (USB_DM)
USB_DP: J2.2 (D+), U6.3 (USB_DP)
USB_DTR: U6.8 (DTR), U7.1 (DTR_IN)
USB_RTS: U6.9 (RTS), U7.2 (RTS_IN)

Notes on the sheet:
J2 USB-C UFP: CC1/CC2 con 5k1 a GND. VBUS protegido con F2.
D7 inyecta +5V_USB al rail 5V del sistema (+5V_POE) evitando retorno al puerto USB.
U7 representa la red minima de auto-programacion (NPN) para DTR/RTS -> BOOT0/EN + pull-ups/cap EN.

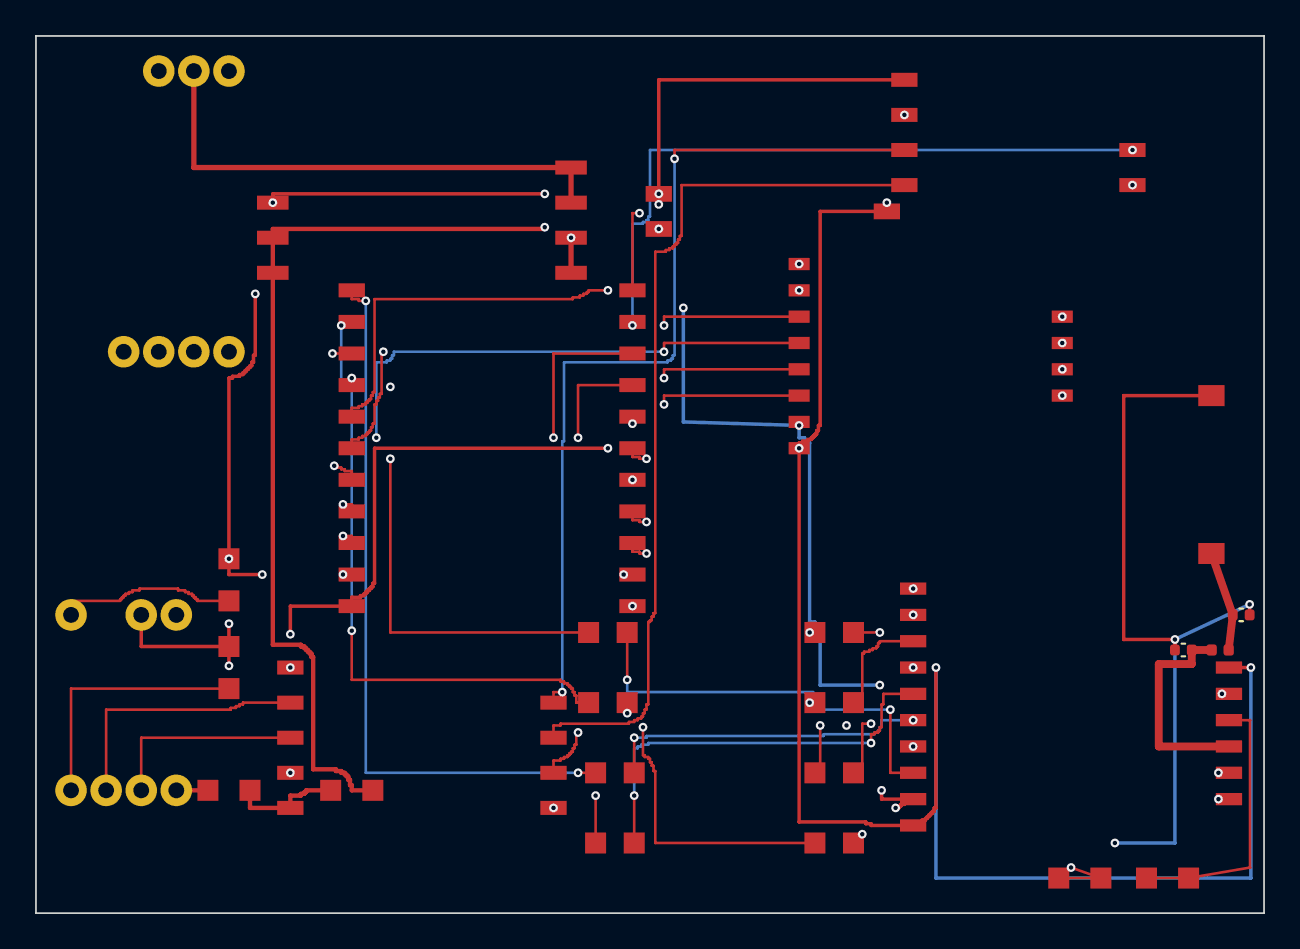
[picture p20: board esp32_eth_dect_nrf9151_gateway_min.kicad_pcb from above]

Board: 4 copper layers, 70.0 x 50.0 mm, 27 parts (0 on the bottom side), 50 nets.

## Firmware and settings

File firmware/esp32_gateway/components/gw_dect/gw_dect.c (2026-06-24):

#include "gw_dect.h"

#include <ctype.h>
#include <string.h>

#include "driver/gpio.h"
#include "driver/spi_master.h"
#include "driver/uart.h"
#include "esp_check.h"
#include "esp_log.h"
#include "freertos/FreeRTOS.h"
#include "freertos/semphr.h"
#include "freertos/task.h"

static const char *TAG = "gw_dect";

#define RX_LINE_MAX 1024

static gw_dect_rx_cb_t s_rx_cb;
static void *s_rx_ctx;
static SemaphoreHandle_t s_at_ok_sem;

static TaskHandle_t s_rx_task;

#if CONFIG_GW_DECT_HOST_IF_SPI
static spi_device_handle_t s_spi;
static bool s_spi_bus_init;
#endif

static void publish_payload_line(const char *line)
{
    if (line == NULL) {
        return;
    }

    while (isspace((unsigned char)*line)) {
        line++;
    }

    if (strncmp(line, "OK", 2) == 0) {
        if (s_at_ok_sem) {
            xSemaphoreGive(s_at_ok_sem);
        }
        return;
    }

    if (strncmp(line, "ERROR", 5) == 0) {
        ESP_LOGW(TAG, "Modem returned ERROR");
        return;
    }

    const char *prefix = CONFIG_GW_DECT_RX_PREFIX;
    bool should_forward = true;
    if (prefix != NULL && prefix[0] != '\0') {
        size_t prefix_len = strlen(prefix);
        if (strncmp(line, prefix, prefix_len) == 0) {
            line += prefix_len;
            while (isspace((unsigned char)*line)) {
                line++;
            }
        } else {
            should_forward = false;
        }
    }

    if (should_forward && line[0] != '\0' && s_rx_cb != NULL) {
        s_rx_cb(line, strlen(line), s_rx_ctx);
    }
}

#if CONFIG_GW_DECT_HOST_IF_UART
static esp_err_t iface_write(const uint8_t *data, size_t len)
{
    int wr = uart_write_bytes(CONFIG_GW_DECT_UART_PORT_NUM, data, len);
    return (wr == (int)len) ? ESP_OK : ESP_FAIL;
}

static void uart_rx_task(void *arg)
{
    (void)arg;

    uint8_t chunk[128];
    char line[RX_LINE_MAX];
    size_t line_len = 0;

    while (1) {
        int rd = uart_read_bytes(CONFIG_GW_DECT_UART_PORT_NUM, chunk, sizeof(chunk), pdMS_TO_TICKS(100));
        if (rd <= 0) {
            continue;
        }

        for (int i = 0; i < rd; ++i) {
            char c = (char)chunk[i];
            if (c == '\r') {
                continue;
            }
            if (c == '\n') {
                if (line_len > 0) {
                    line[line_len] = '\0';
                    publish_payload_line(line);
                    line_len = 0;
                }
                continue;
            }
            if (line_len < (sizeof(line) - 1)) {
                line[line_len++] = c;
            }
        }
    }
}

static esp_err_t iface_init(void)
{
    uart_config_t cfg = {
        .baud_rate = CONFIG_GW_DECT_UART_BAUDRATE,
        .data_bits = UART_DATA_8_BITS,
        .parity = UART_PARITY_DISABLE,
        .stop_bits = UART_STOP_BITS_1,
        .flow_ctrl = UART_HW_FLOWCTRL_DISABLE,
        .source_clk = UART_SCLK_APB,
    };

    ESP_RETURN_ON_ERROR(uart_driver_install(CONFIG_GW_DECT_UART_PORT_NUM, 2048, 0, 0, NULL, 0), TAG,
                        "uart_driver_install failed");
    ESP_RETURN_ON_ERROR(uart_param_config(CONFIG_GW_DECT_UART_PORT_NUM, &cfg), TAG,
                        "uart_param_config failed");
    ESP_RETURN_ON_ERROR(
        uart_set_pin(CONFIG_GW_DECT_UART_PORT_NUM, CONFIG_GW_DECT_UART_TX_GPIO,
                     CONFIG_GW_DECT_UART_RX_GPIO, UART_PIN_NO_CHANGE, UART_PIN_NO_CHANGE),
        TAG, "uart_set_pin failed");

    xTaskCreate(uart_rx_task, "gw_dect_uart_rx", 4096, NULL, 10, &s_rx_task);
    return ESP_OK;
}

#else

static esp_err_t spi_xfer(const uint8_t *tx, uint8_t *rx, size_t len)
{
    spi_transaction_t t = {
        .flags = 0,
        .length = len * 8,
        .tx_buffer = tx,
        .rx_buffer = rx,
    };
    return spi_device_transmit(s_spi, &t);
}

static esp_err_t iface_write(const uint8_t *data, size_t len)
{
    return spi_xfer(data, NULL, len);
}

/*
 * Assumption for SPI bridge FW on nRF9151:
 * - Full-duplex byte stream.
 * - RX payload is emitted as ASCII lines ending with '\n'.
 * - ESP32 master polls by clocking dummy bytes.
 */
static void spi_rx_task(void *arg)
{
    (void)arg;

    uint8_t tx[CONFIG_GW_DECT_SPI_POLL_BYTES];
    uint8_t rx[CONFIG_GW_DECT_SPI_POLL_BYTES];
    char line[RX_LINE_MAX];
    size_t line_len = 0;

    memset(tx, 0xFF, sizeof(tx));

    while (1) {
        if (spi_xfer(tx, rx, sizeof(rx)) == ESP_OK) {
            for (size_t i = 0; i < sizeof(rx); ++i) {
                char c = (char)rx[i];
                if (c == '\0' || c == (char)0xFF) {
                    continue;
                }
                if (c == '\r') {
                    continue;
                }
                if (c == '\n') {
                    if (line_len > 0) {
                        line[line_len] = '\0';
                        publish_payload_line(line);
                        line_len = 0;
                    }
                    continue;
                }
                if (isprint((unsigned char)c) && line_len < (sizeof(line) - 1)) {
                    line[line_len++] = c;
                }
            }
        }
        vTaskDelay(pdMS_TO_TICKS(20));
    }
}

static esp_err_t iface_init(void)
{
    spi_bus_config_t buscfg = {
        .mosi_io_num = CONFIG_GW_DECT_SPI_MOSI_GPIO,
        .miso_io_num = CONFIG_GW_DECT_SPI_MISO_GPIO,
        .sclk_io_num = CONFIG_GW_DECT_SPI_SCLK_GPIO,
        .quadwp_io_num = -1,
        .quadhd_io_num = -1,
        .max_transfer_sz = 1024,
    };

    if (!s_spi_bus_init) {
        ESP_RETURN_ON_ERROR(spi_bus_initialize(SPI3_HOST, &buscfg, SPI_DMA_CH_AUTO), TAG,
                            "spi_bus_initialize failed");
        s_spi_bus_init = true;
    }

    spi_device_interface_config_t devcfg = {
        .mode = 0,
        .clock_speed_hz = CONFIG_GW_DECT_SPI_CLOCK_MHZ * 1000 * 1000,
        .spics_io_num = CONFIG_GW_DECT_SPI_CS_GPIO,
        .queue_size = 2,
    };

    ESP_RETURN_ON_ERROR(spi_bus_add_device(SPI3_HOST, &devcfg, &s_spi), TAG,
                        "spi_bus_add_device failed");

    xTaskCreate(spi_rx_task, "gw_dect_spi_rx", 4096, NULL, 10, &s_rx_task);
    return ESP_OK;
}
#endif

static esp_err_t send_line(const char *line)
{
    if (line == NULL) {
        return ESP_ERR_INVALID_ARG;
    }

    size_t n = strlen(line);
    if (n == 0) {
        return ESP_OK;
    }

    ESP_RETURN_ON_ERROR(iface_write((const uint8_t *)line, n), TAG, "iface_write line failed");
    ESP_RETURN_ON_ERROR(iface_write((const uint8_t *)"\r\n", 2), TAG, "iface_write CRLF failed");
    return ESP_OK;
}
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

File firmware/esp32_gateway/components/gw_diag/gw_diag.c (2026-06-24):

#include "gw_diag.h"

#include <ctype.h>
#include <errno.h>
#include <inttypes.h>
#include <stdbool.h>
#include <stdio.h>
#include <stdlib.h>
#include <string.h>
#include <sys/socket.h>
#include <unistd.h>

#include "driver/gpio.h"
#include "esp_check.h"
#include "esp_log.h"
#include "esp_netif.h"
#include "esp_system.h"
#include "esp_timer.h"
#include "freertos/FreeRTOS.h"
#include "freertos/task.h"
#include "gw_bridge.h"
#include "gw_dect.h"
#include "gw_eth.h"
#include "lwip/inet.h"

static const char *TAG = "gw_diag";

static uint32_t s_eth_rand_seq;
static uint32_t s_dect_rand_seq;

static void print_line(const char *line)
{
    printf("GWDBG %s\n", line);
    fflush(stdout);
}

static void print_help(void)
{
    print_line("commands:");
    print_line("  help");
    print_line("  status");
    print_line("  bridge_stats");
    print_line("  reset_stats");
    print_line("  at");
    print_line("  poe");
    print_line("  set_peer <ipv4> <port>");
    print_line("  rand_eth <count>");
    print_line("  rand_dect <count>");
    print_line("  fw_update");
    print_line("  reboot");
}

static int parse_positive_int(const char *s)
{
    if (s == NULL || s[0] == '\0') {
        return -1;
    }

    char *end = NULL;
    long v = strtol(s, &end, 10);
    if (end == s || *end != '\0' || v <= 0 || v > 100000) {
        return -1;
    }
    return (int)v;
}

static void make_random_json(const char *dir, uint32_t seq, char *out, size_t out_len)
{
    uint32_t rnd = esp_random();
    int64_t ms = esp_timer_get_time() / 1000;
    snprintf(out, out_len,
             "{\"src\":\"%s\",\"seq\":%" PRIu32 ",\"rnd\":%" PRIu32 ",\"ts_ms\":%" PRIi64 "}",
             dir, seq, rnd, ms);
}

static esp_err_t send_udp_to_gateway(const char *payload, size_t payload_len)
{
    if (!gw_eth_has_ip()) {
        return ESP_ERR_INVALID_STATE;
    }

    esp_ip4_addr_t ip;
    ESP_RETURN_ON_ERROR(gw_eth_get_ipv4(&ip), TAG, "gw_eth_get_ipv4 failed");

    int sock = socket(AF_INET, SOCK_DGRAM, IPPROTO_IP);
    if (sock < 0) {
        return ESP_FAIL;
    }

    struct sockaddr_in to = {
        .sin_family = AF_INET,
        .sin_port = htons(CONFIG_GW_UDP_LISTEN_PORT),
        .sin_addr.s_addr = ip.addr,
    };

    int wr = sendto(sock, payload, payload_len, 0, (struct sockaddr *)&to, sizeof(to));
    close(sock);

    return (wr == (int)payload_len) ? ESP_OK : ESP_FAIL;
}

static void print_bridge_stats(void)
{
    gw_bridge_stats_t st = { 0 };
    if (gw_bridge_get_stats(&st) != ESP_OK) {
        print_line("bridge_stats error");
        return;
    }

    printf("GWDBG bridge eth_rx=%" PRIu64 " eth_to_dect=%" PRIu64
           " eth_err=%" PRIu64 " dect_rx=%" PRIu64
           " dect_to_eth=%" PRIu64 " dect_err=%" PRIu64 "\n",
           st.eth_rx_packets,
           st.eth_to_dect_packets,
           st.eth_to_dect_errors,
           st.dect_rx_packets,
           st.dect_to_eth_packets,
           st.dect_to_eth_errors);
    fflush(stdout);
}

static void cmd_status(void)
{
    char ipbuf[20] = "0.0.0.0";
    if (gw_eth_has_ip()) {
        esp_ip4_addr_t ip;
        if (gw_eth_get_ipv4(&ip) == ESP_OK) {
            esp_ip4addr_ntoa(&ip, ipbuf, sizeof(ipbuf));
        }
    }

    esp_err_t at = gw_dect_healthcheck();

    printf("GWDBG status eth_link=%s eth_ip=%s at=%s reset_reason=%d uptime_ms=%" PRIi64 "\n",
           gw_eth_link_up() ? "up" : "down",
           ipbuf,
           (at == ESP_OK) ? "ok" : "fail",
           (int)esp_reset_reason(),
           esp_timer_get_time() / 1000);
    fflush(stdout);

    print_bridge_stats();
}

static void cmd_poe(void)
{
#if CONFIG_GW_POE_PGOOD_GPIO < 0
    print_line("poe_pgood: not configured (set CONFIG_GW_POE_PGOOD_GPIO)");
#else
    int lvl = gpio_get_level(CONFIG_GW_POE_PGOOD_GPIO);
    bool ok = (lvl == CONFIG_GW_POE_PGOOD_ACTIVE_LEVEL);
    printf("GWDBG poe_pgood gpio=%d level=%d expected=%d result=%s\n",
           CONFIG_GW_POE_PGOOD_GPIO,
           lvl,
           CONFIG_GW_POE_PGOOD_ACTIVE_LEVEL,
           ok ? "ok" : "fail");
    fflush(stdout);
#endif
}

static void cmd_at(void)
{
    esp_err_t err = gw_dect_healthcheck();
    printf("GWDBG at %s\n", (err == ESP_OK) ? "ok" : esp_err_to_name(err));
    fflush(stdout);
}

static void cmd_set_peer(const char *ip, const char *port_str)
{
    int port = parse_positive_int(port_str);
    if (ip == NULL || port < 1 || port > 65535) {
        print_line("set_peer usage: set_peer <ipv4> <port>");
        return;
    }

    esp_err_t err = gw_bridge_set_runtime_peer(ip, (uint16_t)port);
    printf("GWDBG set_peer %s\n", (err == ESP_OK) ? "ok" : esp_err_to_name(err));
    fflush(stdout);
}

static void run_eth_random_burst(int count)
{
    char json[192];
    int ok = 0;

    for (int i = 0; i < count; ++i) {
        make_random_json("eth_in", ++s_eth_rand_seq, json, sizeof(json));
        if (send_udp_to_gateway(json, strlen(json)) == ESP_OK) {
            ok++;
        }
        vTaskDelay(pdMS_TO_TICKS(10));
    }

    printf("GWDBG rand_eth sent=%d req=%d\n", ok, count);
    fflush(stdout);
}

static void run_dect_random_burst(int count)
{
    char json[192];
    char line[256];
    int ok = 0;

    for (int i = 0; i < count; ++i) {
        make_random_json("dect_in", ++s_dect_rand_seq, json, sizeof(json));

        if (CONFIG_GW_DECT_RX_PREFIX[0] != '\0') {
            int wr = snprintf(line, sizeof(line), "%s%s", CONFIG_GW_DECT_RX_PREFIX, json);
            if (wr <= 0 || wr >= (int)sizeof(line)) {
                continue;
            }
            if (gw_dect_test_inject_rx_line(line) == ESP_OK) {
                ok++;
            }
        } else {
            if (gw_dect_test_inject_rx_line(json) == ESP_OK) {
                ok++;
            }
        }

        vTaskDelay(pdMS_TO_TICKS(10));
    }

    printf("GWDBG rand_dect injected=%d req=%d\n", ok, count);
    fflush(stdout);
}

static void cmd_rand_eth(const char *count_str)
{
    int count = parse_positive_int(count_str);
    if (count < 1 || count > 1000) {
        print_line("rand_eth usage: rand_eth <count:1..1000>");
        return;
    }
    run_eth_random_burst(count);
}

static void cmd_rand_dect(const char *count_str)
{
    int count = parse_positive_int(count_str);
    if (count < 1 || count > 1000) {
        print_line("rand_dect usage: rand_dect <count:1..1000>");
        return;
    }
    run_dect_random_burst(count);
}

static void cmd_fw_update(void)
{
    print_line("USB firmware update:");
    print_line("1) source /Users/antonio/esp/esp-idf/export.sh");
    print_line("2) cd firmware/esp32_gateway");
    print_line("3) idf.py -p <USB_PORT> flash monitor");
    print_line("4) optional: use tools/usb_debug/flash_usb.sh <USB_PORT>");
}
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

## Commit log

2026-06-24 Subir proyecto correspondiente a la memoria final de prácticas
    [Ag9900.step, NRF9151-LACA-R.STEP, bom_2026-04-22.csv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]
2026-06-24 corregir errores y actualizar salida de build
2026-06-24 Añadir README.md y código fuente de la memoria al repositorio
2026-06-26 Añadir resultados de flash y flash monitor
2026-06-26 Añadir descripción de funciones
2026-06-26 Actualización memoria de prácticas
